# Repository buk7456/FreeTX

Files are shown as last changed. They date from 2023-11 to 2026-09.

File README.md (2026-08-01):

# FreeTX
Open source radio control system for almost anything.  
Remotely operate model airplanes, multicopters, helicopters, boats, land vehicles, robots, animatronics, etc.

## Main features
- 20 fully proportional RC channels, each encoded with 10 bits.
- Configurable RC channel output signal format.
- Update rate of 50x per second for all RC channels.
- Receiver binding, adjustable RF power, frequency hopping.
- Reverse, subtrim, endpoints, failsafe, dual rates and expo, custom curves, flight modes.
- Powerful mixer system, logical switches, function generators, counters, timers.
- Telemetry, alarms, warnings, notifications, home screen widgets, custom splash screen, etc.
- Model memory, I2C EEPROM and SD card supported. Model types, context-aware nomenclature.
- Intuitive user interface.

## Hardware and Schematics
The transmitter and receiver schematics can be found in the 'schematics' folder. 
The major components are
- 1x Atmega2560 microcontroller, 2x Atmega328p microcontrollers.
- 2x SX1276/77/78/79 or RFM95 based Lora modules. Other RF modules can possibly be used with some modifications to the source code.
- A 128x64 graphical LCD with KS0108 or ST7920 controller. Any other 128x64 LCD can however be used (provide own driver code).

<p align="left">
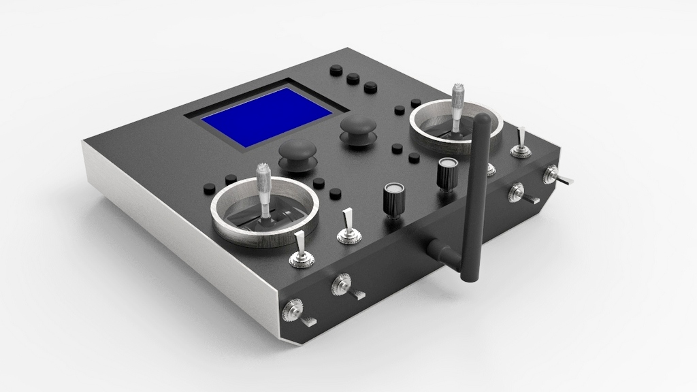
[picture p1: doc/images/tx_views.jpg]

</p>

## User interface
Three buttons are used for navigating the user interface i.e. Up, Select, Down. Long press Select to go Back.
<p align="left">

</p>

## User guide
[User guide](doc/user_guide.md)  

A PDF version is also available [here.](https://raw.githubusercontent.com/buk7456/FreeTX/main/doc/FreeTX%20-%20User%20manual.pdf)

## Gallery

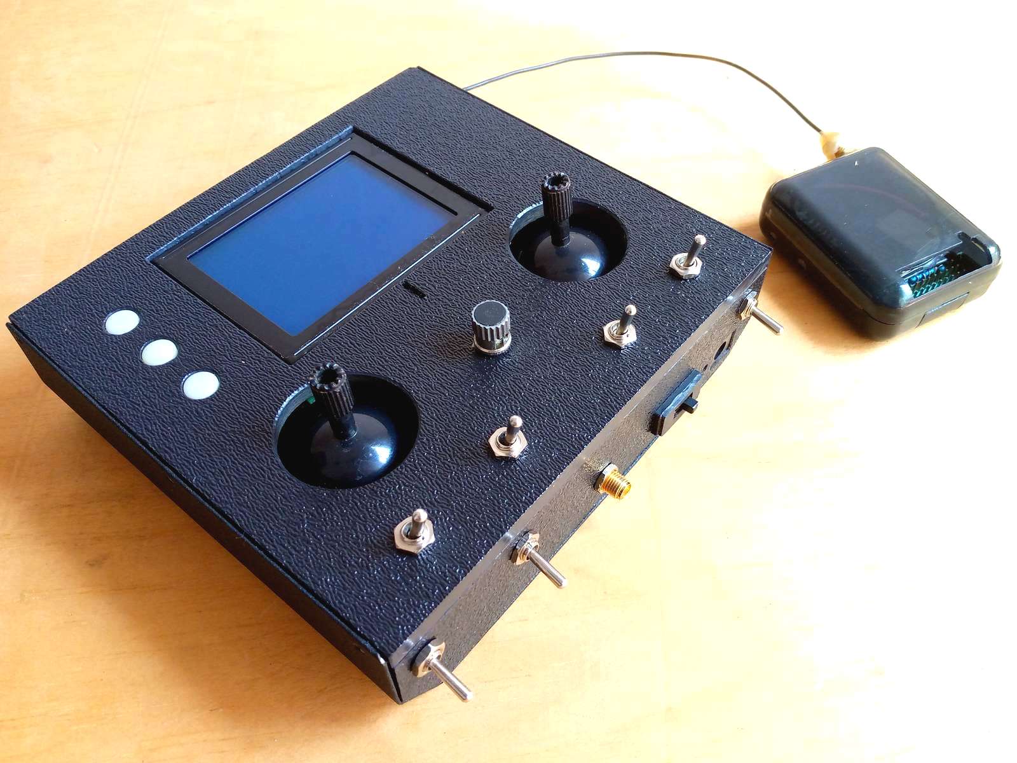
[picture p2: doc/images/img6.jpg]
[](doc/images/img6.jpg)
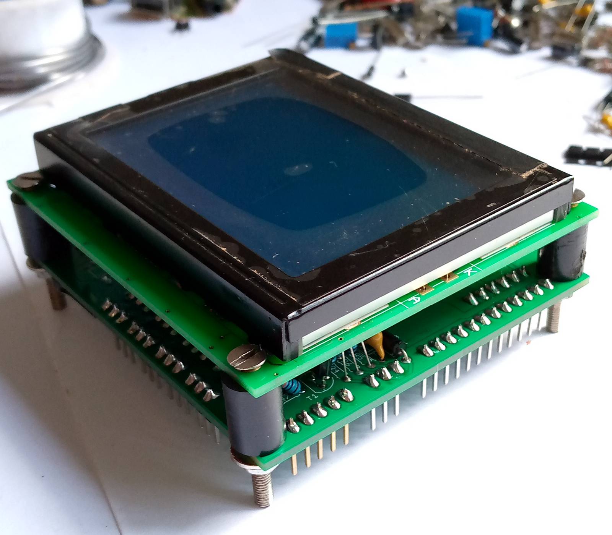
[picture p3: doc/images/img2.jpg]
[](doc/images/img2.jpg)
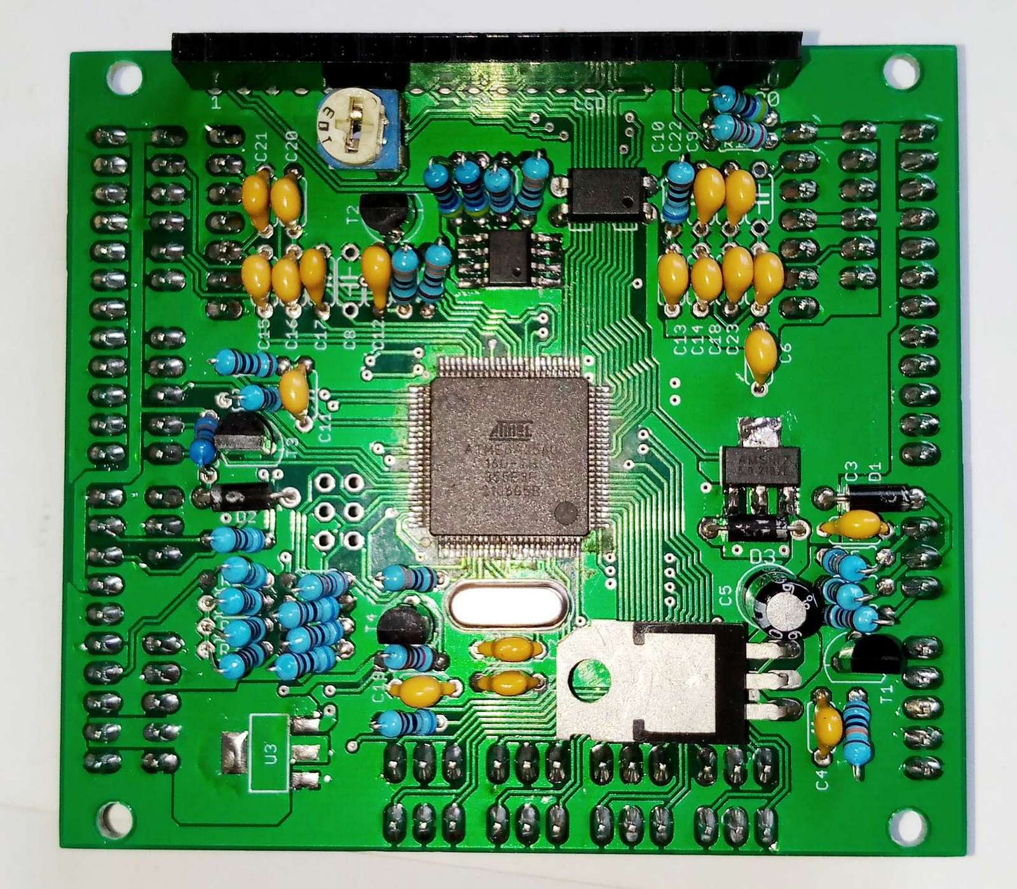
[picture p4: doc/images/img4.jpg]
[](doc/images/img4.jpg)
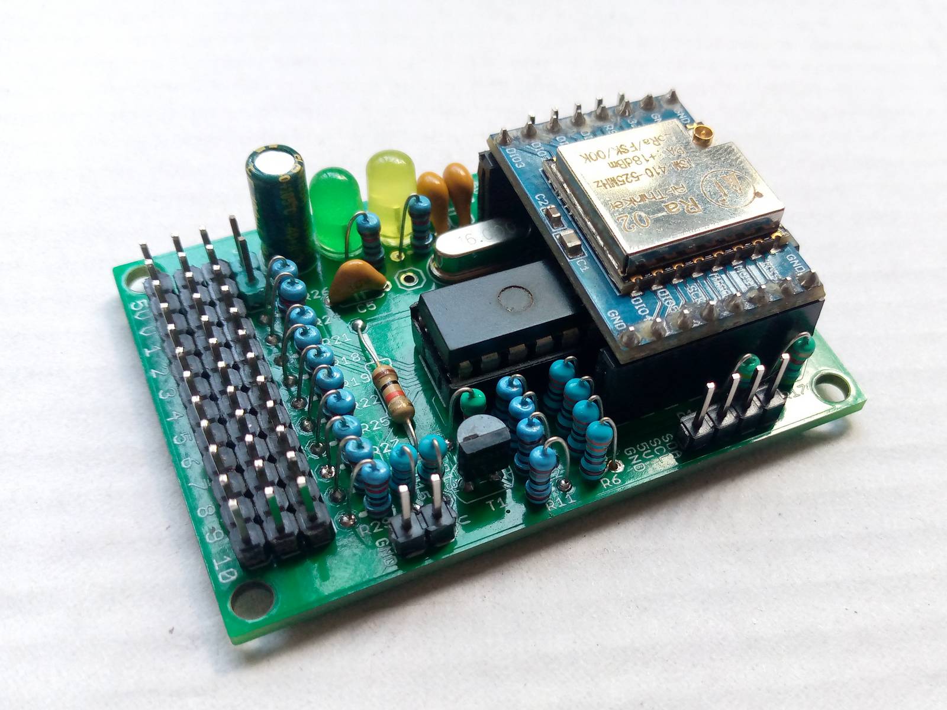
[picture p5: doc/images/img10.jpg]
[](doc/images/img10.jpg)
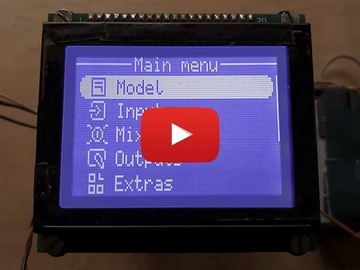
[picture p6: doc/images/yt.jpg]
[](https://www.youtube.com/watch?v=rDpRMRE8av0)
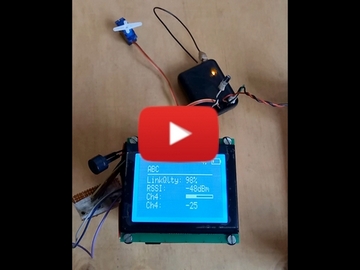
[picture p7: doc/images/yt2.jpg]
[](https://www.youtube.com/watch?v=9EZkyRHkMpg)

## Frequently Asked Questions
Got a question? [See the FAQ.](doc/faq.md)  

---

This project is based on an older project found [here.](https://github.com/buk7456/Arduino-LoRa-RC-transmitter-and-reciever)

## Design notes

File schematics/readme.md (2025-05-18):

This folder contains the EAGLE circuit schematics for the RC transmitter and receiver.

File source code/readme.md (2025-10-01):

This folder contains the source code of the firmware for the main (mtx) and secondary (stx) transmitter microcontrollers, as well as the receiver microcontroller.  
The code compiles on Arduino IDE 1.8.x or later. The code is self-contained so doesn't require installing any libraries.  
I highly recommend browsing or editing the code with an editor such as Visual Studio Code or Notepad++.  
If you are using the legacy Arduino 1.8.x IDE, you need to enable the "Use external editor" option.  
For VScode, simply open the folder (e.g. mtx) as project. For notepad++, use the "Open folder as workspace".

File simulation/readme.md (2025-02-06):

This folder contains the simulation file for use with SimulIDE circuit simulator.  
A Proteus VSM project file is also provided. Do not use the premade hex file with it, rather compile the main transmitter code and load it into Proteus.

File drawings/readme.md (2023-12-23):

Basic mechanical stuff. No detailed mechanical CAD files provided because of non-standard parts.  
Plan layouts for the front plate of the transmitter are provided only for guidance.

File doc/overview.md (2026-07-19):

# Overview

FreeTX is an open-source radio control system you can use for just about anything. It combines features from different RC systems and brings in new ideas too. It’s perfect for creators, hobbyists, and engineers. The main goal is to give you more freedom and choice with what you want to do.

## Default configuration

By default, the system is configured with the following features.

- 10 stick input axes, 8 switches, 2 knobs
- 40 mixer slots, 20 proportional RC channels
- 10 custom curves, 10 max points per curve
- 20 logical switches, 5 function generators, 3 timers, 5 counters
- 10 custom notifications 
- 5 flight modes
- 8 telemetry sensor slots

Many of these numbers are easily customisable in the source code, the limit being the available memory and I/O pins. 

## System architecture

### Transmitter hardware block diagram

<p align="left">
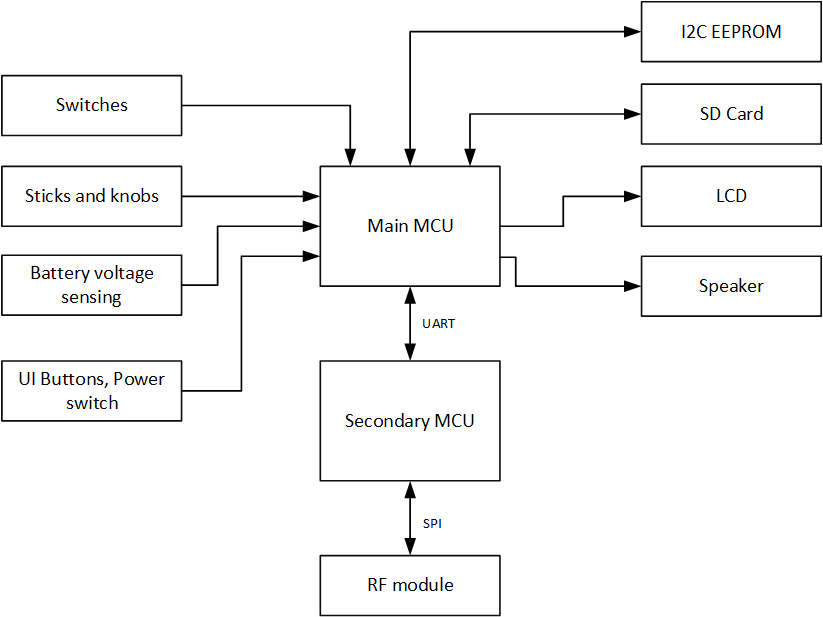
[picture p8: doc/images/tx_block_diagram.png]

</p>

### Receiver hardware block diagram

<p align="left">
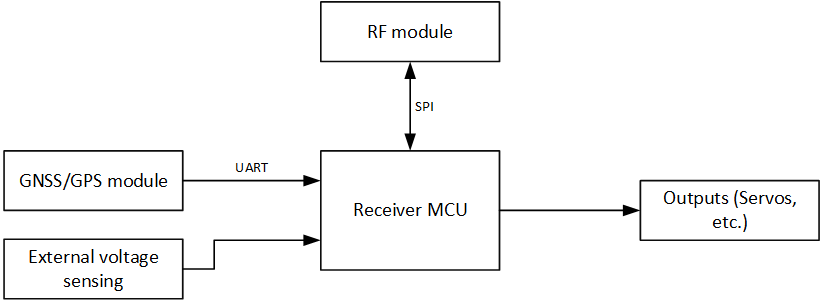
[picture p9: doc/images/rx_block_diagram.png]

</p>

## RF protocol

A custom RF protocol is used to communicate between the transmitter and receiver. The implementation builds on top of LoRa(R) transceivers. The documentation can be found in the Protocols folder.  
The main features are:-
- 10 bit encoding for all RC channels
- 50 Hz update rate for all RC channels
- Frequency Hopping Spread Spectrum
- Telemetry support

---

Back to [user guide](user_guide.md).

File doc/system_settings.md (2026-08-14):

# System settings

The System menu provides comprehensive configuration options so you can tailor the device to your needs. Settings are organized into categories for easy navigation and quick access to the options you want. Use this menu to adjust settings that affect overall system operation.

<p align="left">
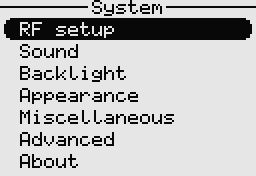
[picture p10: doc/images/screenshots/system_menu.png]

</p>

- [RF setup](#section_id_rf_setup)  
- [Sound](#section_id_sound)  
- [Backlight](#section_id_backlight)  
- [Appearance](#section_id_appearance)  
- [Miscellaneous](#section_id_miscellaneous)  
- [Advanced](#section_id_advanced_settings)  
  - [Sticks](#section_id_sticks)  
  - [Knobs](#section_id_knobs)  
  - [Switches](#section_id_switches)  
  - [Battery](#section_id_battery)  
  - [Security](#section_id_security)  
  - [Debug](#section_id_debug)  
- [About](#section_id_about)

## RF setup 

<p align="left">
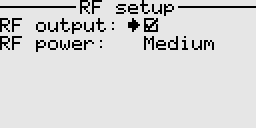
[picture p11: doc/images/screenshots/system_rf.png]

</p>

- **RF output:** Toggle the RF transceiver on or off. When enabled, an RF icon appears on the home screen. RF output is automatically disabled when switching to a different model for safety, thus it has to be re-enabled manually after changing models.
- **RF power:** Adjust the transceiver's transmission power. Higher power increases range but uses more battery.

## Sound

<p align="left">
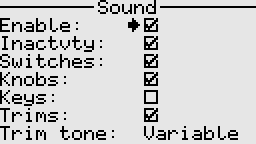
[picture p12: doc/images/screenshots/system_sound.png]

</p>

- **Enable:** Toggle all sounds on or off. When off, a mute icon appears on the home screen. Holding the Down key while powering on will also mute all sounds.
- **Inactivity:** Turn the inactivity alarm on or off. When enabled, a warning tone plays after a period without user interaction.
- **Switches:** Play a tone when any physical switch is moved.
- **Knobs:** Play a tone when a knob with a center detent is positioned at center.
- **Keys:** Play a tone when the physical UI buttons are pressed.
- **Trims:** Play a tone while trims are being adjusted.
- **Trim tone:** Set the trim tone behaviour. Fixed pitch (single frequency) or Variable pitch (changes with trim position).

## Backlight

<p align="left">
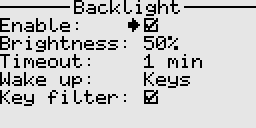
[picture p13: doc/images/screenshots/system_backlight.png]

</p>

- **Enable:** Enables/disables the backlight. This may be useful for example to save energy on certain kinds of LCDs.
- **Brightness:** Controls the brightness level of the display. Higher brightness causes higher battery consumption.
- **Timeout:** Specifies the time before the backlight is turned off when the handset is inactive.
- **Wake up:** Specifies how the backlight is triggered on. Keys or Activity. When set to Keys, only the UI keys can wake up the backlight. Setting to Activity enables all the physical controls to wake up the backlight. This is useful when we want the backlight to stay on when operating a model, especially for LCDs that are not sunlight readable.
- **Key filter:** When enabled, the first key press only wakes the backlight without triggering any event in the User Interface. This setting is useful for LCDs that are not sunlight readable.

## Appearance

<p align="left">
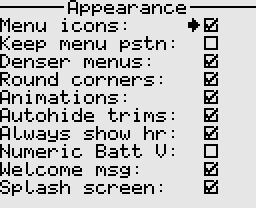
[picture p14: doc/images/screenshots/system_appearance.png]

</p>

- **Menu icons:** Show or hide icons in the main menu.
- **Keep menu position:** Whether to remember the scroll position in the major menus (Main menu, System, Extras, etc.). This setting does not apply to context menus.
- **Denser menus:** Increases the number of entries shown in the major menus.
- **Round corners:** Turns on/off rounded corners in menus, dialog boxes, etc.
- **Animations:** Turns animations on/off for toast messages, loading spinners, etc.
- **Autohide trims:** Hides the trim bars on the home screen when the trims buttons are not being interacted with.
- **Always show hours:** Whether to always show the hours digits for timers.
- **Numeric battery voltage:** Replaces the graphical battery gauge with the actual voltage readout on the home screen.
- **Welcome message:** Turns on/off the "Welcome" message when starting up the handset. 
- **Splash screen:** Whether to show the user's custom splash screen during boot.  
To make a custom splash screen, create a monochrome bitmap image with 128x64 px resolution and save it as "SPLASH.BMP" inside the "IMAGES" folder on the SD card.

## Miscellaneous

<p align="left">
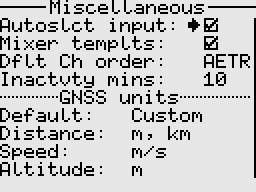
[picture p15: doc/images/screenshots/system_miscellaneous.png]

</p>

- **Autoselect input:** This enables automatic detection of the moved physical control when editing sources or switches, so that we can quickly select the desired control without having to scroll through the options.
- **Mixer templates:** Whether to enable the default mixer template when creating new models. Turning off this also removes the entry from the mixer context menu.
- **Default channel order:** Specifies the default channel order when creating new models. E.g., selecting AETR sends Ail to Ch1, Ele to Ch2, Thr to Ch3, and Rud to Ch4 in the mixer. The order can always be overridden in the mixer; this option is merely a time saving feature for new models.
- **Inactivity minutes:** How long before the inactivity event is triggered, specifically for the inactivity alarm.
- **Default GNSS units:** Specifies the default units of measurement to use when adding the GNSS telemetry sensor template.
Available options are Metric, Imperial, Custom, or None.  
When set to Custom, the user can set custom defaults for Distance, Speed, and Altitude.  
When set to None, the system prompts the user to select units whenever adding the GNSS sensor.

# Advanced settings

This menu provides access to various advanced system settings. It is protected with a password (if set) to prevent unwanted configuration changes, for instance when we lend out the transmitter. 

<p align="left">
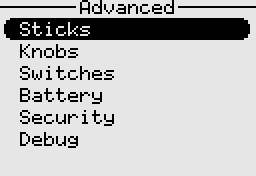
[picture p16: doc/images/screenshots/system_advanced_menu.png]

</p>

## Sticks

<p align="left">
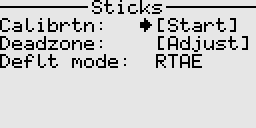
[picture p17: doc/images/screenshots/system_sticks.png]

</p>

- **Calibration:** This starts the stick calibration process.
- **Deadzone:** This allows to adjust the center deadzone for the stick axes, without re-triggering full calibration.
- **Default mode:** This determines the default stick axis mapping for the Aileron/Roll, Elevator/Pitch, Rudder/Yaw, and Throttle inputs. It is essentially called "Stick mode" in other RC systems.

### Calibrating the sticks

<p align="left">
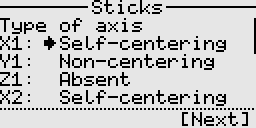
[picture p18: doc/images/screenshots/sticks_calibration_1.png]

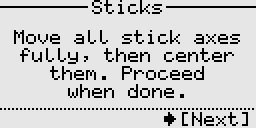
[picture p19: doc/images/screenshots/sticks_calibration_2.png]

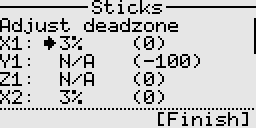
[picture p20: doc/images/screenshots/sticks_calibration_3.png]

</p>

**Procedure:**
- Select the axis type: Self-centering (returns to the center), Non-centering or Absent.
- Move each stick axis through its full range. If an axis is self-centering, release it and let it return to center.
- Set the deadzone percentage. This applies around the center to prevent jitter when the stick is centered.

Properly calibrated stick axes always read between -100 to 100 when moved fully. If this is not the case, then redo the calibration, or check your hardware.  
  
How often you need to recalibrate the sticks depends on their build quality and how frequently you use the device. As a guideline, recalibrate:
- After any noticeable drift or inconsistent input.
- After major firmware updates or hardware changes.

## Knobs

<p align="left">
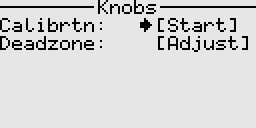
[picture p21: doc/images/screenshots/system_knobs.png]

</p>

- **Calibration:** This starts the knob calibration process.
- **Deadzone:** This allows to adjust the center deadzone for the knobs, without re-triggering full calibration.

### Calibrating the knobs

<p align="left">
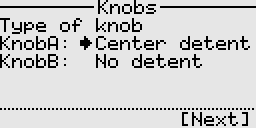
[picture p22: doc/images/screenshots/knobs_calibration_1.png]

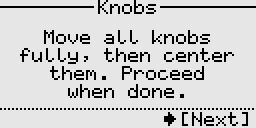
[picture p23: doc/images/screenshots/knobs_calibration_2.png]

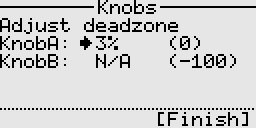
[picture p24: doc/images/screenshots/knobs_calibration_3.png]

</p>

**Procedure:**
- Select the knob type: Center detent (mechanical stop at center), No detent, or Absent.
- Rotate each knob through its full range. If a knob has a center detent, return it to the detent position.
- Set the deadzone percentage. Deadzone is applied around the center to prevent jitter when the knob is centered.

Properly calibrated knobs always read between -100 to 100 when moved fully. If this is not the case, then redo the calibration, or check your hardware.

## Switches

This screen allows the user to specify the type of switches they have installed. Supported types are 2 position, 3 position, and their momentary variants. A frequent question is "How about push buttons?". Well, they are actually 2 position momentary switches.

<p align="left">
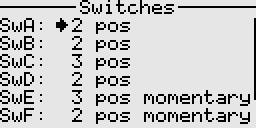
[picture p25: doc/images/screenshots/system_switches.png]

</p>

## Battery

<p align="left">
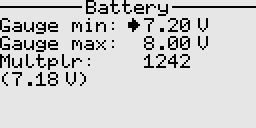
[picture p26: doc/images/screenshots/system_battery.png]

</p>

- **Gauge min and max:** These determine the range of the transmitter battery gauge. The minimum value also serves at the alarm threshold value, below which a low battery warning is shown. 
- **Multiplier:** This specifies the calibration factor for the transmitter battery voltage.

### Calibrating the battery gauge
To calibrate the battery gauge, use a digital multimeter to measure the actual battery voltage at the terminals. Then adjust the multiplier until the displayed voltage on the transmitter matches what the multimeter is showing. 

## Security
<p align="left">
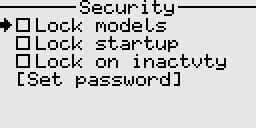
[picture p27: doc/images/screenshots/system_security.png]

</p>

- **Lock models:** Locks the model manager screen, preventing access to the models.
- **Lock startup:** Locks the main menu on startup, effectively preventing changes to all settings (both model and system), unless the correct password is entered.
- **Lock on inactivity:** Locks the main menu after the system has been idle for the specified inactivity minutes. This setting applies only while the home screen is being displayed.
- **Set/Change password:** Opens the text edit dialog to edit the password. To remove the existing password, simply clear the field. Setting a password also protects the Advanced system menu.

## Debug

The Debug menu contains options intended primarily for troubleshooting, development, testing, and debugging.

<p align="left">
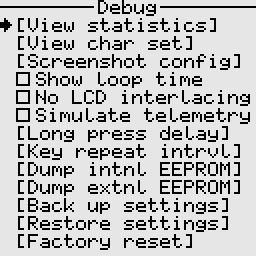
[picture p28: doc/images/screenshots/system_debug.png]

</p>

- **View statistics:** Displays basic system statistics, including system uptime, available free memory, and RF packet rate.
- **View character set:** Displays all glyphs included in the system font.
- **Screenshot configuration:** Assigns a physical switch to trigger screenshot capture.
- **Show loop time:** Displays the total execution time of the main program loop, measured in milliseconds.
- **No LCD interlacing:** Disables interlacing for the LCD screen. (Interlacing improves performance on slower displays by splitting the image into alternate frames and updating them across successive program loops.)
- **Simulate telemetry:** Simulates telemetry data on sensor ID 0x30 for testing purposes.
- **Long press delay:** Sets the duration that a physical button must be held before a long-press event is recognized. This setting applies to both UI buttons and trim buttons.
- **Key repeat interval:** Sets the time interval between repeated key events when scrolling through menus and some options, effectively determining the scrolling speed.
- **Dump EEPROM:** Displays a hexadecimal dump of the EEPROM contents.
- **Back up settings:** Backs up system settings to the SD card. Model-specific settings are not included in this backup.
- **Restore settings:** Restores system settings from the SD card.
- **Factory reset:** Erases all system and model settings, restoring the device to its factory default state. Only data in the EEPROM gets erased; data on the SD card is not affected.

## About

The About menu provides information regarding firmware version, legal notices, credits, and support/contact resources.

<p align="left">
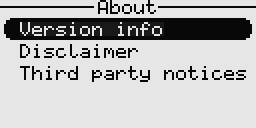
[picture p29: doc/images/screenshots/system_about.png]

</p>

---

Back to [user guide](user_guide.md).

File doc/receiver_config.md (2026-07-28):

# Receiver 
Each receiver supports up to 10 channels. To use all the 20 channels, two receivers are required.

<p align="left">
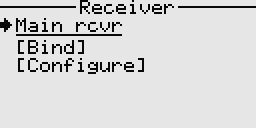
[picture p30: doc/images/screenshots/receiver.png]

</p>

## Binding to a receiver
A receiver can be bound as either a main receiver or a secondary receiver.  
By default, RC channels 1 to 10 are handled by the main receiver, while RC channels 11 to 20 are handled by the secondary receiver. Only the main receiver can send back telemetry.  
To bind, select the bind option, then cycle the power to the receiver. If the binding is successful, a "Success" toast message will be shown and a tune played.

## Configuring receiver outputs
The receiver outputs can be configured from the transmitter to any of the three signal types; 
servo PWM, digital on-off, or 'normal' PWM. 
For example 'normal' PWM output can be used to control brushed DC motors without the need for 
complex electronics. The digital on-off output makes it easy to directly control components such as 
electromechanical relays and lights.  
The servo PWM range can as well be adjusted to get extra travel from a servo, without making physical
modifications to the servo.

<p align="left">
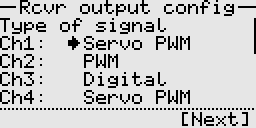
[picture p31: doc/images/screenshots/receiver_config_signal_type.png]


</p>

**Note:**  
1. These configuration settings are stored in the receiver, not the transmitter.
2. Normal PWM is only available on certain pins, depending on the pin mapping.
3. Any changes made take effect immediately upon pressing the 'Write' button.
4. In digital on-off mode, the output value range of -100 to -50 corresponds to LOW, -49 to 49 is 
ignored, and 50 to 100 corresponds to HIGH.
5. When reusing a receiver between models, always check and set the appropriate signal format before connecting 
any actuators to the receiver.

---

Back to [user guide](user_guide.md).

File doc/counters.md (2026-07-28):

# Counters
A counter stores and shows the number of times a particular event has occurred, in relationship to a clock signal.

<p align="left">


</p>

- **Clock:** The control switch that triggers the counter.
- **Edge:** Rising, Falling, or Dual edge triggering. Applies to the clock signal.
- **Clear:** The control switch that clears the counter register to zero.
- **Modulus:** The number of states in its count sequence. E.g. mod 4 produces the sequence 0, 1, 2, 3.
- **Direction:** Determines whether counts will increment or decrement.
- **Rollover:** Rolls back over to start counting again from zero.
- **Persist:** Whether to remember the value in the counter's register between sessions.

In advanced mode, the counter behaves as an up/down counter using separate "up" and "down" clocks for increment and decrement respectively.

## Usage examples
[1. Using a 3 position momentary switch to sequentially select among values](#section_id_select_among_values_with_momentary_switch)  
[2. Using a 3 position momentary switch to continuously adjust a value](#section_id_continuously_adjust_value_with_momentary_switch)  

### Example 1: Using a 3 position momentary switch to sequentially select among values
This example demonstrates use of the counter directly inside the mixer.  
When the momentary switch is pushed in the downward direction, the counter value increments. Similarly, pushing the momentary switch in the opposite direction decrements the counter value.  
In the counter screen context menu, change the counter type to advanced.  
Assuming SwG is our 3 position momentary switch, set up the counter as follows.

```txt
Counter1
Inc clock:  SwG_down
Inc edge:   Rising
Dec clock:  SwG_up
Dec edge:   Rising
Modulus:    4
Rollover:   False
```

Then in the Mixer,

```txt
1. Ch1  Add  Counter1  (Weight 100)
```

The mixer automatically maps the counter's value in proportion to the counter's modulus. For example if the modulus is 4, then mapping is {(0,-100), (1,-33), (2,33), (3,100)}.

### Example 2: Using a 3 position momentary switch to continuously adjust a value
When the switch is pushed in one direction, the counter continuously increments until the switch is released. Similarly, the counter continuously decrements
when the switch is pushed in the opposite direction.  
For this, we set up some logical switches, like so.

```txt
L1
Functn: AND
Value1: !L1
Value2: SwG_down

L2
Functn: AND
Value1: !L2
Value2: SwG_up
```

In the above, we are essentially creating ring oscillators, though with only a single NOT stage.  
This exploits the fact that the main program loop runs at about 50 times per second, thus we generate oscillations of about 25 Hz frequency.  
We then use L1 and L2 to clock the counter as follows.

```txt 
Counter1
Inc clock:  L1
Inc edge:   Rising
Dec clock:  L2
Dec edge:   Rising
Modulus:    100
Rollover:   False
```

Here, the modulus can be any value. For example if the modulus is 100, it will take 4 seconds (=100/25) to increment from 0 to 99.  

We then use the counter as input inside the Mixer like follows. 

```txt  
1. Ch1  Add  Counter1  (Weight 100)
```

The mixer automatically maps the counter's value in proportion to the counter's modulus, to the range -100 to 100.  
We can also specify some "slow up/down" of 4 seconds in the mixer to smooth the output.

Alternatively, we can adapt this example to use a self-centering stick axis like X4, instead of the momentary switch.

---

Back to [user guide](user_guide.md).

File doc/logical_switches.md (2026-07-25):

# Logical switches
These can be used to combine various conditions, compare values, etc. They are in essence user
programmed virtual switches. They produce an on/off output.

<p align="left">

</p>

The available functions can be categorized into the following types.
- Comparators (Greater than, Less than, Equal, Greater than or equal, Less than or equal)
- Combinational (AND, OR, XOR)
- Latches (SR latch)
- Flip-flops (Toggle)
- Generators (Pulse)

## Usage examples

[1. A mix activated by combination of two switches](#section_id_mix_activated_by_two_switches)  
[2. LED lights that flash when flight battery is low](#section_id_led_lights_flashing_low_battery)  
[3. Stopwatch operated by a single momentary switch](#section_id_stopwatch_with_momentary_switch)  
[4. Throttle timer - simple](#section_id_throttle_timer_simple)  
[5. Throttle timer - advanced](#section_id_throttle_timer_advanced)  
[6. Zero crossing detection](#section_id_zero_crossing_detection)  
[7. Using a momentary switch to cycle among values](#section_id_cycle_among_values_with_momentary_switch)  
[8. Detecting receiver connection or disconnection ](#section_id_detect_disconnection_of_receiver)  

### Example 1: A mix activated by combination of two switches
Suppose we want a mix to be turned on only when two switches (e.g. SwA, SwB) are both on. 
We need to set up a logical switch say L1 as follows.

```txt
L1
Functn: AND
Value1: SwA_down
Value2: SwB_down
```
Then in the mixer, we simply have to set the control switch to L1.

### Example 2: LED lights that flash when flight battery is low
Suppose we have a model that is equipped with some LED lights that we want to switch on when the flight battery
voltage (telemetry) falls below a certain threshold for more than say five seconds.
<br>We can easily achieve this like so.

```txt
L1
Functn: a<x
Value1: FlghtBatt
Value2: 10.80 V
Delay:  5.0 s

L2
Functn: Pulse
Width:  1.0 s
Period: 2.0 s
``` 
Then in the mixer, we simply use L2 as the input source and L1 as the control switch for the mix, to
operate the channel assigned to the LED lights.

### Example 3: Stopwatch operated by a single momentary switch for start/stop and reset
When the switch is clicked, the timer runs/stops. When the switch is held long enough, the timer is
reset. 
<br>For this, we set up two logical switches to operate the timer as below, assuming SwH is our momentary switch.

```txt
L1
Functn: Toggle
Clock:  SwH_down
Edge:   Falling
Clear:  L2

L2
Functn: a>x
Value1: SwH
Value2: 0
Delay:  0.5 s

Timer1
Switch: L1
Reset:  L2
```

Explanation:  
The output of L1 toggles whenever SwH is released. L1 is then used to run/stop the timer.  
L2 goes high when SwH is down for more than 0.5 seconds, providing a signal for resetting the timer.
L2 is also used to clear the state of L1 such that resetting the timer does not falsely trigger it to run on releasing the switch.

### Example 4: Throttle timer (simple)
When the throttle is moved beyond a certain threshold, the timer runs.  
Also if we have a throttle cut function on say SwA, we want the timer to only run when throttle cut is inactive.  
Assume the throttle source is the Y1 axis.

```txt
L1
Functn: a>x
Value1: Y1
Value2: -90

L2
Functn: AND
Value1: L1
Value2: SwA_down

Timer1
Switch: L2
```

### Example 5: Throttle timer (advanced)
Suppose we want the speed at which the timer runs to be proportional to the throttle value.  
Also if we have a throttle cut function on say SwA, we want the timer to only run when throttle cut is inactive.  
Assume our throttle source is the Y1 axis. 

#### Method 1: 
Using the built-in function generator to generate a pulse width modulated signal that controls the timer.

```txt
Fgen1
Waveform:   Pulse
Width mode: Variable
Modulator:  Y1
Reverse:    False
Period:     1.0 s

L1
Functn: a>x
Value1: Fgen1
Value2: 0

L2
Functn: AND
Value1: L1
Value2: SwA_down

Timer1
Switch: L2
```

Explanation:  
The throttle source (Y1 axis) is used to modulate the pulse width of the generated pulse waveform.  
Since the timer only accepts signals from control switches, we need to convert the output from the function generator. This is done via L1.  
When SwA is in the down position, the resulting signal is passed to the timer to control it.

#### Method 2:
Using the mixer and a virtual channel to create a pulse width modulated signal that controls the timer.

```txt
Mixer
1. Virt1  Add  L1 (Weight 99, SlowUp 0.5 s, SlowDown 0.5 s)

L1
Functn: Pulse
Width:  0.5 s
Period: 1.0 s

L2
Functn: a>b
Value1: Y1
Value2: Virt1

L3
Functn: AND
Value1: L2
Value2: SwA_down

Timer1
Switch: L3
```
Explanation:  
L1 and Virt1 effectively create a triangle waveform, which gets compared with the value of the throttle source (Y1 axis) via L2.
When SwA is in the down position, the resulting signal is passed to the timer to control it.

If desired, we can also include a custom curve through a virtual channel, to compensate for the real world
nonlinear relationship between current draw and throttle value. 

### Example 6: Zero crossing detection
Suppose we want to detect whenever a value from say a function generator crosses zero, so that 
we can trigger some other action.

```txt
L1
Functn: a>=x
Value1: Fgen1
Value2: 0

L2
Functn: |delta|>x
Value1: L1
Value2: 0
Dirctn: Both
```

L2 will now output a brief pulse whenever the output of the function generator crosses zero.

### Example 7: Using a momentary switch to cycle among four values or states
Suppose we want an output channel to cycle among four levels whenever we click the momentary switch.

#### Method 1:
Set up a '2-bit' binary counter with its outputs on L2 and L1 as follows.

```txt
L1
Functn: Toggle
Clock:  SwH_down
Edge:   Rising 

L2
Functn: Toggle
Clock:  L1
Edge:   Falling
```

Use a truth table to set up logical switches L3, L4, L5, and L6

| L2 | L1 | |
|----|----|----|
| 0  | 0  | L3 |
| 0  | 1  | L4 |
| 1  | 0  | L5 |
| 1  | 1  | L6 |

```txt
L3
Functn: AND
Value1: !L2
Value2: !L1

L4
Functn: AND
Value1: !L2
Value2: L1

L5
Functn: AND
Value1: L2
Value2: !L1

L6
Functn: AND
Value1: L2
Value2: L1
```

Then in the Mixer,

```txt
1. Ch1  RplcW  Max  (Weight -100,  Switch L3)
2. Ch1  RplcW  Max  (weight -33,   Switch L4)
3. Ch1  RplcW  Max  (weight  33,   Switch L5)
4. Ch1  RplcW  Max  (weight  100,  Switch L6)
```
#### Method 2:
This makes use of the built-in counter as follows.

```txt
Counter1
Clock:   SwH_down
Edge:    Rising
Modulus: 4
Dirctn:  Up

L3
Functn: a==x
Value1: Counter1
Value2: 0

L4
Functn: a==x
Value1: Counter1
Value2: 1

L5
Functn: a==x
Value1: Counter1
Value2: 2

L6
Functn: a==x
Value1: Counter1
Value2: 3
```
Then in the Mixer,

```txt
1. Ch1  RplcW  Max  (Weight -100,  Switch L3)
2. Ch1  RplcW  Max  (weight -33,   Switch L4)
3. Ch1  RplcW  Max  (weight  33,   Switch L5)
4. Ch1  RplcW  Max  (weight  100,  Switch L6)
```

#### Method 3:
This makes use of the built-in counter directly in the Mixer. [See the example](./counters.md#section_id_select_among_values_with_momentary_switch) under counters.  

### Example 8: Detecting receiver connection or disconnection
This relies on the Link Quality telemetry to detect connection/disconnection of a receiver.  
First, configure the Link Quality telemetry (premade template already available).  
Then set up a logical switch and custom notifications as follows.

```txt
L1
Functn: a>x
Value1: LinkQlty
Value2: 0

Notification1
Switch: L1
Tone:   (Your preferred tone)
Text:   RX connect

Notification2
Switch: !L1
Tone:   (Your preferred tone)
Text:   RX disconnect
```

This example can also be adapted to detect when telemetry from a sensor is lost or recovered.

---

Back to [user guide](user_guide.md).

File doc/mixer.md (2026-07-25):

# The Mixer
The mixer is where the inputs (mixer sources) get linked to the output channels (servos, etc.).
This controller features a mixer system that draws inspiration from that found in OpenTX(R) based RC transmitters, though not directly compatible.

<p align="left">


</p>

## Mixer fields
- **Output:** The channel that is to be affected by the mix. If none, the mix is inactive and is not computed.
- **Switch:** The control switch to turn the mix on or off. The mix is always active if no switch is specified.
- **Operation:** Add, Multiply, Replace with, Hold.
- **Input:** This is the mixer source.
- **Weight:** Determines how much of an effect the input has on the output. -100 to 100.
- **Offset:** The input is offset by this value after the weight has been applied. -100 to 100.
- **Curve:** Differential, Expo, Function, Custom curve.
- **Curve value:** Differential {-100 to 100}, Expo {-100 to 100}, Function {x>0, x<0, |x|}, Curve name if custom curve.
- **Trim:** Whether to add trim or not.
- **F-Mode:** The flight mode in which the mix applies.
- **Delay Up and Down:** This is used to delay the input. 0 to 60 seconds.
- **Slow Up and Down:** This when non-zero specifies how fast the input changes. 0 to 60 seconds.

## Mixer sources
Mixer sources can be any of the following:
- Raw stick axes (X1, Y1, X2, Y2, etc.)
- Processed sticks (Rud/Yaw, Thr, Ail/Roll, Ele/Pitch)
- Knobs (KnobA, KnobB)
- Constants (Max)
- Function generators (Fgen1, Fgen2, etc.)
- Trims (X1Trim, Y1Trim, X2Trim, Y2Trim)
- Physical switches (SwA, SwB, etc.)
- Logical switches (L1, L2, etc.)
- Channels (Ch1, Ch2, etc.)
- Virtual channels (Virt1, Virt2, etc.)

Counters can also be used as inputs in the mixer, although they are not classified as true mixer sources.

## Control switches
These can be used to activate or deactivate various functions, for example enabling or disabling mixes, starting or stopping timers, and more. The following control switches are available:
- Physical switches (SwA↑, SwA−, SwA↓, etc.)
- Logical switches (L1, L2, !L1, !L2, etc.)
- Trim buttons (X1Trim←, X1Trim→, Y1Trim↑, Y1Trim↓, etc.)
- Flight modes as control switches (Fmd1, Fmd2, !Fmd1, !Fmd2, etc.)

The symbols "↑", "−", and "↓" correspond to the up, middle (center), and down positions of physical switches, respectively.  
The "↑" and "↓" symbols are also used on vertical trim buttons to indicate an active upward or downward press.  
The "←", and "→" symbols also denote the left and right press states of the horizontal trim buttons.  
The "!" symbol indicates a logical NOT operator. For example, the condition "!SwC↑" evaluates as true when SwC is not in the up position.

## Order of mixer operations
<p align="left">

</p>

## Context menu actions
- **View outputs:** Opens the mixer monitor, which shows the real-time status of all output channels. Click the Select button within this monitor to view a tooltip containing the exact value of the selected channel.
- **Copy mix to:** Copies this mix to a specified destination.
- **Move mix to:** Moves this mix to a specified destination.
- **Insert free:** Inserts a free mix slot at the current position.
- **Rename mix:** Opens the text editor dialog to specify a name for this mix.
- **Reset mix:** Resets this mix to the default setting.
- **Reset all mixes:** Resets all mixes to the default settings.
- **Compact mixes:** Removes all empty/free slots that exist in-between the defined mixes.
- **Show curve preview:** Whether to draw the curve on the mixer screen. The displayed curve shows a trace of the output vs input for this specific mix.
- **Templates:** Use this option to load the predefined mixer templates.
- **Show overview:** Display a summary of the configured mixes. In the overview screen, click the Select button to display a tooltip with extra information about the highlighted mix line.

## Important safety note
When editing mixes, it is recommended to disable RF output or remove propellers first. This is because all changes/adjustments made are applied instantly and may bring surprises.

## Example mixes
**Note:** 
- The convention used in these examples is negative for left/downward going control surfaces, positive for right/upward going control surfaces. For example if the Ail stick is moved right, the left aileron moves down and the right aileron moves up. Hence we use a negative weight for the left aileron and a positive weight for the right aileron.
- If a servo is moving in wrong direction, reversing the direction in Outputs screen solves this.
- The Mixer is all about control logic. Any mechanical differences should be handled in the Outputs screen and not inside the Mixer.

[1. Basic 4 channel](#section_id_basic_4_channel)  
[2. Elevon](#section_id_elevon)  
[3. Vtail](#section_id_vtail)  
[4. Aileron differential](#section_id_aileron_differential)  
[5. Tailerons](#section_id_tailerons)  
[6. Flaperons](#section_id_flaperons)  
[7. Crow braking](#section_id_crow_braking)  
[8. Flaps working as ailerons](#section_id_flaps_as_ailerons)  
[9. Differential thrust](#section_id_differential_thrust)  
[10. Throttle elevator mixing](#section_id_throttle_elevator_mix)  
[11. Variable steering depending on throttle](#section_id_variable_steering)  
[12. Adjust idle throttle with knob](#section_id_adjust_throttle_idle)  
[13. Adjust maximum throttle with knob](#section_id_adjust_max_throttle)  
[14. Simple throttle cut](#section_id_simple_throttle_cut)  
[15. Sticky throttle cut](#section_id_stick_throttle_cut)  
[16. Landing gear sequencer](#section_id_landing_gear_sequencer_v1)  
[17. Landing gear sequencer - advanced](#section_id_landing_gear_sequencer_v2)  
[18. Servo tester](#section_id_servo_tester)  
[19. Random servo motion generator](#section_id_random_servo_motion_generator)  
[20. Random servo motion generator - advanced](#section_id_random_servo_motion_advanced)  
[21. Oscillator from scratch](#section_id_oscillator_from_scratch)  
[22. Automatic aileron rudder mixing](#section_id_automatic_aileron_rudder_mix)  
[23. Adjust aileron differential with knob](#section_id_adjust_aileron_differential_with_knob)  

### Example 1: Basic 4 channel
Assuming Aileron servo in Ch1, Elevator servo in Ch2, Throttle in Ch3, Rudder servo in Ch4
```txt
1. Ch1  Add  Ail (Weight 100)
2. Ch2  Add  Ele (Weight -100)
3. Ch3  Add  Thr (Weight 100)
4. Ch4  Add  Rud (Weight 100)
```

### Example 2: Elevon
Left servo in Ch1, right servo in Ch2
```txt
1. Ch1  Add  Ail (Weight -50)
2. Ch1  Add  Ele (Weight -50)
3. Ch2  Add  Ail (Weight 50)
4. Ch2  Add  Ele (Weight -50)
```

### Example 3: Vtail
Left servo in Ch2, right servo in Ch4
```txt
1. Ch2  Add  Rud (Weight 50)
2. Ch2  Add  Ele (Weight -50)
3. Ch4  Add  Rud (Weight -50)
4. Ch4  Add  Ele (Weight -50)
```

### Example 4: Aileron differential
Left aileron in Ch1, right aileron in Ch8. We want the downward going aileron to get less displaced
than the upward going aileron. Due to differences in lift and air pressure on the top and bottom wing surfaces, 
the aileron surface produces more drag when it moves down than when it moves up. This tends to cause 
an adverse yaw effect hence the need for aileron differential.
```txt
1. Ch1  Add  Ail (Weight -100, Diff 30)
2. Ch8  Add  Ail (Weight 100, Diff 30)
```

### Example 5: Tailerons
Left Elevator servo in Ch6, Right Elevator servo in Ch7. The mix is turned on/off with SwG.
```txt
1. Ch6  Add  Ele (Weight -60)
2. Ch6  Add  Ail (Weight -40, Switch SwG_Down)
3. Ch7  Add  Ele (Weight -60)
4. Ch7  Add  Ail (Weight 40, Switch SwG_Down)
```

### Example 6: Flaperons
Left aileron in Ch1, right aileron in Ch8. Using SwC to operate the flaperons. 
<br>When SwC is in upper position, flaperons are off. In middle position half flaperons, 
and in lower position full flaperons.
<br>For smooth flaperon deployment, we use the slow up/down feature.
```txt
1. Ch1  Add  Ail (Weight -100, Diff 30)
2. Ch1  Add  SwC (Weight -40, Offset -40, SlowUp 1 s, SlowDown 1 s)
3. Ch8  Add  Ail (Weight 100, Diff 30)
4. Ch8  Add  SwC (Weight -40, Offset -40, SlowUp 1 s, SlowDown 1 s)
```

### Example 7: Crow braking 
Left ail servo in Ch1, Right Ail servo in Ch8, left flap servo in Ch5, right flap servo in Ch6.
<br>Using the three position SwC for operation. Normal aileron action occurs when SwC is in upper or middle position. 
Half flaps are deployed when SwC is in middle position. When SwC is in lower position, both ailerons 
move upward and full flaps are deployed.
```txt
1. Ch1   Add  Ail (Weight -100, Diff 30)
2. Ch1   Add  SwC (Weight 60, Func x>0, SlowUp 1 s, SlowDown 1 s)
3. Ch8   Add  Ail (Weight 100, Diff 30)
4. Ch8   Add  SwC (Weight 60, Func x>0, SlowUp 1 s, SlowDown 1 s)
5. Ch5   Add  SwC (Weight -50, Offset -50, SlowUp 1 s, SlowDown 1 s)
6. Ch6   Add  Ch5 (Weight 100)
```

### Example 8: Flaps working as ailerons
This mix allows the entire trailing edge of the wing (aileron and flap) to operate as ailerons. 
Assuming the left flap servo in Ch5, right flap servo in Ch6.
<br>Using a two position switch e.g. SwD to switch between flap mode and aileron mode. 
<br>Using the three position SwC to set the flap position in flap mode.
```txt
1. Ch5   Add    SwC (Weight -50,  Offset -50)
2. Ch5   RplcW  Ail (Weight -100, Diff 20, Switch SwD_Down)
3. Ch6   Add    SwC (Weight -50,  Offset -50)
4. Ch6   RplcW  Ail (Weight 100,  Diff 20, Switch SwD_Down)
```

### Example 9: Differential thrust
Left motor in Ch3, right motor in Ch7. We can use a switch e.g. SwE to turn the differential thrust off 
while in the air. Also assume the Rud source is the X1 axis
```txt
1. Ch3  Add  Thr (Weight 100)
2. Ch3  Add  X1  (Weight 40, Switch SwE_Down)
3. Ch7  Add  Thr (Weight 100)
4. Ch7  Add  X1  (Weight -40, Switch SwE_Down)
``` 
For safety, we also need to set Failsafe for both Ch3 and Ch7 in the 'Outputs' screen.  
We can also add throttle cut by specifying an override switch and a value of -100.

### Example 10: Throttle elevator mixing
When the throttle is increased, some down elevator can be added to counteract the tendency of the model gaining altitude when the throttle increases.

```txt
1. Ch2  Add  Ele (Weight -100)  
2. Ch2  Add  Thr (Weight -20, Offset -20)
```

### Example 11: Variable steering depending on throttle position
We want the steering response to reduce with increasing throttle.
Assuming we use the X1 axis to steer, Y1 axis as our throttle source, and the steering servo is on Ch6,
```txt
1. Ch6  Add    X1 (Weight 100)
2. Ch6  Mltply Y1 (Weight -40, Offset 60)
```

### Example 12: Adjust idle throttle with knob
Suppose we want to adjust the idle setting of the engine, without affecting full throttle.
Assuming the throttle servo is in Ch3,
```txt
1. Ch3   Add     KnobA (Weight 20, Offset 20)
2. Ch3   Mltply  Thrt  (Weight -50, Offset 50)
3. Ch3   Add     Thrt  (Weight 100)
```

### Example 13: Adjust maximum throttle with knob
We can adjust the maximum throttle without affecting the low throttle setting. Assuming the motor is in Ch3,
```txt
1. Ch3   Add     KnobA (Weight 20, Offset -20)
2. Ch3   Mltply  Thrt  (Weight 50, Offset 50)
3. Ch3   Add     Thrt  (Weight 100)
```

### Example 14: Simple throttle cut
Assuming Ch3 is the throttle channel, and assigning SwA for cut. When SwA is in the up position, Ch3 
is locked to -100, otherwise the Throttle input is sent to Ch3.
```txt
1. Ch3  Add    Thrt (Weight 100)
2. Ch3  RplcW  Max  (Weight -100, Switch SwA_Up)
```
Alternatively, a much safer throttle cut can be achieved in the Outputs screen by specifying the 
override as SwA and value -100.

### Example 15: Sticky throttle cut
Assuming Ch3 is the throttle channel, and assigning SwA for cut. Also assume our Throttle source is 
Y1 axis. We want the throttle cut whenever SwA is in the up position, but to only remove the cut when 
the throttle is at minimum and SwA is in the down position.  
This example makes use of logical switches as follows.
```txt
L1
Func:   Latch
Set:    SwA_Up
Reset:  L3

L2
Func:   a==x
Value1: Y1
Value2: -100

L3
Func:   AND
Value1: SwA_down
Value2: L2
``` 
Then in the mixer
```txt
1. Ch3  Add    Thrt (Weight 100)
2. Ch3  RplcW  Max  (Weight -100, Switch L1)
```
Alternatively, a much safer throttle cut can be achieved in the Outputs screen by specifying the 
override as L1 and value -100.

### Example 16: Landing gear sequencer (gear doors stay open after gear is extended)

The sequence we want upon flicking the switch is: doors open, gear extends. Similarly in the opposite direction: gear retracts, doors close. 
Using SwD for operation and assuming gear doors on Ch6 and gear on Ch7.
```txt
1. Ch6  Add  SwD (Weight 100, DelayUp 0 s, DelayDown 3 s, SlowUp 2 s, SlowDown 2 s)
2. Ch7  Add  SwD (Weight 100, DelayUp 3 s, DelayDown 0 s, SlowUp 2 s, SlowDown 2 s)
```
#### Alternative method that uses custom curves

Set up two custom curves as follows.
```txt
Curve1
Type: 3 point
Point(x,y): PtA(-100,-100) PtB(0,100) PtC(100,100)

Curve2
Type: 3 point
Point(x,y): PtA(-100,-100) PtB(0,-100) PtC(100,100)
``` 
<p align="left">

</p>

Then in the mixer, assuming gear door servos on Ch7, gear servos on Ch8, and using SwD to operate,
```txt
1. Virt1 Add  SwD   (Weight 100, SlowUp 5 s, SlowDown 5 s) //Create a source that slowly ramps
2. Ch7   Add  Virt1 (Weight 100, Custom Curve1)            //Apply curve1 for the door sequence
3. Ch8   Add  Virt1 (Weight 100, Custom Curve2)            //Apply curve2 for the gear sequence
```

### Example 17: Landing gear sequencer (gear doors close after gear is extended)
The extend sequence is doors open, gear is lowered, doors close.
<br>The retract sequence is doors open, gear retracts, doors close.
<br>We can achieve the above using custom curves in combination with a slowed switch.

#### Servo version
Set up two custom curves as follows.
```txt
Curve1
Type: 4 point
Point(x,y): PtA(-100,-100) PtB(-50,100) PtC(50,100) PtD(100,-100)

Curve2
Type: 4 point
Point(x,y): PtA(-100,-100) PtB(-50,-100) PtC(50,100) PtD(100,100)
``` 
<p align="left">

</p>

Then in the mixer, assuming gear door servos on Ch7, gear servos on Ch8, and using SwD to operate,
```txt
1. Virt1 Add  SwD   (Weight 100, SlowUp 7 s, SlowDown 7 s) //Create a source that slowly ramps
2. Ch7   Add  Virt1 (Weight 100, Custom Curve1)            //Apply curve1 for the door sequence
3. Ch8   Add  Virt1 (Weight 100, Custom Curve2)            //Apply curve2 for the gear sequence
```

#### Retract actuator version
Most electric retract actuators require an on/off control signal, so this example is designed to work with these. 
<br>Set up three custom curves as follows.
```txt
Curve1
Type: 4 point
Point(x,y): PtA(-100,-100) PtB(-50,100) PtC(50,100) PtD(100,-100)

Curve2
Type: 4 point
Point(x,y): PtA(-100,-100) PtB(-50,-100) PtC(-50,100) PtD(100,100)

Curve3
Type: 4 point
Point(x,y): PtA(-100,-100) PtB(50,-100) PtC(50,100) PtD(100,100)
```
<p align="left">

</p>

Then in the mixer, assuming gear door servos on Ch7, gear retracts on Ch8, and using SwD to operate, 
```txt
1. Virt1 Add   SwD   (Weight 100, SlowUp 10 s, SlowDown 10 s)   //Create a source that slowly ramps
2. Ch7   Add   Virt1 (Weight 100, Custom Curve1)                //Apply curve1 for the door sequence
3. Ch8   Add   Virt1 (Weight 100, Custom Curve2)                //Apply curve2 for the gear extend sequence
4. Ch8   RplcW Virt1 (Weight 100, Custom Curve3, Switch SwD_Up) //Apply curve3 for the gear retract sequence
```
We can, if necessary, set Ch8 to 'Digital' mode in the receiver output configuration screen.

### Example 18: Servo tester
We can program a simple servo tester that repeatedly moves a servo back and forth.
<br>In the extras menu, navigate to Function generator and select the desired movement type. 
<br>Then in the mixer, assuming the servo is connected to Ch8,
```txt
1. Ch8  Add  Fgen1 (Weight 100)
```
We can also make it more interesting by adding the ability to switch between waveforms or patterns 
via a switch. This is left as an exercise.

### Example 19: Random servo motion generator
Suppose we have a model equipped with a turret, or a figure. We want the servo to move automatically but in a 
random and intermittent manner.
<br>We can achieve this with function generators and logical switches as follows.
 
```txt
Fgen1
Waveform: Random
Interval: 2.0 s

Fgen2
Waveform: Random
Interval: 1.3 s
``` 

```txt
L1
Func:   a>x
Value1: Fgen2
Value2: 0
``` 
Then in the mixer, assuming our servo is on Ch7,
```txt
1. Ch7   Add   Fgen1 (Weight 100)
2. Ch7   Hold        (Switch L1)
3. Ch7   RplcW Ch7   (Weight 100, SlowUp 2 s, SlowDown 2 s)
```
Explanation: 
<br>Fgen1 generates a random position periodically, Fgen2 via Logical switch L1 is 
used to hold the output randomly to create the impression of intermittent motion. The last mixer line 
helps smooth the movement.
<br>If desired, we can also incorporate a custom curve to sort of bias the generated servo positions, for example
if we want our turret be pointing around the middle most of the time.
<br>We can also easily modify the setup to include an extra switch to manually stop the motion.

### Example 20: Random servo motion generator (advanced version)
This example generates a random servo position at a random interval, with an added effect of 
random intermittency, and also random selection between two speeds.  
Furthermore, a physical switch SwE is used to start/stop the random motion of the servo.

```txt
Fgen1
Waveform:      Random
Interval mode: Variable
Min Interval:  1.0 s
Max Interval:  2.0 s
Modulator:     Fgen2

Fgen2  (modulates the interval of Fgen1)
Waveform:      Random
Interval mode: Fixed
Interval:      1.0 s

Fgen3  (used for the intermittent motion)
Waveform:      Random
Interval mode: Fixed
Interval:      1.0 s

Fgen4  (used for the selection between two speeds)
Waveform:      Random
Interval mode: Fixed
Interval:      2.0 s
```

Then set up two logical switches as follows.
```txt
L1
Func:   a>x
Value1: Fgen3
Value2: 0

L2
Func:   a>x
Value1: Fgen4
Value2: 0
``` 

Then in the mixer, assuming our servo is on Ch7,
```txt
1. Ch7   Add    Fgen1 (Weight 100)
2. Ch7   Hold         (Switch L1)
3. Ch7   RplcW  Max   (Weight 0, SwE_Up) 
4. Ch7   RplcW  Ch7   (Weight 100, SlowUp 5 s, SlowDown 5 s, Switch L2)
5. Ch7   RplcW  Ch7   (Weight 100, SlowUp 2 s, SlowDown 2 s)
```

### Example 21: Oscillation without using the built-in function generator
Here is a way to create a crude oscillator from scratch.  
Set up a custom curve that defines the shape of our arbitrary waveform. For example,
```txt
Curve1
Type: 5 point
Point(x,y): PtA(-100,0) PtB(-50,-100) PtC(0,0) PtD(50,100), PtE(100, 0)
Smooth: True
```
Then define a logical switch as follows.
```txt
L1
Func:   a<x
Value1: Virt1
Value2: 100
``` 
Then in the mixer, we make use of the 'slow' feature on the L1 mixer input.
This essentially creates a sawtooth waveform on Virt1.
Assuming our final output is on Ch1, we specify the input as Virt1 and apply the custom curve.
```txt
1. Virt1  Add  L1    (Weight 100, SlowUp 1 s, SlowDown 0 s)
2. Ch1    Add  Virt1 (Weight 100, Custom Curve1)
```

### Example 22: Aileron rudder mixing with automatic switching
When the Rudder stick is centered and the Aileron stick is moved away from center, the mix is activated (Aileron stick now controls the rudder).
<br>The mix is deactivated as soon as the Rudder stick is moved away from center (Rudder stick now controls the Rudder).
<br>When both sticks are centered the mix gets activated again.
<br>We can achieve this behaviour with the help of logical switches as follows.
```txt
L1
Func:   a==x
Value1: Rud
Value2: 0

L2
Func:   a==x
Value1: Ail
Value2: 0

L3
Func:   AND
Value1: L1
Value2: L2

L4
Func:   Latch
Set:    L3
Reset:  !L1
``` 
Then in the mixer, assuming the rudder servo is on Ch4,
```txt
1. Virt1 Add     Max   (Weight 100, Switch L4)
2. Ch4   Add     Ail   (Weight 100, No trim)
3. Ch4   Mltply  Virt1 (Weight 100, SlowDown 1 s)
4. Ch4   Add     Rud   (Weight 100)
```
Here, Virt1 is used to smooth the transition from the Aileron stick to the Rudder stick.

### Example 23: Adjust aileron differential with the knob
This example illustrates a method for adjusting aileron differential in-flight, eliminating the need to land whenever we want to
tweak the setting. It is quite handy for experimenting with different values and helping with fine tuning.  
As we rotate the knob clockwise, the differential increases from 0% to 100%.

Set up a logical switch as follows.
```txt
L1
Func:   a>x
Value1: Ail 
Value2: 0
``` 
Then in the mixer, assuming the left aileron servo in Ch1, right aileron servo in Ch8
```txt
1. Ch1   Add     Ail    (Weight -100, No trim)
2. Ch1   Mltply  KnobB  (Weight -50, Offset 50, Switch L1)
3. Ch1   Add     X2Trim (Weight -100)
4. Ch8   Add     Ail    (Weight 100, No trim)
5. Ch8   Mltply  KnobB  (Weight -50, Offset 50, Switch !L1)
6. Ch8   Add     X2Trim (Weight 100)
```
Explanation:  
Differential is applied to the downward going aileron. When the Ail stick is moved right, we apply differential to the left aileron.
Similarly when the Ail stick is moved left, we apply differential to the right aileron.  
We detect the direction of the Ail stick via the logical switch L1 and use it to selectively apply the differential effect via a multiply mix.  
For this case, we also decouple the trim and add it afterward, to prevent it being affected by the differential.

---

Back to [user guide](user_guide.md).

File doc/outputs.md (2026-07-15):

# Outputs

Outputs are the last stage of the processing chain (Inputs ---> Mixer ---> Outputs).  
It is where final adjustments to the control data are made before transmission to the receiver.

<p align="left">


</p>

- **Reverse:** Useful for correcting the servo or actuator direction relative to the controls.
- **Subtrim:** Adjusts the center position of the servo or actuator. A side effect of using subtrim 
is that it causes clipping at the ends. E.g. if the mixer is outputting -100 to 100, a subtrim of say +5 
shifts the usable range of the servo to -95 to 100.
- **Override:** This is mainly a safety feature used for throttle cut, etc. It overrides the channel's output 
with the specified value when the activation switch is on.
- **Failsafe:** The receiver will output the specified value after about 1 second of signal loss from the transmitter.
Supported modes are Hold, No pulse, or Custom value.  
    - Hold - The receiver continues outputting the last value received prior to signal loss.  
    - No pulse - The receiver stops outputting pulses when signal loss occurs.  
    - Custom value - The receiver outputs a user-defined preset value.

    Always ensure that the correct failsafe setting is being used for the respective channel, especially for channels controlling motors or engines.
- **Endpoints:** Sets the overall travel or endpoints of the servo arm movement. Useful when we want to avoid any potential binding of a linkage or surface.
- **Curve:** Specifies the custom curve to use for this output. Useful when we want to correct for linkage geometry, mechanical differences, etc.

---

Back to [user guide](user_guide.md).

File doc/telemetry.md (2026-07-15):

# Telemetry

<p align="left">

</p>

## General telemetry
The receiver has built-in basic telemetry i.e. external voltage, RSSI, and packet rate. 
To measure other parameters, you will have to build custom sensors and extend the receiver firmware to support these.  
Telemetry values are transmitted as 16-bit signed integers.  
To quickly mute/unmute telemetry alarms, long press the Down key on the home screen.

<p align="left">

</p>

- **Name:** The sensor name.
- **Units:** The units of measurement.
- **ID:** This is the sensor ID, which must be unique. However, the same ID can be used for example to display a value in multiple ways.
- **Factor10:** The raw value is multiplied by 10 to power this factor. Useful when we want to scale the value.
- **Multiplier:** The raw value is multiplied by this number. Useful when we want to scale the value.
- **Alerts:** This parameter specifies how the alarm behaves.
- **Threshold:** This is the value below or above which the telemetry alarm will be sounded. The telemetry value will also flash when in alarm state.
- **On home:** Whether to automatically show the telemetry sensor on the home screen.
- **Record max, and record min:** Whether to track the max/min values received from the sensor. Useful 
for simple stats. Note that max and min are sensitive to outliers hence the filtering and smoothing
should be done before sending the telemetry to the transmitter.

## GNSS telemetry
GNSS telemetry is also supported. A premade template is used to add the GNSS sensor to the telemetry screen.  
The receiver directly connects to the GNSS/GPS module via serial (UART), and handles parsing of the NMEA sentences 
as well as data conversion. GPS, GLONASS, BeiDou, Galileo are supported.  
The system remembers the last known location in case of a lost model, even when the transmitter is powered off.  
Various units of measurement can be displayed; metric and imperial supported.

<p align="left">


</p>

- **Satellites:** The number of satellites in use / in view. "Fix" is appended when we have a position fix.
- **Distance:** The calculated distance between the model's current location and the home location (starting point). 
If the displayed distance is inaccurate, simply reset the starting point from the context menu. 
- **Speed:** The speed over ground. This is the speed at which your model is moving relative to the Earth's surface. The last received value is shown when there is no incoming telemetry or no position fix. 
- **Course:** The course over ground. This is direction of movement of your model over the Earth's surface, irrespective of the direction your model is pointing. The last received value is shown when there is no incoming telemetry or no position fix.
- **Altitude AGL:** The altitude above ground level. If the value is inaccurate, reset it from the context menu. The last received value is shown when there is no incoming telemetry or no position fix.
- **Altitude MSL:** The altitude relative to mean sea level. The last received value is shown when there is no incoming telemetry or no position fix. 
- **Latitude and Longitude:** The location coordinates of the model. 
Displays the last known location when there is no incoming telemetry or no position fix.
- **Starting point:** Displays the coordinates of the home location.

---

Back to [user guide](user_guide.md).

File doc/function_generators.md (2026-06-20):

# Function generators

These produce various waveforms over a range of frequencies or periods. They are implemented as low frequency
oscillators, hence the reason why period instead of frequency is specifiable.  
Supported waveforms are sine, square, triangle, sawtooth, pulse, and random.  
The function generators are capable of frequency modulation, with smooth transition between frequencies.

<p align="left">


</p>

## Usage examples
Below are some examples making use of function generators.

- [Servo tester](./mixer.md#section_id_servo_tester)  
- [Random servo motion generator](./mixer.md#section_id_random_servo_motion_generator)  
- [Random servo motion generator - advanced](./mixer.md#section_id_random_servo_motion_advanced)

---

Back to [user guide](user_guide.md).

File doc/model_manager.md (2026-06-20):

# Model manager

<p align="left">


</p>

The model manager enables various actions, such as creating, loading, and deleting models. By default, model settings are stored in the EEPROM.

SD cards are also supported and are useful for backing up and restoring models. Model data on the SD card is stored
in a human-readable text format similar to YAML.

**Available model types**
- Airplane: Used for fixed wing aircraft.
- Multicopter: Used for aircraft with rotors, e.g. quadcopters, helicopters, etc.
- Other: This is a generic type for anything else. Boats, land vehicles, robots, animatronics, etc.

**Note:**
1. An external EEPROM is recommended but not mandatory. However, without it, the system will only have one model slot available, 
which makes it cumbersome to switch between different models, as we would always need to rely on the SD card to load a different model.
2. Before updating the firmware in the transmitter, always back up your models to the SD card to avoid any potential data loss or corruption.
3. The "Copy from" feature only works between models of the same type.
4. Loading or selecting a new model disables RF output for safety reasons; therefore, RF output must be manually re-enabled afterward.

---

Back to [user guide](user_guide.md).

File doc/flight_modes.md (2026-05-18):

# Flight modes

Flight modes allow you to easily reconfigure settings such as mixes and trim values with the simple flip of a switch. While it's possible to achieve similar adjustments using multiple switches, having the ability to make all these changes with just one switch is undoubtedly more efficient and convenient.

<p align="left">

</p>

- **Name:** A name/label for this flight mode. 
- **Switch:** The control switch that activates this flight mode.
- **Fade-in:** The transition time to effect the trim setting for this flight mode.

---

Back to [user guide](user_guide.md).

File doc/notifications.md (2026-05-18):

# Notifications
Notifications are user-programmable and provide audible alarms to report about events.
<p align="left">

</p>

- **Enable:** Whether the notification is enabled or disabled. Only enabled notifications will be sounded and displayed.
- **Switch:** The control switch used to trigger the notification. The notification gets only triggered on the positive going edge, i.e. when the state of the switch changes from low to high.
- **Tone:** The tune to play when the notification is triggered.
- **Text:** Optional text that will be displayed, as a toast message on the screen.

**Note:**  
System events like low transmitter battery, inactivity, etc. are natively handled by the system, thus there is no need to configure them inside custom notifications. 

## Usage examples

- [Detecting receiver connection or disconnection ](./logical_switches.md#section_id_detect_disconnection_of_receiver) 

---

Back to [user guide](user_guide.md).

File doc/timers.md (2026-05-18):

# Timers
Timers are used to time events, etc. The system provides up to 3 programmable timers.  
Timers can be configured to count up or count down.  
In count down mode, an audible alarm is played when the timer reaches zero. The timer continues to count with a negative sign.

<p align="left">

</p>

- **Name:** A name for the timer, otherwise a generic name is used.
- **Switch:** The control switch used to start and stop the timer. This is optional, as the timer can also be started or stopped from the context menu.
- **Reset:** The control switch used to reset the timer. This is optional, as the timer can also be reset from the context menu.
- **Initial:** The initial time if a countdown timer. If not specified, the timer will count up. A time picker dialog is used to easily set the initial time.
- **Persist:** Whether the timer is persistent i.e. if the value should be remembered between sessions.

## Examples

- [Stopwatch operated by a single momentary switch](./logical_switches.md#section_id_stopwatch_with_momentary_switch)  
- [Throttle timer - simple](./logical_switches.md#section_id_throttle_timer_simple)  
- [Throttle timer - advanced](./logical_switches.md#section_id_throttle_timer_advanced)  

---

Back to [user guide](user_guide.md).

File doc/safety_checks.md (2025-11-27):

# Safety checks

These checks are done before loading a model and on start up.  
Positions of switches as well as the throttle source are checked, depending on the setting.  
A warning will be shown if the set conditions are not met.

<p align="left">

</p>

<p align="left">

</p>

---

Back to [user guide](user_guide.md).

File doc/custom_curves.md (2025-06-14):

# Custom curves
These can be used in the mixer and the outputs screen. They basically define a relation between an input (along the x) and output (along the y).  
Any point/node on the curve can be freely moved around to get the desired shape of curve. Up to 10 points/nodes can be defined.  
The curve can also be optionally smoothed, although this feature should be used sparingly as it is relatively CPU intensive.  

<p align="left">

</p>

#### Combining two curves for extra points or nodes
If more curve points are needed, a work around is to combine two curves by switching out one for the other in the mixer, with help of a logical switch.

## Usage examples
Below are some examples demonstrating the use of custom curves.

- [Landing gear sequencer](./mixer.md#section_id_landing_gear_sequencer_v1)  
- [Landing gear sequencer - advanced](./mixer.md#section_id_landing_gear_sequencer_v2)  
- [Oscillator from scratch](./mixer.md#section_id_oscillator_from_scratch)  

---

Back to [user guide](user_guide.md).

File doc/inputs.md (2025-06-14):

# Inputs

The inputs screen allows setting dual rates and expo, throttle curve, as well as showing the values from the physical controls.

<p align="left">

</p>

- For model type 'Airplane', the naming used for the main controls is Ail, Ele, Rud, Thr.
- For model type 'Multicopter', the nomenclature changes to Roll, Pitch, Yaw, Thr.
- The sources for the above inputs may default to a different order based on the chosen stick mode in System settings.
- The system accepts both 2-position and 3-position switches, as well as their momentary variants.  

The image below shows a typical layout of the transmitter.

<p align="left">

</p>

---

Back to [user guide](user_guide.md).

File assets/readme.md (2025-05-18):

The screens in the UI have been designed with [GraphicsGale](https://graphicsgale.com/us/) from scratch using primitives (pixels, lines, rectangles, text).  
To modify or add new screens, here are the getting started instructions.
- Install the GraphicsGale software
- Install the font Bm437_Portfolio_6x8_modBUK.FON in the font subfolder to your system.

In GraphicsGale under new file, 
- Set the canvas to 128x64 (or your screen size)
- When drawing text, set the font to "Bm437 Portfolio 6x8", size 8, pitch 0

The transmitter firmware also has a built-in screenshot capture feature. It can be accessed in the debug menu.

For converting icons or sprites bitmaps to byte arrays, I used the tool [image2cpp](http://javl.github.io/image2cpp/).

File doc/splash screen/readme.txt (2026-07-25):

- The firmware now supports monochrome bitmap images for the splash screen.
- To make a custom splash screen, create a monochrome bitmap image with 128x64 px resolution and 
  save it as "SPLASH.BMP" inside the "IMAGES" folder on the SD card.

Legacy instructions below.
--------------------------

Prerequisites
- Python installed on your computer
- Python Imaging Library (install via command "pip install pillow" if not already installed)

Steps
1. Make or prepare the image using any image editing software, with dimensions 128 px width and 64 px height.
2. Export it as "image.bmp" file.
3. Put the file into the same folder as the python script, then run the python script.
4. Create a folder "IMAGES" on the SD card, then copy the generated "splash" to it.

Now whenever you power on your rc transmitter, it shows your custom splash screen.

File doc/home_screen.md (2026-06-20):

# Home screen

The home screen is the default screen shown when operating the transmitter. It displays basic information such as the active model name, trims, status icons, transmitter battery, active flight mode, and up to four custom widgets.

<p align="left">

</p>

Key actions on the home screen are as follows:

- Down key
    - Click: Opens the context menu.
    - Hold:  Quickly mutes/unmutes telemetry alarms.
- Up key
    - Click: Opens the channel monitor.
    - Hold:  Enters the on-screen trim mode on handsets that lack physical trim buttons.
- Select Key
    - Click: Opens the main menu.
    - Hold: Navigate back. This is also the default behaviour in all screens.

### Widgets

Customizable widgets allow the user to display/monitor different parameters directly on the home screen.  
To set up the widgets, access the home screen context menu.

<p align="left">

</p>

- **Type:** The category of widget, i.e. Telemetry, Mix sources, Outputs, Timers, or Counters.
- **Source:** The input source for the widget.
- **Display:** Specifies how the widget is shown on the home screen, i.e. as a numerical value, a gauge, or a zero-centered gauge. 
Available options depend on the type of widget selected.
- **Minimum and Maximum:** Sets the lower and upper limits of the gauge.

---

Back to [user guide](user_guide.md).

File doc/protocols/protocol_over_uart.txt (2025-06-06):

====================================================================================================
  PROTOCOL OVER UART
====================================================================================================

General format is as below.

---------------------------------------------------------------------------------------------------
Field    |  Preamble   Message type   Data length   Data            CRC              Padding
Size     |  3 bytes    1 byte         1 byte        0 to 42 bytes   1 byte           0 to 42 bytes
Offset   |  0          3              4             5               5 + dataLength   6 + dataLength
---------------------------------------------------------------------------------------------------

- The total size is fixed at 48 bytes. 
- Preamble is three 0xAA bytes.
- Padding bytes are added if the resulting size is less than the fixed size. 
  Padding is done with zeroes.

Message types
==============

The following enumerations are used:-

enum {
  MESSAGE_TYPE_NONE = 0x00,
  
  //mtx to stx
  MESSAGE_TYPE_RC_DATA = 0x01, 
  MESSAGE_TYPE_ENTER_BIND = 0X02,
  MESSAGE_TYPE_GET_RECEIVER_CONFIG = 0x03,
  MESSAGE_TYPE_WRITE_RECEIVER_CONFIG = 0x04,
  
  //stx to mtx
  MESSAGE_TYPE_BIND_STATUS_CODE = 0x10,
  MESSAGE_TYPE_RECEIVER_CONFIG = 0x11,
  MESSAGE_TYPE_RECEIVER_CONFIG_STATUS_CODE = 0x12,
  MESSAGE_TYPE_TELEMETRY_RF_LINK_PACKET_RATE = 0x13,
  MESSAGE_TYPE_TELEMETRY_GENERAL = 0x14,
  MESSAGE_TYPE_TELEMETRY_GNSS = 0x15,
};

Data
==============

MESSAGE_TYPE_RC_DATA:

  RC channel outputs values or faisafe data, encoded as 10 bits per channel.   
  Flags are transmitted in a separate byte that is appended. 
  The flag byte is as follows: 
    bit 0 to 2    RF power level.
    bit 3         Return telemetry.
    bit 4         Whether this is failsafe data.

MESSAGE_TYPE_ENTER_BIND:
MESSAGE_TYPE_GET_RECEIVER_CONFIG:
  
  The data is 1 byte.
  Value is as follows.
    0   Secondary receiver is being addressed.
    1   Main receiver is being addressed.

MESSAGE_TYPE_RECEIVER_CONFIG:
MESSAGE_TYPE_WRITE_RECEIVER_CONFIG:
  
  Each RC channel's output configuration is sent on a separate byte, encoded as follows.
    bit 0 to 1    The present mode. Value is as follows: 
                    0  Digital, 
                    1  Servo PWM, 
                    2  Normal PWM.
    bit 2 to 3    The maximum supported mode. Not applicable if writing configuration.
    bit 4 to 7    The servo pwm range. Value is an index in the lookup table.
                  See the "servo_PWM_range_LUT.xls" for extended description.
                  
  If the message is of type MESSAGE_TYPE_WRITE_RECEIVER_CONFIG, a byte containing a flag is 
  appended. The value is as follows.
    0   Secondary receiver is being addressed.
    1   Main receiver is being addressed.

MESSAGE_TYPE_BIND_STATUS_CODE:

  This message serves to acknowledge the receiver binding to the main transmitter microcontroller.
  The returned code is 1 byte. 
  Value is as follows: 
    1   Bind successful.
    2   Bind failed.

MESSAGE_TYPE_RECEIVER_CONFIG_STATUS_CODE:

  This message serves to acknowledge receipt of the receiver configuration 
  to the main transmitter microcontroller, after a "write configuration" has been made. 
  The returned code is 1 byte. 
  Value is as follows: 
    1   Write successful. 
    2   Write failed.

MESSAGE_TYPE_TELEMETRY_RF_LINK_PACKET_RATE:

  Data is 2 bytes as follows:
    byte 0    Transmitter packet rate, 
              i.e. how many RC packets are being sent out by transmitter.
    byte 1    Receiver packet rate, 
              i.e. how many valid RC packets are being seen by the receiver.

MESSAGE_TYPE_TELEMETRY_GENERAL:

  Every 3 bytes represent a telemetry field. 
  Each telemetry field is formatted as: 
    byte 0    Sensor ID.
    byte 1    High byte of telemetry value.
    byte 2    Low byte of telemetry value.

MESSAGE_TYPE_TELEMETRY_GNSS:

   The data is a structure containing the GNSS telemetry information.
   See the "gnss_telemetry_data_structure.txt" file for more details.

CRC
=============
The 8 bit CRC of all the preceding bytes, including the preamble.

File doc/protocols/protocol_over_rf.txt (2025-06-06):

====================================================================================================
  PROTOCOL OVER RF
====================================================================================================

General format of a packet is as below.

-------------------------------------------------------------------
Field    |  Header    Payload         CRC             
Size     |  3 bytes   0 to 26 bytes   1 byte          
Offset   |  0         3               3 + payloadLength  
-------------------------------------------------------------------

Header
==============
Encoded from left to right as follows:
  Source ID         7 bits
  Destination ID    7 bits
  Packet type       5 bits
  Payload length    5 bits

If packet is originating from transmitter, then Source ID is the Transmitter ID. 
Similarly if a packet is originating from the receiver, then Source ID is the Receiver ID. 
The allowed transmitter IDs range from 0x01 to 0x7F.  Transmitter ID 0x00 is reserved. 
The allowed receiver IDs range from 0x01 to 0x7F. Receiver ID 0x00 used when binding.

Packet types
==============
The following enumerations are used to identify the packet:-

enum {
  PACKET_BIND = 0,
  PACKET_ACK_BIND = 1,
  PACKET_READ_OUTPUT_CH_CONFIG = 2,
  PACKET_SET_OUTPUT_CH_CONFIG = 3,
  PACKET_ACK_OUTPUT_CH_CONFIG = 4,
  PACKET_RC_DATA = 5,
  PACKET_TELEMETRY_GENERAL = 6,
  PACKET_TELEMETRY_GNSS = 7,

  PACKET_INVALID = 0xFF
};

Payload
===============

PACKET_BIND:

  The payload is as follows:
    byte 0 to k  Hop channels, 1 byte per channel.
    byte k+1     Flags, bit0 whether we are addressing the main or secondary receiver.
    byte k+2     Receiver ID to use if binding as a secondary receiver.
  
  To acknowledge bind, the receiver simply returns its ID as the payload with packet identifier 
  as "PACKET_ACK_BIND".

PACKET_ACK_BIND:
  
  This is returned by the receiver to acknowledge the binding. 
  The payload is as follows:
    byte 0       Receiver ID.

PACKET_RC_DATA:

  All RC channel data are sent in a single transmission.
  The data is either RC channel outputs values or faisafe data, encoded with 10 bits per channel.   
  Flags are transmitted in a separate byte that is appended. 
  The flag byte is as follows: 
    bit 0 to 2   RF power level.
    bit 3        Return telemetry.
    bit 4        Whether this is failsafe data.

PACKET_TELEMETRY_GENERAL:

  This originates from the receiver. 
  The payload is as follows:
    byte 0       Packet rate at receiver side.
    byte 1 to k  General telemetry fields.
  
  Every 3 bytes represent a telemetry field.
  Each telemetry field is formatted as: 
    byte 0       Sensor ID.
    byte 1       High byte of telemetry value.
    byte 2       Low byte of telemetry value.

PACKET_TELEMETRY_GNSS:

  This originates from the receiver.
  The payload is a structure containing the GNSS telemetry information.
  See the "gnss_telemetry_data_structure.txt" file for more details.

PACKET_READ_OUTPUT_CH_CONFIG:

  This can originate from both the transmitter and receiver.
  
  Case of origin from transmitter:-
    Payload is 1 byte.
    Value is as follows.
      0   Secondary receiver is being addressed.
      1   Main receiver is being addressed.
  
  Case of origin from receiver:-
    Each RC channel's output configuration is sent on a separate byte, encoded as follows.
    bit 0 to 1    The present mode. Value is as follows: 
                    0  Digital, 
                    1  Servo PWM, 
                    2  Normal PWM.
    bit 2 to 3    The maximum supported mode.
    bit 4 to 7    The servo pwm range. Value is an index in the lookup table.
                  See the "servo_PWM_range_LUT.xls" for extended description.

PACKET_SET_OUTPUT_CH_CONFIG:

  This originates from the transmitter. 
  The format is the same as PACKET_READ_OUTPUT_CH_CONFIG from the receiver, except that the 
  field "maximum supported mode" is not applicable.
  An extra byte is appended, containing a flag that specifies which receiver is being addressed.

PACKET_ACK_OUTPUT_CH_CONFIG:

  This originates from the receiver. 
  The payload is empty. This packet merely tells the transmitter that the settings have been 
  properly received and applied.

CRC
=============
The 8 bit CRC of all the preceding bytes, including the header.

====================================================================================================
  Dual receiver setup
====================================================================================================
Basic rules:
- Depending on the setup, the main receiver may handle one half of the RC channels,
  while the secondary handles the other half. However the entire RC data is always sent 
  in a single transmission.
- When binding to the main receiver, the transmitter generates a random transmitter ID 
  and hop sequence. The main receiver then generates a random receiver ID and sends it.
- When binding to a secondary receiver, the transmitter ID and receiver ID are maintained, as 
  well as the hop sequence. 
- Only the main receiver can send telemetry; the secondary receiver ignores the telemetry requests.
- The transmitter requests and sends configuration settings to each receiver separately 
  by way of a flag to distinguish the intended receiver from the other.

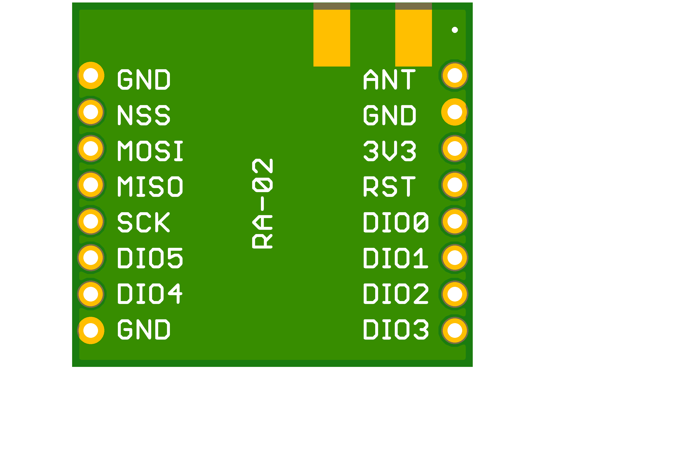
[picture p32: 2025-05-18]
schematics/breakout boards/RA-02/board_RA-02_v2_bottom.png

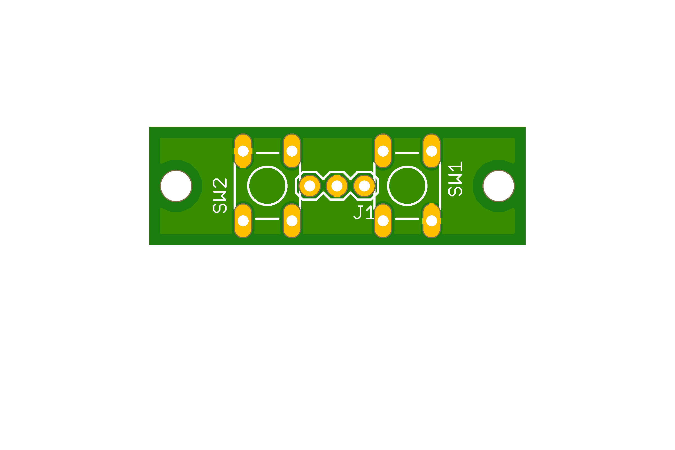
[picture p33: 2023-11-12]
schematics/transmitter/main/trims/trim_switch.top.png

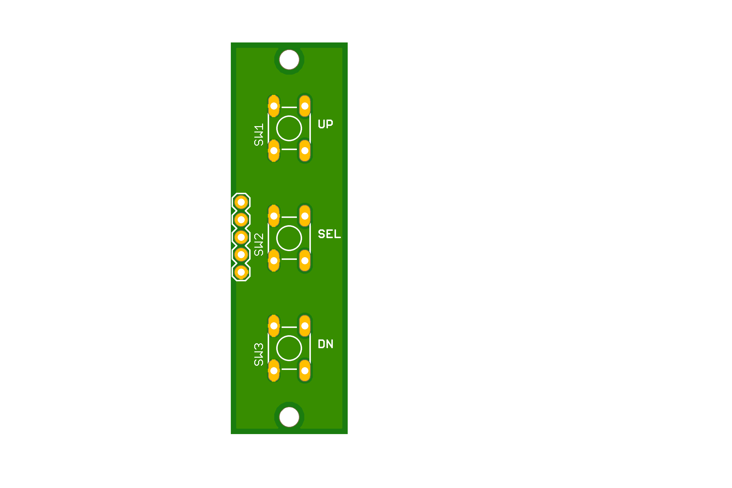
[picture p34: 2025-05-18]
schematics/transmitter/main/buttons/buttons_v2_top.png

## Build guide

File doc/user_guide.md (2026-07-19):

# User guide

- [Overview](overview.md)
- [Home screen](home_screen.md)  
- [Model manager](model_manager.md)  
- [Inputs](inputs.md)  
- [Mixer](mixer.md)  
- [Outputs](outputs.md)  
- Extras  
    - [Custom curves](custom_curves.md)  
    - [Logical switches](logical_switches.md)  
    - [Function generators](function_generators.md)  
    - [Timers](timers.md)  
    - [Counters](counters.md)  
    - [Notifications](notifications.md)  
    - [Safety checks](safety_checks.md)  
    - [Trim setup](trim_setup.md)  
    - [Flight modes](flight_modes.md)  
- [Telemetry](telemetry.md)  
- [System](system_settings.md)  
- [Receiver](receiver_config.md)  

See also
- [Frequently Asked Questions](faq.md)

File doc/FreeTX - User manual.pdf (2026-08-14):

# FreeTX

# User Manual

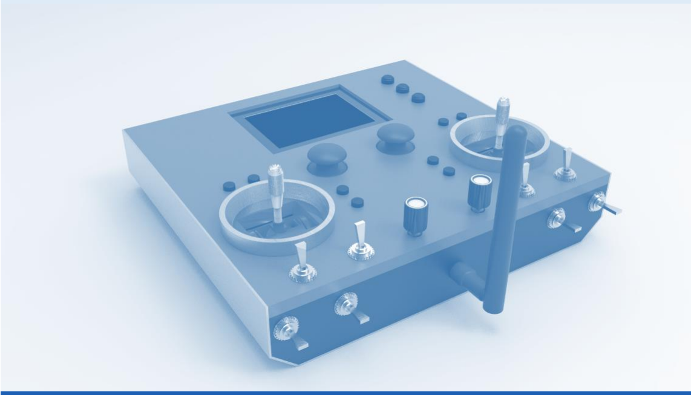
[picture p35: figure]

August 2026

### Table of Contents

Order of mixer operations .........12

Configuring receiver outputs ..... 53

# FreeTX

FreeTX is an open-source radio control system for almost anything. Remotely operate model airplanes, multicopters, helicopters, boats, land vehicles, robots, animatronics, etc.

## Main features

- 20 fully proportional RC channels, each encoded with 10 bits.
- Configurable RC channel output signal format.
- Update rate of 50x per second for all RC channels.
- Receiver binding, adjustable RF power, frequency hopping.
- Reverse, subtrim, endpoints, failsafe, dual rates and expo, custom curves, flight modes.
- Powerful mixer system, logical switches, function generators, counters, timers.
- Telemetry, alarms, warnings, notifications, home screen widgets, custom splash screen, etc.
- Model memory, I2C EEPROM and SD card supported. Model types, context-aware nomenclature.
- Intuitive user interface.

## Hardware and Schematics

The transmitter and receiver schematics can be found in the Schematics folder. The major components are:-

- 1x Atmega2560 microcontroller, 2x Atmega328p microcontrollers.
- 2x SX1276/77/78/79 or RFM95 based Lora modules. Other RF modules can possibly be used with some modifications to the source code.
- A 128x64 graphical LCD with KS0108 or ST7920 controller. Any other 128x64 LCD can however be used (provide own driver code).

## User interface

Three buttons are used for navigating the user interface i.e. Up, Select, Down. Long press Select to go Back.

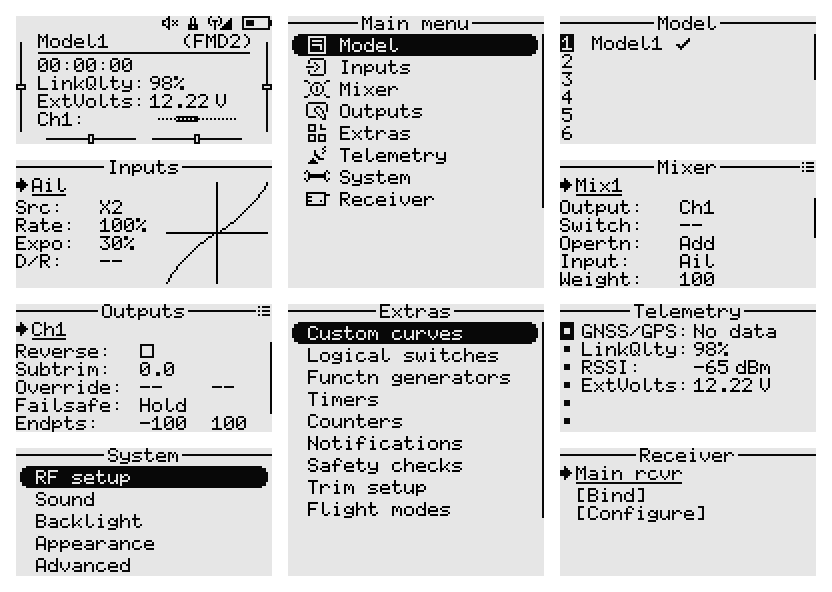
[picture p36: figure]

## Default configuration

By default, the system is configured with the following features.

- 10 stick input axes, 8 switches, 2 knobs
- 40 mixer slots, 20 proportional RC channels
- 10 custom curves, 10 max points per curve
- 20 logical switches, 5 function generators, 3 timers, 5 counters
- 10 custom notifications
- 5 flight modes
- 8 telemetry sensor slots

Many of these numbers are easily customisable in the source code, the limit being the available memory and I/O pins.

## System architecture

### Transmitter hardware block diagram

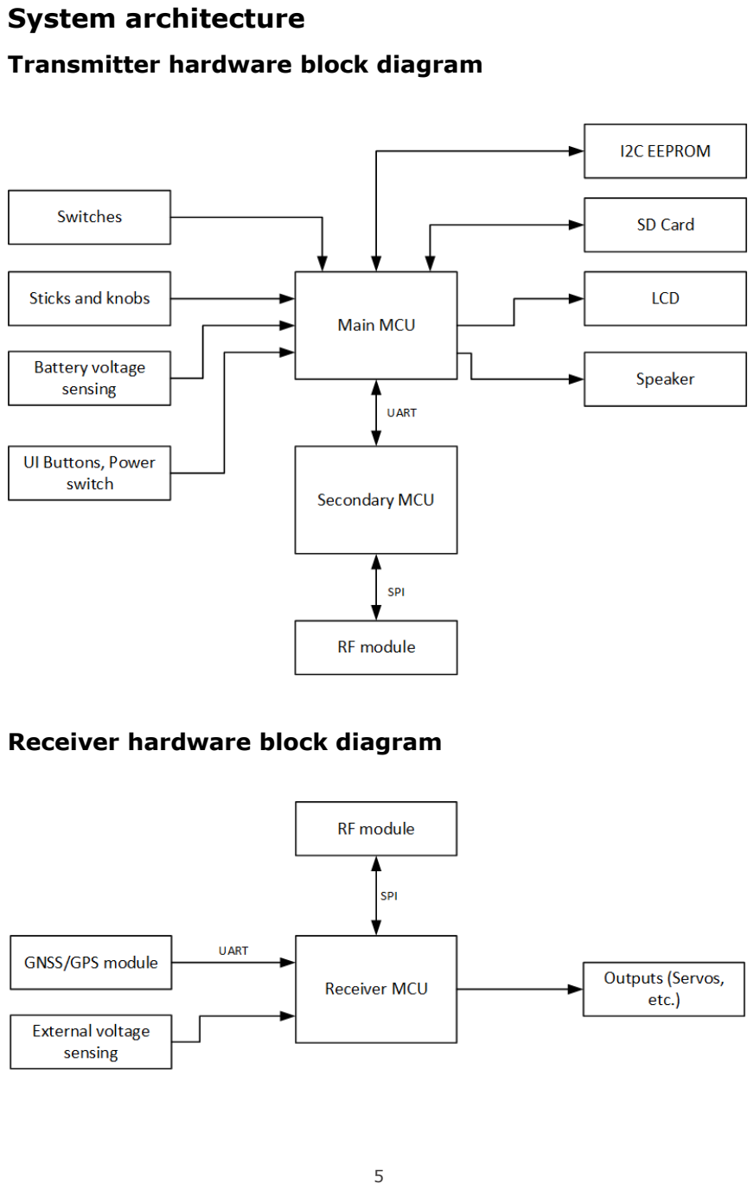
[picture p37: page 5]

### Receiver hardware block diagram

### RF protocol

A custom RF protocol is used to communicate between the transmitter and receiver. The implementation builds on top of LoRa(R) transceivers. The documentation can be found in the Protocols folder.
The main features are:-
- 10 bit encoding for all RC channels
- 50 Hz update rate for all RC channels
- Frequency Hopping Spread Spectrum
- Telemetry support

# Home screen

The home screen is the default screen shown when operating the transmitter. It displays basic information such as the active model name, trims, status icons, transmitter battery, active flight mode, and up to four custom widgets.

Key actions on the home screen are as follows:

- Down key
- Click: Opens the context menu.
- Hold: Quickly mutes/unmutes telemetry alarms.
- Up key
- Click: Opens the channel monitor.
- Hold: Enters the on-screen trim mode on handsets that lack physical trim buttons.
- Select Key
- Click: Opens the main menu.
- Hold: Navigate back. This is also the default behaviour in all screens.

## Widgets

Customizable widgets allow the user to display/monitor different parameters directly on the home screen.
To set up the widgets, access the home screen context menu.
- Type: The category of widget, i.e. Telemetry, Mix sources, Outputs, Timers, or Counters.
- Source: The input source for the widget.
- Display: Specifies how the widget is shown on the home screen, i.e. as a numerical value, a gauge, or a zero-centered gauge. Available options depend on the type of widget selected.
- Minimum and Maximum: Sets the lower and upper limits of the gauge.

# Model manager

The model manager enables various actions, such as creating, loading, and deleting models. By default, model settings are stored in the EEPROM.

SD cards are also supported and are useful for backing up and restoring models. Model data on the SD card is stored in a human-readable text format similar to YAML.

Available model types

- Airplane: Used for fixed wing aircraft.
- Multicopter: Used for aircraft with rotors, e.g. quadcopters, helicopters, etc.
- Other: This is a generic type for anything else. Boats, land vehicles, robots, animatronics, etc.

Note:

1. An external EEPROM is recommended but not mandatory. However, without it, the system will only have one model slot available, which makes it cumbersome to switch between different models, as we would always need to rely on the SD card to load a different model.
2. Before updating the firmware in the transmitter, always back up your models to the SD card to avoid any potential data loss or corruption.
3. The "Copy from" feature only works between models of the same type.
4. Loading or selecting a new model disables RF output for safety reasons; therefore, RF output must be manually re-enabled afterward.

# Inputs

The inputs screen allows setting dual rates and expo, throttle curve, as well as showing the values from the physical controls.

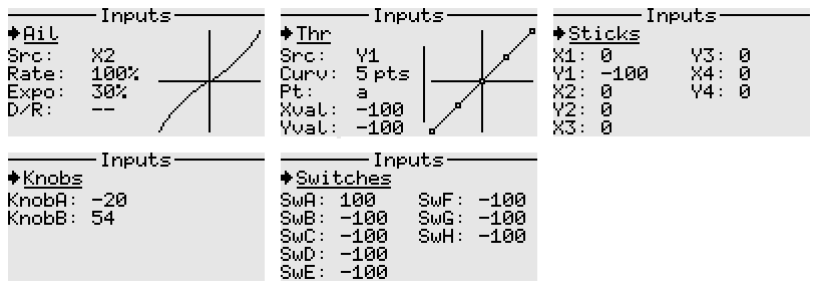
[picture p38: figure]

- For model type 'Airplane', the naming used for the main controls is Ail, Ele, Rud, Thr.
- For model type 'Multicopter', the nomenclature changes to Roll, Pitch, Yaw, Thr.
- The sources for the above inputs may default to a different order based on the chosen stick mode in System settings.
- The system accepts both 2-position and 3-position switches, as well as their momentary variants.

The image below shows a typical layout of the transmitter.

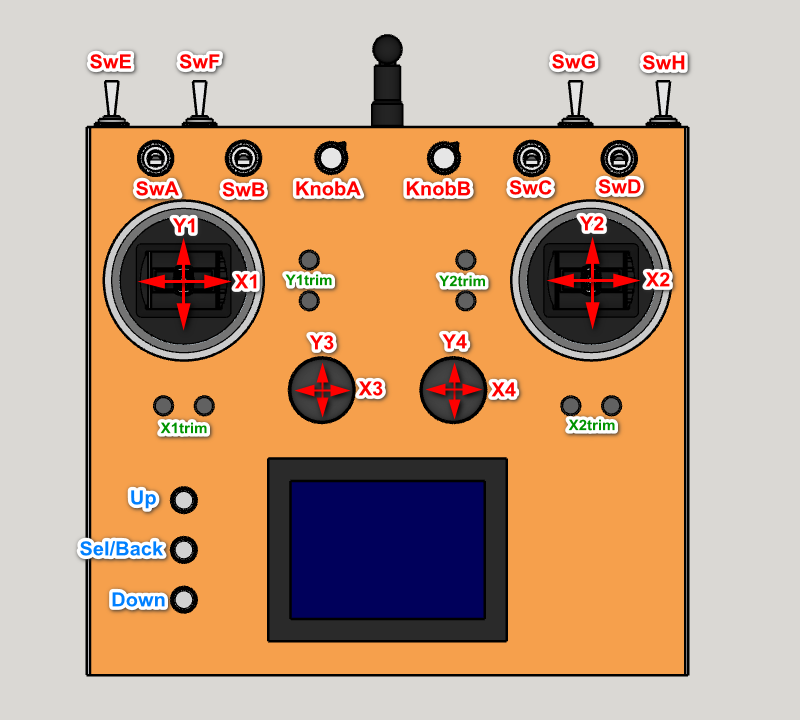
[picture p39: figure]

# The Mixer

The mixer is where the inputs (mixer sources) get linked to the output channels (servos, etc.). This controller features a mixer system that draws inspiration from that found in OpenTX(R) based RC transmitters, though not directly compatible.

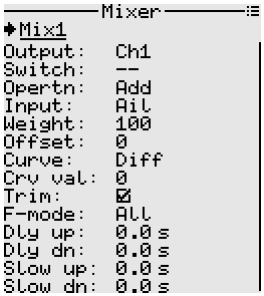
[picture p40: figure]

## Mixer fields

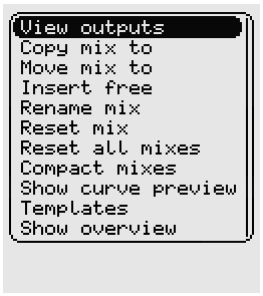
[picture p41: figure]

- Output: The channel that is to be affected by the mix. If none, the mix is inactive and is not computed.
- Switch: The control switch to turn the mix on or off. The mix is always active if no switch is specified.
- Operation: Add, Multiply, Replace with, Hold.
- Input: This is the mixer source.
- Weight: Determines how much of an effect the input has on the output. -100 to 100.
- Offset: The input is offset by this value after the weight has been applied. -100 to 100.
- Curve: Differential, Expo, Function, Custom curve.
- Curve value: Differential {-100 to 100}, Expo {-100 to 100}, Function {x>0, x<0, |x|}, Curve name if custom curve.
- Trim: Whether to add trim or not.
- F-Mode: The flight mode in which the mix applies.
- Delay Up and Down: This is used to delay the input. 0 to 60 seconds.
- Slow Up and Down: This when non-zero specifies how fast the input changes. 0 to 60 seconds.

## Mixer sources

Mixer sources can be any of the following:

- Raw stick axes (X1, Y1, X2, Y2, etc.)
- Processed sticks (Rud/Yaw, Thr, Ail/Roll, Ele/Pitch)
- Knobs (KnobA, KnobB)
- Constants (Max)
- Function generators (Fgen1, Fgen2, etc.)
- Trims (X1Trim, Y1Trim, X2Trim, Y2Trim)
- Physical switches (SwA, SwB, etc.)
- Logical switches (L1, L2, etc.)
- Channels (Ch1, Ch2, etc.)
- Virtual channels (Virt1, Virt2, etc.)

Counters can also be used as inputs in the mixer, although they are not classified as true mixer sources.

## Control switches

These can be used to activate or deactivate various functions, for example enabling or disabling mixes, starting or stopping timers, and more. The following control switches are available:

- Physical switches (SwA↑, SwA−, SwA↓, etc.)
- Logical switches (L1, L2, !L1, !L2, etc.)
- Trim buttons (X1Trim←, X1Trim→, Y1Trim↑, Y1Trim↓, etc.)
- Flight modes as control switches (Fmd1, Fmd2, !Fmd1, !Fmd2, etc.)

The symbols "↑", "−", and "↓" correspond to the up, middle (center), and down positions of physical switches, respectively.
The "↑" and "↓" symbols are also used on vertical trim buttons to indicate an active upward or downward press.
The "←", and "→" symbols also denote the left and right press states of the horizontal trim buttons.
The "!" symbol indicates a logical NOT operator. For example, the condition "!SwC↑" evaluates as true when SwC is not in the up position.

## Order of mixer operations

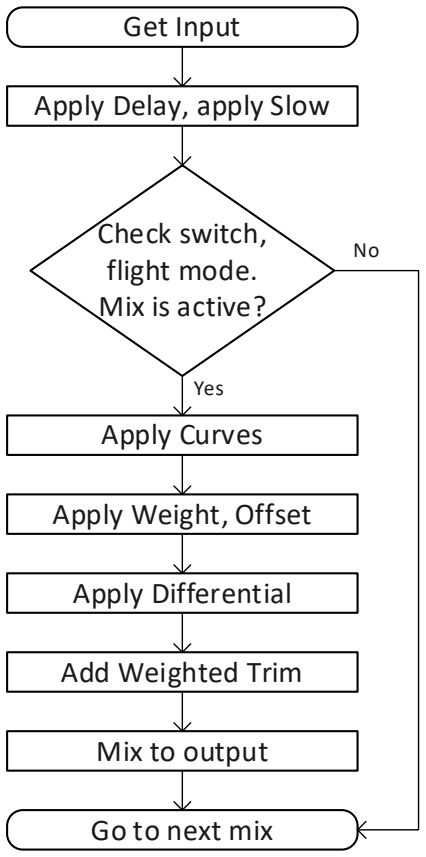
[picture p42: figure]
Get Input; Apply Curves; Apply Weight, Offset; Add Weighted Trim; Apply Delay, apply Slow; Check switch, flight mode. Mix is active?; Mix to output; Go to next mix; Yes; Apply Differential

## Context menu actions

- View outputs: Opens the mixer monitor, which shows the real-time status of all output channels. Click the Select button within this monitor to view a tooltip containing the exact value of the selected channel.
- Copy mix to: Copies this mix to a specified destination.
- Move mix to: Moves this mix to a specified destination.
- Insert free: Inserts a free mix slot at the current position.
- Rename mix: Opens the text editor dialog to specify a name for this mix.
- Reset mix: Resets this mix to the default setting.
- Reset all mixes: Resets all mixes to the default settings.
- Compact mixes: Removes all empty/free slots that exist in-between the defined mixes.
- Show curve preview: Whether to draw the curve on the mixer screen. The displayed curve shows a trace of the output vs input for this specific mix.
- Templates: Use this option to load the predefined mixer templates.

- Show overview: Display a summary of the configured mixes. In the overview screen, click the Select button to display a tooltip with extra information about the highlighted mix line.

## Important safety note

When editing mixes, it is recommended to disable RF output or remove propellers first. This is because all changes/adjustments made are applied instantly and may bring surprises.

## Example mixes

Note:

- The convention used in these examples is negative for left/downward going control surfaces, positive for right/upward going control surfaces. For example, if the Ail stick is moved right, the left aileron moves down and the right aileron moves up. Hence, we use a negative weight for the left aileron and a positive weight for the right aileron.
- If a servo is moving in wrong direction, reversing the direction in Outputs screen solves this.
- The Mixer is all about control logic. Any mechanical differences should be handled in the Outputs screen and not inside the Mixer.
1. Basic 4 channel
2. Elevon
3. Vtail
4. Aileron differential
5. Tailerons
6. Flaperons
7. Crow braking
8. Flaps working as ailerons
9. Differential thrust
10. Throttle elevator mixing
11. Variable steering depending on throttle
12. Adjust idle throttle with knob
13. Adjust maximum throttle with knob
14. Simple throttle cut
15. Sticky throttle cut
16. Landing gear sequencer
17. Landing gear sequencer - advanced
18. Servo tester
19. Random servo motion generator
20. Random servo motion generator - advanced
21. Oscillator from scratch
22. Automatic aileron rudder mixing
23. Adjust aileron differential with knob

### Example 1: Basic 4 channel

Assuming Aileron servo in Ch1, Elevator servo in Ch2, Throttle in Ch3, Rudder servo in Ch4

1. Ch1 Add Ail (Weight 100)
2. Ch2 Add Ele (Weight -100)
3. Ch3 Add Thr (Weight 100)
4. Ch4 Add Rud (Weight 100)

### Example 2: Elevon

Left servo in Ch1, right servo in Ch2

1. Ch1 Add Ail (Weight -50)
2. Ch1 Add Ele (Weight -50)
3. Ch2 Add Ail (Weight 50)
4. Ch2 Add Ele (Weight -50)

### Example 3: Vtail

Left servo in Ch2, right servo in Ch4

1. Ch2 Add Rud (Weight 50)
2. Ch2 Add Ele (Weight -50)
3. Ch4 Add Rud (Weight -50)
4. Ch4 Add Ele (Weight -50)

### Example 4: Aileron differential

Left aileron in Ch1, right aileron in Ch8. We want the downward going aileron to get less displaced than the upward going aileron. Due to differences in lift and air pressure on the top and bottom wing surfaces, the aileron surface produces more drag when it moves down than when it moves up. This tends to cause an adverse yaw effect hence the need for aileron differential.

1. Ch1 Add Ail (Weight -100, Diff 30)
2. Ch8 Add Ail (Weight 100, Diff 30)

### Example 5: Tailerons

Left Elevator servo in Ch6, Right Elevator servo in Ch7. The mix is turned on/off with SwG.

1. Ch6 Add Ele (Weight -60)
2. Ch6 Add Ail (Weight -40, Switch SwG_Down)
3. Ch7 Add Ele (Weight -60)
4. Ch7 Add Ail (Weight 40, Switch SwG_Down)

### Example 6: Flaperons

Left aileron in Ch1, right aileron in Ch8. Using SwC to operate the flaperons. When SwC is in upper position, flaperons are off. In middle position half flaperons, and in lower position full flaperons.
For smooth flaperon deployment, we use the slow up/down feature.
1. Ch1 Add Ail (Weight -100, Diff 30)
2. Ch1 Add SwC (Weight -40, Offset -40, SlowUp 1 s, SlowDown 1 s)
3. Ch8 Add Ail (Weight 100, Diff 30)
4. Ch8 Add SwC (Weight -40, Offset -40, SlowUp 1 s, SlowDown 1 s)

### Example 7: Crow braking

Left ail servo in Ch1, Right Ail servo in Ch8, left flap servo in Ch5, right flap servo in Ch6.
Using the three position SwC for operation. Normal aileron action occurs when SwC is in upper or middle position. Half flaps are deployed when SwC is in middle position. When SwC is in lower position, both ailerons move upward and full flaps are deployed.
1. Ch1 | Add Ail (Weight -100, Diff 30)
2. Ch1 | Add SwC (Weight 60, Func x>0, SlowUp 1 s, SlowDown 1 s)
3. Ch8 | Add Ail (Weight 100, Diff 30)
4. Ch8 | Add SwC (Weight 60, Func x>0, SlowUp 1 s, SlowDown 1 s)
5. Ch5 | Add SwC (Weight -50, Offset -50, SlowUp 1 s, SlowDown 1 s)
6. Ch6 | Add Ch5 (Weight 100)

### Example 8: Flaps working as ailerons

This mix allows the entire trailing edge of the wing (aileron and flap) to operate as ailerons. Assuming the left flap servo in Ch5, right flap servo in Ch6.
Using a two position switch e.g. SwD to switch between flap mode and aileron mode.
Using the three position SwC to set the flap position in flap mode.
1. Ch5 | Add | SwC (Weight -50, Offset -50)
2. Ch5 | RplcW Ail (Weight -100, Diff 20, Switch SwD_Down)
3. Ch6 | Add | SwC (Weight -50, Offset -50)
4. Ch6 | RplcW Ail (Weight 100, Diff 20, Switch SwD_Down)

### Example 9: Differential thrust

Left motor in Ch3, right motor in Ch7. We can use a switch e.g. SwE to turn the differential thrust off while in the air. Also assume the Rud source is the X1 axis

1. Ch3 Add Thr (Weight 100)
2. Ch3 Add X1 (Weight 40, Switch SwE_Down)
3. Ch7 Add Thr (Weight 100)
4. Ch7 Add X1 (Weight -40, Switch SwE_Down)

For safety, we also need to set Failsafe for both Ch3 and Ch7 in the 'Outputs' screen.
We can also add throttle cut by specifying an override switch and a value of -100.

### Example 10: Throttle elevator mixing

When the throttle is increased, some down elevator can be added to counteract the tendency of the model gaining altitude when the throttle increases.

1. Ch2 Add Ele (Weight -100)
2. Ch2 Add Thr (Weight -20, Offset -20)

### Example 11: Variable steering depending on throttle position

We want the steering response to reduce with increasing throttle. Assuming we use the X1 axis to steer, Y1 axis as our throttle source, and the steering servo is on Ch6,

1. Ch6 Add X1 (Weight 100)
2. Ch6 Mltply Y1 (Weight -40, Offset 60)

### Example 12: Adjust idle throttle with knob

Suppose we want to adjust the idle setting of the engine, without affecting full throttle. Assuming the throttle servo is in Ch3,

1. Ch3 | Add | KnobA (Weight 20, Offset 20)
2. Ch3 | Mltply Thrt (Weight -50, Offset 50)
3. Ch3 | Add | Thrt (Weight 100)

### Example 13: Adjust maximum throttle with knob

We can adjust the maximum throttle without affecting the low throttle setting. Assuming the motor is in Ch3,

1. Ch3 | Add | KnobA (Weight 20, Offset -20)
2. Ch3 | Mltply Thrt (Weight 50, Offset 50)
3. Ch3 | Add | Thrt (Weight 100)

### Example 14: Simple throttle cut

Assuming Ch3 is the throttle channel, and assigning SwA for cut. When SwA is in the up position, Ch3 is locked to -100, otherwise the Throttle input is sent to Ch3.

1. Ch3 Add Thrt (Weight 100)
2. Ch3 RplcW Max (Weight -100, Switch SwA_Up)

Alternatively, a much safer throttle cut can be achieved in the Outputs screen by specifying the override as SwA and value -100.

### Example 15: Sticky throttle cut

Assuming Ch3 is the throttle channel, and assigning SwA for cut. Also assume our Throttle source is Y1 axis. We want the throttle cut whenever SwA is in the up position, but to only remove the cut when the throttle is at minimum and

SwA is in the down position.
This example makes use of logical switches as follows.

L1
Func: | Latch
Set: | SwA_Up
Reset: L3

L2
Func: a==x
Value1: Y1
Value2: -100

L3
Func: AND
Value1: SwA_down
Value2: L2

Then in the mixer

1. Ch3 Add Thrt (Weight 100)
2. Ch3 RplcW Max (Weight -100, Switch L1)

Alternatively, a much safer throttle cut can be achieved in the Outputs screen by specifying the override as L1 and value -100.

### Example 16: Landing gear sequencer (gear doors stay open after gear is extended)

The sequence we want upon flicking the switch is: doors open, gear extends. Similarly in the opposite direction: gear retracts, doors close. Using SwD for operation and assuming gear doors on Ch6 and gear on Ch7.

1. Ch6 Add SwD (Weight 100, DelayUp 0 s, DelayDown 3 s, SlowUp 2 s, SlowDown 2 s)
2. Ch7 Add SwD (Weight 100, DelayUp 3 s, DelayDown 0 s, SlowUp 2 s, SlowDown 2 s)

Alternative method that uses custom curves

Set up two custom curves as follows.

Curve1
Type: 3 point
Point(x,y): PtA(-100,-100) PtB(0,100) PtC(100,100)

Curve2
Type: 3 point
Point(x,y): PtA(-100,-100) PtB(0,-100) PtC(100,100)

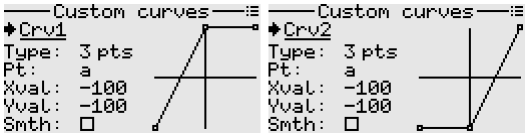
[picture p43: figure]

Then in the mixer, assuming gear door servos on Ch7, gear servos on Ch8, and using SwD to operate,

//Create a source that slowly ramps
1. Virt1 Add SwD (Weight 100, SlowUp 5 s, SlowDown 5 s)

//Apply curve1 for the door sequence
2. Ch7 Add Virt1 (Weight 100, Custom Curve1)

//Apply curve2 for the gear sequence
3. Ch8 Add Virt1 (Weight 100, Custom Curve2)

### Example 17: Landing gear sequencer (gear doors close after gear is extended)

The extend sequence is doors open, gear is lowered, doors close.
The retract sequence is doors open, gear retracts, doors close.
We can achieve the above using custom curves in combination with a slowed switch.

Servo version

Set up two custom curves as follows.

Curve1
Type: 4 point
Point(x,y): PtA(-100,-100) PtB(-50,100) PtC(50,100) PtD(100,-100)

Curve2
Type: 4 point
Point(x,y): PtA(-100,-100) PtB(-50,-100) PtC(50,100) PtD(100,100)

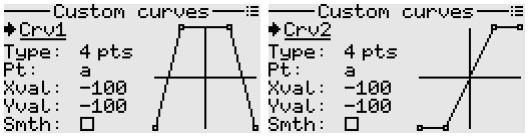
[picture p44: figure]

Then in the mixer, assuming gear door servos on Ch7, gear servos on Ch8, and using SwD to operate,

//Create a source that slowly ramps
1. Virt1 Add SwD (Weight 100, SlowUp 7 s, SlowDown 7 s)

//Apply curve1 for the door sequence
2. Ch7 Add Virt1 (Weight 100, Custom Curve1)

//Apply curve2 for the gear sequence
3. Ch8 Add Virt1 (Weight 100, Custom Curve2)

Retract actuator version

Most electric retract actuators require an on/off control signal, so this example is designed to work with these.
Set up three custom curves as follows.

Curve1
Type: 4 point
Point(x,y): PtA(-100,-100) PtB(-50,100) PtC(50,100) PtD(100,-100)

Curve2
Type: 4 point
Point(x,y): PtA(-100,-100) PtB(-50,-100) PtC(-50,100) PtD(100,100)

Curve3
Type: 4 point
Point(x,y): PtA(-100,-100) PtB(50,-100) PtC(50,100) PtD(100,100)

Then in the mixer, assuming gear door servos on Ch7, gear retracts on Ch8, and using SwD to operate,

//Create a source that slowly ramps
1. Virt1 Add | SwD | (Weight 100, SlowUp 10 s, SlowDown 10 s)

//Apply curve1 for the door sequence
2. Ch7 | Add | Virt1 (Weight 100, Custom Curve1)

//Apply curve2 for the gear extend sequence
3. Ch8 | Add | Virt1 (Weight 100, Custom Curve2)

//Apply curve3 for the gear retract sequence
4. Ch8 RplcW Virt1 (Weight 100, Custom Curve3, Switch SwD_Up)

We can, if necessary, set Ch8 to 'Digital' mode in the receiver output configuration screen.

### Example 18: Servo tester

We can program a simple servo tester that repeatedly moves a servo back and forth.
In the Extras menu, navigate to Function generator and select the desired movement type.
Then in the mixer, assuming the servo is connected to Ch8,
1. Ch8 Add Fgen1 (Weight 100)

We can also make it more interesting by adding the ability to switch between waveforms or patterns via a switch. This is left as an exercise.

### Example 19: Random servo motion generator

Suppose we have a model equipped with a turret, or a figure. We want the servo to move automatically but in a random and intermittent manner.
We can achieve this with function generators and logical switches as follows.

Fgen1
Waveform: Random
Interval: 2.0 s

Fgen2
Waveform: Random
Interval: 1.3 s

L1
Func: a>x
Value1: Fgen2
Value2: 0

Then in the mixer, assuming our servo is on Ch7,

1. Ch7 | Add | Fgen1 (Weight 100)
2. Ch7 | Hold | (Switch L1)
3. Ch7 | RplcW Ch7 | (Weight 100, SlowUp 2 s, SlowDown 2 s)

Explanation:
Fgen1 generates a random position periodically, Fgen2 via Logical switch L1 is used to hold the output randomly to create the impression of intermittent motion. The last mixer line helps smooth the movement.
If desired, we can also incorporate a custom curve to sort of bias the generated servo positions, for example if we want our turret be pointing around the middle most of the time.
We can also easily modify the setup to include an extra switch to manually stop the motion.

### Example 20: Random servo motion generator (advanced version)

This example generates a random servo position at a random interval, with an added effect of random intermittency, and random selection between two speeds.
Furthermore, a physical switch SwE is used to start/stop the random motion of the servo.

Fgen1
Waveform: | Random
Interval mode: Variable
Min Interval: 1.0 s
Max Interval: 2.0 s
Modulator: Fgen2

Fgen2 (modulates the interval of Fgen1)
Waveform: | Random
Interval mode: Fixed
Interval: | 1.0 s

Fgen3 (used for the intermittent motion)
Waveform: | Random
Interval mode: Fixed
Interval: | 1.0 s

Fgen4 (used for the selection between two speeds)
Waveform: | Random
Interval mode: Fixed
Interval: | 2.0 s

Then set up two logical switches as follows.

L1
Func: a>x
Value1: Fgen3
Value2: 0

L2
Func: a>x
Value1: Fgen4
Value2: 0

Then in the mixer, assuming our servo is on Ch7,

1. Ch7 | Add | Fgen1 (Weight 100)
2. Ch7 | Hold | (Switch L1)
3. Ch7 | RplcW Max | (Weight 0, SwE_Up)

4. Ch7 | RplcW Ch7 | (Weight 100, SlowUp 5 s, SlowDown 5 s, Switch
L2)
5. Ch7 | RplcW Ch7 | (Weight 100, SlowUp 2 s, SlowDown 2 s)

### Example 21: Oscillation without using the built-in function generator

Here is a way to create a crude oscillator from scratch.
Set up a custom curve that defines the shape of our arbitrary waveform. For example,

Curve1
Type: 5 point
Point(x,y): PtA(-100,0) PtB(-50,-100) PtC(0,0) PtD(50,100), PtE(100, 0)
Smooth: True

Then define a logical switch as follows.

L1
Func: a<x
Value1: Virt1
Value2: 100

Then in the mixer, we make use of the 'slow' feature on the L1 mixer input. This essentially creates a sawtooth waveform on Virt1. Assuming our final output is on Ch1, we specify the input as Virt1 and apply the custom curve.

1. Virt1 Add L1 | (Weight 100, SlowUp 1 s, SlowDown 0 s)
2. Ch1 | Add Virt1 (Weight 100, Custom Curve1)

### Example 22: Aileron rudder mixing with automatic switching

When the Rudder stick is centered and the Aileron stick is moved away from center, the mix is activated (Aileron stick now controls the rudder).
The mix is deactivated as soon as the Rudder stick is moved away from center (Rudder stick now controls the Rudder).
When both sticks are centered the mix gets activated again.
We can achieve this behaviour with the help of logical switches as follows.

L1
Func: a==x
Value1: Rud
Value2: 0

L2
Func: a==x
Value1: Ail
Value2: 0

L3
Func: AND
Value1: L1
Value2: L2

L4
Func: | Latch
Set: | L3
Reset: !L1

Then in the mixer, assuming the rudder servo is on Ch4,

1. Virt1 Add | Max | (Weight 100, Switch L4)
2. Ch4 | Add | Ail | (Weight 100, No trim)
3. Ch4 | Mltply Virt1 (Weight 100, SlowDown 1 s)
4. Ch4 | Add | Rud | (Weight 100)

Here, Virt1 is used to smooth the transition from the Aileron stick to the Rudder stick.

### Example 23: Adjust aileron differential with the knob

This example illustrates a method for adjusting aileron differential in-flight, eliminating the need to land whenever we want to tweak the setting. It is quite handy for experimenting with different values and helping with fine tuning.
As we rotate the knob clockwise, the differential increases from 0% to 100%. Set up a logical switch as follows.

L1
Func: a>x
Value1: Ail
Value2: 0

Then in the mixer, assuming the left aileron servo in Ch1, right in Ch8,

1. Ch1 | Add | Ail | (Weight -100, No trim)
2. Ch1 | Mltply KnobB (Weight -50, Offset 50, Switch L1)
3. Ch1 | Add | X2Trim (Weight -100)
4. Ch8 | Add | Ail | (Weight 100, No trim)
5. Ch8 | Mltply KnobB (Weight -50, Offset 50, Switch !L1)
6. Ch8 | Add | X2Trim (Weight 100)

Explanation:
Differential is applied to the downward going aileron. When the Ail stick is moved right, we apply differential to the left aileron. Similarly, when the Ail stick is moved left, we apply differential to the right aileron.
We detect the direction of the Ail stick via the logical switch L1 and use it to selectively apply the differential effect via a multiply mix.
For this case, we also decouple the trim and add it afterward, to prevent it being affected by the differential.

# Outputs

Outputs are the last stage of the processing chain (Inputs ---> Mixer ---> Outputs).
It is where final adjustments to the control data are made before transmission to the receiver.
- Reverse: Useful for correcting the servo or actuator direction relative to the controls.
- Subtrim: Adjusts the center position of the servo or actuator. A side effect of using subtrim is that it causes clipping at the ends. E.g. if the mixer is outputting -100 to 100, a subtrim of say +5 shifts the usable range of the servo to -95 to 100.
- Override: This is mainly a safety feature used for throttle cut, etc. It overrides the channel's output with the specified value when the activation switch is on.
- Failsafe: The receiver will output the specified value after about 1 second of signal loss from the transmitter. Supported modes are Hold, No pulse, or Custom value.
- Hold - The receiver continues outputting the last value received prior to signal loss.
- No pulse - The receiver stops outputting pulses when signal loss occurs.
- Custom value - The receiver outputs a user-defined preset value.

Always ensure that the correct failsafe setting is being used for the respective channel, especially for channels controlling motors or engines.

- Endpoints: Sets the overall travel or endpoints of the servo arm movement. Useful when we want to avoid any potential binding of a linkage or surface.
- Curve: Specifies the custom curve to use for this output. Useful when we want to correct for linkage geometry, mechanical differences, etc.

# Custom curves

These can be used in the mixer and the outputs screen. They basically define a relation between an input (along the x) and output (along the y).
Any point/node on the curve can be freely moved around to get the desired shape of curve. Up to 10 points/nodes can be defined.
The curve can also be optionally smoothed, although this feature should be used sparingly as it is relatively CPU intensive.

Combining two curves for extra points or nodes

If more curve points are needed, a work around is to combine two curves by switching out one for the other in the mixer, with help of a logical switch.

## Usage examples

Below are some examples demonstrating the use of custom curves.

- Landing gear sequencer
- Landing gear sequencer - advanced
- Oscillator from scratch

# Logical switches

These can be used to combine various conditions, compare values, etc. They are in essence user programmed virtual switches. They produce an on/off output.

The available functions can be categorized into the following types.

- Comparators (Greater than, Less than, Equal, Greater than or equal, Less than or equal)
- Combinational (AND, OR, XOR)
- Latches (SR latch)
- Flip-flops (Toggle)
- Generators (Pulse)

## Usage examples

1. A mix activated by combination of two switches
2. LED lights that flash when flight battery is low
3. Stopwatch operated by a single momentary switch
4. Throttle timer - simple
5. Throttle timer - advanced
6. Zero crossing detection
7. Using a momentary switch to cycle among values
8. Detecting receiver connection or disconnection

### Example 1: A mix activated by combination of two switches

Suppose we want a mix to be turned on only when two switches (e.g. SwA, SwB) are both on. We need to set up a logical switch say L1 as follows.

L1
Functn: AND
Value1: SwA_down
Value2: SwB_down

Then in the mixer, we simply have to set the control switch to L1.

### Example 2: LED lights that flash when flight battery is low

Suppose we have a model that is equipped with some LED lights that we want to switch on when the flight battery voltage (telemetry) falls below a certain threshold for more than say five seconds.
We can easily achieve this like so.

L1
Functn: a<x
Value1: FlghtBatt
Value2: 10.80 V
Delay: 5.0 s

L2
Functn: Pulse
Width: 1.0 s
Period: 2.0 s

Then in the mixer, we simply use L2 as the input source and L1 as the control switch for the mix, to operate the channel assigned to the LED lights.

### Example 3: Stopwatch operated by a single momentary switch for start/stop and reset

When the switch is clicked, the timer runs/stops. When the switch is held long enough, the timer is reset.
For this, we set up two logical switches to operate the timer as below, assuming SwH is our momentary switch.

L1
Functn: Toggle
Clock: SwH_down
Edge: Falling
Clear: L2

L2
Functn: a>x
Value1: SwH
Value2: 0
Delay: 0.5 s

Timer1
Switch: L1
Reset: L2

Explanation:
The output of L1 toggles whenever SwH is released. L1 is then used to run/stop the timer.

L2 goes high when SwH is down for more than 0.5 seconds, providing a signal for resetting the timer. L2 is also used to clear the state of L1 such that resetting the timer does not falsely trigger it to run on releasing the switch.

### Example 4: Throttle timer (simple)

When the throttle is moved beyond a certain threshold, the timer runs.
Also if we have a throttle cut function on say SwA, we want the timer to only run when throttle cut is inactive.
Assume the throttle source is the Y1 axis.

L1
Functn: a>x
Value1: Y1
Value2: -90

L2
Functn: AND
Value1: L1
Value2: SwA_down

Timer1
Switch: L2

### Example 5: Throttle timer (advanced)

Suppose we want the speed at which the timer runs to be proportional to the throttle value.
Also if we have a throttle cut function on say SwA, we want the timer to only run when throttle cut is inactive.
Assume our throttle source is the Y1 axis.

Method 1:

Using the built-in function generator to generate a pulse width modulated signal that controls the timer.

Fgen1
Waveform: Pulse
Width mode: Variable
Modulator: Y1
Reverse: | False
Period: | 1.0 s

L1
Functn: a>x
Value1: Fgen1
Value2: 0

L2
Functn: AND
Value1: L1
Value2: SwA_down

Timer1
Switch: L2

Explanation:
The throttle source (Y1 axis) is used to modulate the pulse width of the generated pulse waveform. Since the timer only accepts signals from control switches, we need to convert the output from the function generator. This is done via L1. When SwA is in the down position, the resulting signal is passed to the timer to control it.

Method 2:

Using the mixer and a virtual channel to create a pulse width modulated signal that controls the timer.

Mixer
1. Virt1 Add L1 (Weight 99, SlowUp 0.5 s, SlowDown 0.5 s)

L1
Functn: Pulse
Width: 0.5 s
Period: 1.0 s

L2
Functn: a>b
Value1: Y1
Value2: Virt1

L3
Functn: AND
Value1: L2
Value2: SwA_down

Timer1
Switch: L3

Explanation:
L1 and Virt1 effectively create a triangle waveform, which gets compared with the value of the throttle source (Y1 axis) via L2. When SwA is in the down position, the resulting signal is passed to the timer to control it.

If desired, we can also include a custom curve through a virtual channel, to compensate for the real-world nonlinear relationship between current draw and throttle value.

### Example 6: Zero crossing detection

Suppose we want to detect whenever a value from say a function generator crosses zero, so that we can trigger some other action.

L1
Functn: a>=x
Value1: Fgen1
Value2: 0

L2
Functn: |delta|>x
Value1: L1
Value2: 0
Direction: Both

L2 will now output a brief pulse whenever the output of the function generator crosses zero.

### Example 7: Using a momentary switch to cycle among four values or states

Suppose we want an output channel to cycle among four levels whenever we click the momentary switch.

Method 1:

Set up a '2-bit' binary counter with its outputs on L2 and L1 as follows.

L1
Functn: Toggle
Clock: SwH_down
Edge: Rising

L2
Functn: Toggle
Clock: L1
Edge: Falling

Use a truth table to set up logical switches L3, L4, L5, and L6

L2 | L1
0 | 0 | L3
0 | 1 | L4
1 | 0 | L5
1 | 1 | L6

L3
Functn: AND
Value1: !L2

Value2: !L1

L4
Functn: AND
Value1: !L2
Value2: L1

L5
Functn: AND
Value1: L2
Value2: !L1

L6
Functn: AND
Value1: L2
Value2: L1

Then in the Mixer,

1. Ch1 RplcW Max (Weight -100, Switch L3)
2. Ch1 RplcW Max (weight -33, | Switch L4)
3. Ch1 RplcW Max (weight 33, | Switch L5)
4. Ch1 RplcW Max (weight 100, Switch L6)

Method 2:

This makes use of the built-in counter as follows.

Counter1
Clock: | SwH_down
Edge: | Rising
Modulus: 4
Direction: Up

L3
Functn: a==x
Value1: Counter1
Value2: 0

L4
Functn: a==x
Value1: Counter1
Value2: 1

L5
Functn: a==x

Value1: Counter1
Value2: 2

L6
Functn: a==x
Value1: Counter1
Value2: 3

Then in the Mixer,

1. Ch1 RplcW Max (Weight -100, Switch L3)
2. Ch1 RplcW Max (weight -33, | Switch L4)
3. Ch1 RplcW Max (weight 33, | Switch L5)
4. Ch1 RplcW Max (weight 100, Switch L6)

Method 3:

This makes use of the built-in counter directly in the Mixer. See the example under counters.

### Example 8: Detecting receiver connection or disconnection

This relies on the Link Quality telemetry to detect connection/disconnection of a receiver.
First, configure the Link Quality telemetry (premade template already available). Then set up a logical switch and custom notifications as follows.

L1
Functn: a>x
Value1: LinkQlty
Value2: 0

Notification1
Switch: L1
Tone: | (Your preferred tone)
Text: | RX connect

Notification2
Switch: !L1
Tone: | (Your preferred tone)
Text: | RX disconnect

This example can also be adapted to detect when telemetry from a sensor is lost or recovered.

# Function generators

These produce various waveforms over a range of frequencies or periods. They are implemented as low frequency oscillators, hence the reason why period instead of frequency is specifiable.
Supported waveforms are sine, square, triangle, sawtooth, pulse, and random. The function generators are capable of frequency modulation, with smooth transition between frequencies.

## Usage examples

Below are some examples making use of function generators.

- Servo tester
- Random servo motion generator
- Random servo motion generator - advanced

# Timers

Timers are used to time events, etc. The system provides up to 3 programmable timers.
Timers can be configured to count up or count down.
In count down mode, an audible alarm is played when the timer reaches zero. The timer continues to count with a negative sign.
- Name: A name for the timer, otherwise a generic name is used.
- Switch: The control switch used to start and stop the timer. This is optional, as the timer can also be started or stopped from the context menu.
- Reset: The control switch used to reset the timer. This is optional, as the timer can also be reset from the context menu.
- Initial: The initial time if a countdown timer. If not specified, the timer will count up. A time picker dialog is used to easily set the initial time.
- Persist: Whether the timer is persistent i.e. if the value should be remembered between sessions.

## Examples

- Stopwatch operated by a single momentary switch
- Throttle timer - simple
- Throttle timer - advanced

# Counters

A counter stores and shows the number of times a particular event has occurred, in relationship to a clock signal.

- Clock: The control switch that triggers the counter.
- Edge: Rising, Falling, or Dual edge triggering. Applies to the clock signal.
- Clear: The control switch that clears the counter register to zero.
- Modulus: The number of states in its count sequence. E.g. mod 4 produces the sequence 0, 1, 2, 3.
- Direction: Determines whether counts will increment or decrement.
- Rollover: Rolls back over to start counting again from zero.
- Persist: Whether to remember the value in the counter's register between sessions.

In advanced mode, the counter behaves as an up/down counter using separate "up" and "down" clocks for increment and decrement respectively.

## Usage examples

1. Using a 3 position momentary switch to sequentially select among values
2. Using a 3 position momentary switch to continuously adjust a value

### Example 1: Using a 3 position momentary switch to sequentially select among values

This example demonstrates use of the counter directly inside the mixer.
When the momentary switch is pushed in the downward direction, the counter value increments. Similarly, pushing the momentary switch in the opposite direction decrements the counter value.
In the counter screen context menu, change the counter type to advanced. Assuming SwG is our 3 position momentary switch, set up the counter as follows.

Counter1
Inc clock: SwG_down

Inc edge: Rising
Dec clock: SwG_up
Dec edge: | Rising
Modulus: | 4
Rollover: | False

Then in the Mixer,

1. Ch1 Add Counter1 (Weight 100)

Note: The mixer automatically maps the counter's value in proportion to the counter's modulus.
For example if the modulus is 4, then mapping is {(0,-100), (1,-33), (2,33), (3,100)}.

### Example 2: Using a 3 position momentary switch to continuously adjust a value

When the switch is pushed in one direction, the counter continuously increments until the switch is released. Similarly, the counter continuously decrements when the switch is pushed in the opposite direction.

For this, we set up some logical switches, like so.

L1
Functn: AND
Value1: !L1
Value2: SwG_down

L2
Functn: AND
Value1: !L2
Value2: SwG_up

In the above, we are essentially creating ring oscillators, though with only a single NOT stage.

This exploits the fact that the main program loop runs at about 50 times per second, thus we generate oscillations of about 25 Hz frequency.

We then use L1 and L2 to clock the counter as follows.

Counter1
Inc clock: L1
Inc edge: Rising
Dec clock: L2
Dec edge: | Rising
Modulus: | 100
Rollover: | False

Here, the modulus can be any value. For example, if the modulus is 100, it will take 4 seconds (=100/25) to increment from 0 to 99.

We then use the counter as input inside the Mixer like follows.

1. Ch1 Add Counter1 (Weight 100)

The mixer automatically maps the counter's value in proportion to the counter's modulus, to the range -100 to 100.

We can also specify some "slow up/down" of 4 seconds in the mixer to smooth the output.

Alternatively, we can adapt this example to use a self-centering stick axis like X4, instead of the momentary switch.

# Notifications

Notifications are user-programmable and provide audible alarms to report about events.

- Enable: Whether the notification is enabled or disabled. Only enabled notifications will be sounded and displayed.
- Switch: The control switch used to trigger the notification. The notification gets only triggered on the positive going edge, i.e. when the state of the switch changes from low to high.
- Tone: The tune to play when the notification is triggered.
- Text: Optional text that will be displayed, as a toast message on the screen.

Note:
System events like low transmitter battery, inactivity, etc. are natively handled by the system, thus there is no need to configure them inside custom notifications.

## Usage examples

- Detecting receiver connection or disconnection

# Safety checks

These checks are done before loading a model and on start up.
Positions of switches as well as the throttle source are checked, depending on the setting.
A warning will be shown if the set conditions are not met.

# Trim setup

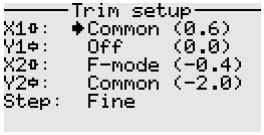
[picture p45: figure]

Available states are as follows.

- Common: Applies the same trim value across all flight modes.
- F-mode: Applies independent trim settings for each flight mode.
- Off: Trim is disabled globally for this axis, for example when we do not want trim on the throttle.

The Step setting determines how fast and how fine the trims move. Available options are Coarse, Medium, and Fine.

# Flight modes

Flight modes allow you to easily reconfigure settings such as mixes and trim values with the simple flip of a switch. While it's possible to achieve similar adjustments using multiple switches, having the ability to make all these changes with just one switch is undoubtedly more efficient and convenient.

- Name: A name/label for this flight mode.
- Switch: The control switch that activates this flight mode.
- Fade-in: The transition time to effect the trim setting for this flight mode.

# Telemetry

## General telemetry

The receiver has built-in basic telemetry i.e. external voltage, RSSI, and packet rate. To measure other parameters, you will have to build custom sensors and extend the receiver firmware to support these.
Telemetry values are transmitted as 16-bit signed integers.
To quickly mute/unmute telemetry alarms, long press the Down key on the home screen.

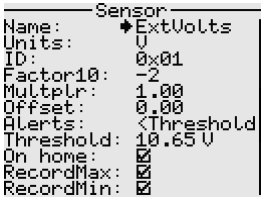
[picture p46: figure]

- Name: The sensor name.
- Units: The units of measurement.
- ID: This is the sensor ID, which must be unique. However, the same ID can be used for example to display a value in multiple ways.
- Factor10: The raw value is multiplied by 10 to power this factor. Useful when we want to scale the value.
- Multiplier: The raw value is multiplied by this number. Useful when we want to scale the value.
- Alerts: This parameter specifies how the alarm behaves.
- Threshold: This is the value below or above which the telemetry alarm will be sounded. The telemetry value will also flash when in alarm state.
- On home: Whether to automatically show the telemetry sensor on the home screen.
- Record max, and record min: Whether to track the max/min values received from the sensor. Useful for simple stats. Note that max and min are sensitive to outliers hence the filtering and smoothing should be done before sending the telemetry to the transmitter.

## GNSS telemetry

GNSS telemetry is also supported. A premade template is used to add the GNSS sensor to the telemetry screen.
The receiver directly connects to the GNSS/GPS module via serial (UART), and handles parsing of the NMEA sentences as well as data conversion. GPS, GLONASS, BeiDou, Galileo are supported.
The system remembers the last known location in case of a lost model, even when the transmitter is powered off.
Various units of measurement can be displayed; metric and imperial supported.

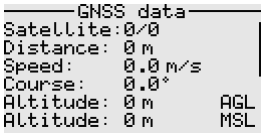
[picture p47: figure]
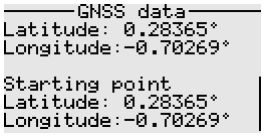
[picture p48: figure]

- Satellites: The number of satellites in use / in view. "Fix" is appended when we have a position fix.
- Distance: The calculated distance between the model's current location and the home location (starting point). If the displayed distance is inaccurate, simply reset the starting point from the context menu.
- Speed: The speed over ground. This is the speed at which your model is moving relative to the Earth's surface. The last received value is shown when there is no incoming telemetry or no position fix.
- Course: The course over ground. This is direction of movement of your model over the Earth's surface, irrespective of the direction your model is pointing. The last received value is shown when there is no incoming telemetry or no position fix.
- Altitude AGL: The altitude above ground level. If the value is inaccurate, reset it from the context menu. The last received value is shown when there is no incoming telemetry or no position fix.
- Altitude MSL: The altitude relative to mean sea level. The last received value is shown when there is no incoming telemetry or no position fix.
- Latitude and Longitude: The location coordinates of the model. Displays the last known location when there is no incoming telemetry or no position fix.
- Starting point: Displays the coordinates of the home location.

# System settings

The System menu provides comprehensive configuration options so you can tailor the device to your needs. Settings are organized into categories for easy navigation and quick access to the options you want. Use this menu to adjust settings that affect overall system operation.

## RF setup

- RF output: Toggle the RF transceiver on or off. When enabled, an RF icon appears on the home screen. RF output is automatically disabled when switching to a different model for safety, thus it has to be re-enabled manually after changing models.
- RF power: Adjust the transceiver's transmission power. Higher power increases range but uses more battery.

## Sound

- Enable: Toggle all sounds on or off. When off, a mute icon appears on the home screen.
Holding the Down key while powering on will also mute all sounds.
- Inactivity: Turn the inactivity alarm on or off. When enabled, a warning tone plays after a period without user interaction.

- Switches: Play a tone when any physical switch is moved.
- Knobs: Play a tone when a knob with a center detent is positioned at center.
- Keys: Play a tone when the physical UI buttons are pressed.
- Trims: Play a tone while trims are being adjusted.
- Trim tone: Set the trim tone behaviour. Fixed pitch (single frequency) or Variable pitch (changes with trim position).

## Backlight

- Enable: Enables/disables the backlight. This may be useful for example to save energy on certain kinds of LCDs.
- Brightness: Controls the brightness level of the display. Higher brightness causes higher battery consumption.
- Timeout: Specifies the time before the backlight is turned off when the handset is inactive.
- Wake up: Specifies how the backlight is triggered on. Keys or Activity. When set to Keys, only the UI keys can wake up the backlight. Setting to Activity enables all the physical controls to wake up the backlight. This is useful when we want the backlight to stay on when operating a model, especially for LCDs that are not sunlight readable.
- Key filter: When enabled, the first key press only wakes the backlight without triggering any event in the User Interface. This setting is useful for LCDs that are not sunlight readable.

## Appearance

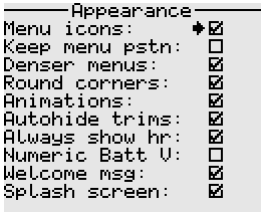
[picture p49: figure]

- Menu icons: Show or hide icons in the main menu.
- Keep menu position: Whether to remember the scroll position in the major menus (Main menu, System, Extras, etc.). This setting does not apply to context menus.
- Denser menus: Increases the number of entries shown in the major menus.
- Round corners: Turns on/off rounded corners in menus, dialog boxes, etc.
- Animations: Turns animations on/off for toast messages, loading spinners, etc.
- Autohide trims: Hides the trim bars on the home screen when the trims buttons are not being interacted with.
- Always show hours: Whether to always show the hours digits for timers.
- Numeric battery voltage: Replaces the graphical battery gauge with the actual voltage readout on the home screen.
- Welcome message: Turns on/off the "Welcome" message when starting up the handset.
- Splash screen: Whether to show the user's custom splash screen during boot. To make a custom splash screen, create a monochrome bitmap image with 128x64 px resolution and save it as "SPLASH.BMP" inside the "IMAGES" folder on the SD card.

## Miscellaneous

- Auto select input: This enables automatic detection of the moved physical control when editing sources or switches, so that we can quickly select the desired control without having to scroll through the options.
- Mixer templates: Whether to enable the default mixer template when creating new models. Turning off this also removes the entry from the mixer context menu.

- Default channel order: Specifies the default channel order when creating new models. E.g., selecting AETR sends Ail to Ch1, Ele to Ch2, Thr to Ch3, and Rud to Ch4 in the mixer. The order can always be overridden in the mixer; this option is merely a time saving feature for new models.
- Inactivity minutes: How long before the inactivity event is triggered, specifically for the inactivity alarm.
- Default GNSS units: Specifies the default units of measurement to use when adding the GNSS telemetry sensor template. Available options are Metric, Imperial, Custom, or None.
When set to Custom, the user can set custom defaults for Distance, Speed, and Altitude.
When set to None, the system prompts the user to select units whenever adding the GNSS sensor.

## Advanced settings

This menu provides access to various advanced system settings. It is protected with a password (if set) to prevent unwanted configuration changes, for instance when we lend out the transmitter.

## Sticks

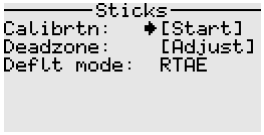
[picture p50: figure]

- Calibration: This starts the stick calibration process.
- Dead zone: This allows to adjust the center dead zone for the stick axes, without re-triggering full calibration.
- Default mode: This determines the default stick axis mapping for the Aileron/Roll, Elevator/Pitch, Rudder/Yaw, and Throttle inputs. It is essentially called "Stick mode" in other RC systems.

### Calibrating the sticks

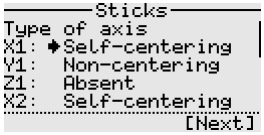
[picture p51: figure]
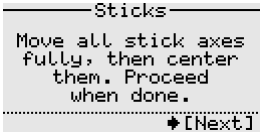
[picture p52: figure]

Procedure:

- Select the axis type: Self-centering (returns to the center), Non-centering or Absent.
- Move each stick axis through its full range. If an axis is self-centering, release it and let it return to center.
- Set the dead zone percentage. This applies around the center to prevent jitter when the stick is centered.

Properly calibrated stick axes always read between -100 to 100 when moved fully. If this is not the case, then redo the calibration, or check your hardware.

How often you need to recalibrate the sticks depends on their build quality and how frequently you use the device. As a guideline, recalibrate:

- After any noticeable drift or inconsistent input.
- After major firmware updates or hardware changes.

## Knobs

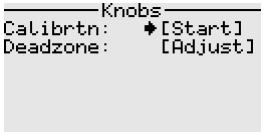
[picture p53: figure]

- Calibration: This starts the knob calibration process.
- Dead zone: This allows to adjust the center dead zone for the knobs, without re-triggering full calibration.

### Calibrating the knobs

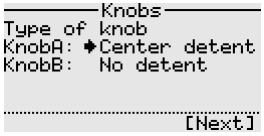
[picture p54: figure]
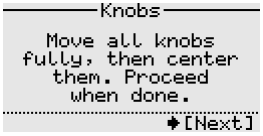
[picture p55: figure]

Procedure:

- Select the knob type: Center detent (mechanical stop at center), No detent, or Absent.
- Rotate each knob through its full range. If a knob has a center detent, return it to the detent position.
- Set the dead zone percentage. Dead zone is applied around the center to prevent jitter when the knob is centered.

Properly calibrated knobs always read between -100 to 100 when moved fully. If this is not the case, then redo the calibration, or check your hardware.

## Switches

This screen allows the user to specify the type of switches they have installed. Supported types are 2 position, 3 position, and their momentary variants. A frequent question is "How about push buttons?". Well, they are actually 2 position momentary switches.

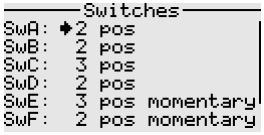
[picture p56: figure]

## Battery

- Gauge min and max: These determine the range of the transmitter battery gauge. The minimum value also serves at the alarm threshold value, below which a low battery warning is shown.
- Multiplier: This specifies the calibration factor for the transmitter battery voltage.

### Calibrating the battery gauge

To calibrate the battery gauge, use a digital multimeter to measure the actual battery voltage at the terminals. Then adjust the multiplier until the displayed voltage on the transmitter matches what the multimeter is showing.

## Security

- Lock models: Locks the model manager screen, preventing access to the models.
- Lock startup: Locks the main menu on startup, effectively preventing changes to all settings (both model and system), unless the correct password is entered.
- Lock on inactivity: Locks the main menu after the system has been idle for the specified inactivity minutes. This setting applies only while the home screen is being displayed.
- Set/Change password: Opens the text edit dialog to edit the password. To remove the existing password, simply clear the field. Setting a password also protects the Advanced system menu.

## Debug

The Debug menu contains options intended primarily for troubleshooting, development, testing, and debugging.

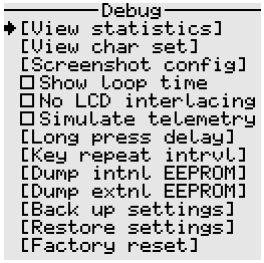
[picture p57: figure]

- View statistics: Displays basic system statistics, including system uptime, available free memory, and RF packet rate.
- View character set: Displays all glyphs included in the system font.
- Screenshot configuration: Assigns a physical switch to trigger screenshot capture.

- Show loop time: Displays the total execution time of the main program loop, measured in milliseconds.
- No LCD interlacing: Disables interlacing for the LCD screen. (Interlacing improves performance on slower displays by splitting the image into alternate frames and updating them across successive program loops.)
- Simulate telemetry: Simulates telemetry data on sensor ID 0x30 for testing purposes.
- Long press delay: Sets the duration that a physical button must be held before a long-press event is recognized. This setting applies to both UI buttons and trim buttons.
- Key repeat interval: Sets the time interval between repeated key events when scrolling through menus and some options, effectively determining the scrolling speed.
- Dump EEPROM: Displays a hexadecimal dump of the EEPROM contents.
- Back up settings: Backs up system settings to the SD card. Model-specific settings are not included in this backup.
- Restore settings: Restores system settings from the SD card.
- Factory reset: Erases all system and model settings, restoring the device to its factory default state. Only data in the EEPROM gets erased; data on the SD card is not affected.

## About

The About menu provides information regarding firmware version, legal notices, credits, and support/contact resources.

# Receiver

Each receiver supports up to 10 channels. To use all the 20 channels, two receivers are required.

## Binding to a receiver

A receiver can be bound as either a main receiver or a secondary receiver.

By default, RC channels 1 to 10 are handled by the main receiver, while RC channels 11 to 20 are handled by the secondary receiver. Only the main receiver can send back telemetry.

To bind, select the bind option, then cycle the power to the receiver. If the binding is successful, a "Success" toast message will be shown and a tune played.

## Configuring receiver outputs

The receiver outputs can be configured from the transmitter to any of the three signal types; servo PWM, digital on-off, or 'normal' PWM.
For example, 'normal' PWM output can be used to control brushed DC motors without the need for complex electronics.
The digital on-off output makes it easy to directly control components such as electromechanical relays and lights.

The servo PWM range can as well be adjusted to get extra travel from a servo, without making physical modifications to the servo.

Note:

1. These configuration settings are stored in the receiver, not the transmitter.
2. Normal PWM is only available on certain pins, depending on the pin mapping.

3. Any changes made take effect immediately upon pressing the 'Write' button.
4. In digital on-off mode, the output value range of -100 to -50 corresponds to LOW, -49 to 49 is ignored, and 50 to 100 corresponds to HIGH.
5. When reusing a receiver between models, always check and set the appropriate signal format before connecting any actuators to the receiver.

# Frequently asked questions

### Where are the mechanical CAD files?

As this is a DIY project, I did not make any detailed mechanical CAD; only a plan layout for the front plate of the transmitter. This is mainly because dimensions of parts differ widely across manufacturers.

### Does it support protocol x?

Out of the box, no; there are just too many different and incompatible protocols. You can however modify the firmware and hardware to support any protocol or module you want. There are also several DIY projects that address this problem specifically, and interfacing to them would not be difficult.

### Is the RF link stable and what is the range?

The RF link is stable enough. Keep in mind that this implementation is not designed for security, and is neither interference nor jamming free.
The range largely depends on the specific RF module, power amplification setting, quality of your antennas, your environment, etc. From my tests, I easily got more than 2 km line of sight with monopole antennas and default LoRa settings, with packet loss of less than 3%. This range is more than necessary to control an RC model (of course you won't be able to see your model at such distance anyway).

### What is the latency of this system? Servo jitter, lag?

Latency varies between 20 to 40 ms maximum between flicking a switch and getting the output on the receiver’s pin. As for servo jitter, none; it is a matter of quality of your servos; I have not experienced any issues with cheap ones like the popular SG90 servos.

### Why still use 8-bit AVR and not something more powerful like a 32-bit ARM microcontroller?

It is what I had lying around at the time. I initially planned to use an STM32 but the chip shortage for these forced me to rethink and revise the design.
I found the Atmega2560 to be performant enough for this application after some clever code optimizations and performance tuning. In fact, it takes roughly 15 ms on average to compute everything including redrawing the screen.

### Can it do voice alerts?

Voice alerts are not currently supported. For now, an alternative is to use custom notifications with tunes to report events.
I plan on working on this in the near future, but I haven't yet found a compelling reason to add them.
SD card is not working or can't be detected.

The card should be formatted with the FAT (FAT16 or FAT32) file system. Other file systems are not supported.

Try to keep the number of files on the card minimal.
Always power the system off before inserting or removing the SD card. Also try using a class 4 or lower, 4 GB or smaller SD card.
I am having trouble binding.

Double check your connections. Make sure the receiver has a stable supply voltage. Also leave enough space between the transmitter and the receiver. During binding, ensure that the power to the receiver is cycled within the binding window (typically 5 seconds), otherwise a timeout occurs.

### The analog controls do not work. I am getting wrong

readings when I move them.

You probably skipped the calibration procedure, or you are doing it wrong. See the section about stick and knob calibration for the proper procedure. The quality of your hardware also matters, even though the system will try its best to cope with low quality gimbals.
If your readings appear reversed, check your connections. You may have to swap the VCC and GND wires on the problematic potentiometer.

### Models and system settings are corrupted after a

firmware update.

Ensure you back up your models to the SD card before performing any firmware updates. You can then restore them from the SD card afterwards.
To back up the system settings, use the corresponding option in the Debug menu.

# Gallery

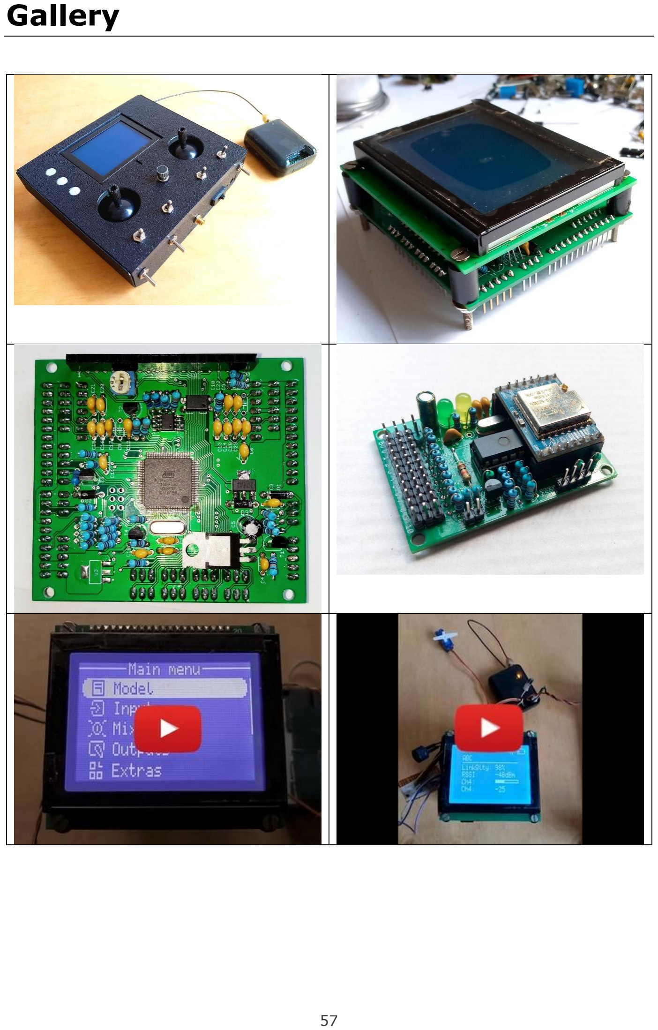
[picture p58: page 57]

# Additional information

For more information, visit https://github.com/buk7456/FreeTX

Disclaimer
This manual is provided for informational purposes only and is subject to change without prior notice. While every effort has been made to ensure the accuracy of the information contained herein, the authors assume no responsibility or liability for any errors, omissions, or inaccuracies that may appear in this manual.

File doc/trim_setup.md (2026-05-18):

# Trim setup

<p align="left">
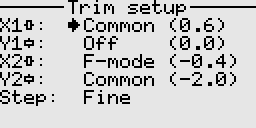
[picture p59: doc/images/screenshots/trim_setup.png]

</p>

Available states are as follows.
- **Common:** Applies the same trim value across all flight modes.
- **F-mode:** Applies independent trim settings for each flight mode.
- **Off:** Trim is disabled globally for this axis, for example when we do not want trim on the throttle.

The Step setting determines how fast and how fine the trims move. Available options are Coarse, Medium, and Fine. 

---

Back to [user guide](user_guide.md).

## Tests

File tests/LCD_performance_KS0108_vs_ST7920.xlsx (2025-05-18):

Screen | Main loop duration (milliseconds) |  |  | Characters on screen
 | KS0108 | ST7920 | Difference
Home | 10.2 | 12.8 | 2.6 | 14
Main menu | 12.5 | 14.5 | 2.0 | 32
Model | 9.9 | 12.5 | 2.6 | 17
Inputs | 10.9 | 13.7 | 2.8 | 37
Mixer | 11.5 | 14.7 | 3.2 | 57
Mixer context menu | 12.0 | 14.9 | 2.9 | 55
Outputs | 12.2 | 15.5 | 3.3 | 71
Custom curves | 12.6 | 15.7 | 3.1 | 53
Logical switches | 11.4 | 14.9 | 3.5 | 62
Function generators | 12.3 | 16.1 | 3.8 | 90
Timers | 12.3 | 15.5 | 3.2 | 62
Telemetry | 9.3 | 12 | 2.7 | 9
System menu | 11.6 | 13.7 | 2.1 | 38
Receiver | 10.1 | 12.9 | 2.8 | 34
Channel monitor | 14.0 | 17.5 | 3.5 | 81
Version info | 11.7 | 15.4 | 3.7 | 84
Disclaimer | 13.3 | 17.4 | 4.1 | 115
Screen buffer | KS0108 | ST7920 | Difference
Transfer duration (interlaced mode) | 3.56 | 5.91 | 2.35
Transfer duration (progressive mode) | 7.12 | 23.64 | 16.52
Firmware version 1.4.0

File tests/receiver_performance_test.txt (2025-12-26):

Optimize -O3 

  parseNMEA(sentence)
  
    $GNRMC,051630.452,V,0017.0190,N,00042.1610,W,0.000,0.00,041224,,,N,V*20     
    180 us
  
    $GNGGA,051630.452,0017.0190,N,00042.1610,W,0,0,,1196.3,M,-12.2,M,,*4E
    164 us
  
    $GPGSV,3,1,11,07,66,249,,02,56,177,,03,42,037,,21,40,163,,1*6C
    144 us
  
  convertGNSSData()
  568 us
    
  writeOutputs()
  636 us
  
  getExternalVoltage()
  288 us
  220 us optimised with dividers that are powers of 2

Optimize -Os

  parseNMEA(sentence)
  
    $GNRMC,051630.452,V,0017.0190,N,00042.1610,W,0.000,0.00,041224,,,N,V*20     
    188 us
  
    $GNGGA,051630.452,0017.0190,N,00042.1610,W,0,0,,1196.3,M,-12.2,M,,*4E
    172 us
  
    $GPGSV,3,1,11,07,66,249,,02,56,177,,03,42,037,,21,40,163,,1*6C
    144 us
  
  convertGNSSData()
  572 us
    
  writeOutputs()
  640 us
  
  getExternalVoltage()
  288 us
  220 us optimised with dividers that are powers of 2

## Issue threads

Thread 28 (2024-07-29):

Colab?

ICantMakeThings, 2024-07-29:
Hey, I'm not sure how to message you, so I made an issue. I'll cut right to the chase.
I want to colab, I think allowing external trx modules (like in bought rc remotes),  something like ELRS, could really open up this project to loads of people. (elrs is basically an open source transmitter thing for fpv drones mainly. And if this project could incorporate it (I already have some code for elrs communication) and potentially other communications, then this could be the ultimate rc remote for all!!!
Idk how quickly I'll respond on here. I don't have notifications, but if you have telegram, I'm guaranteed to respond quickly, >> @ALQUH

Or just close this if you're not interested. Have a nice day.

buk7456, 2024-08-03:
Hello, I have been looking into the documentation for ELRS and CRSF protocol.
It seems there will need to be a few compromises here and there, if these are to be integrated into this project.
I think it would need to be added to the secondary mcu code inside the stx folder, so as to allow for flexibility and not to
break the current communication format over serial. See doc/protocols/protocol_over_uart.txt
Also feel free to fork the project, make changes, and possibly open a pull request.

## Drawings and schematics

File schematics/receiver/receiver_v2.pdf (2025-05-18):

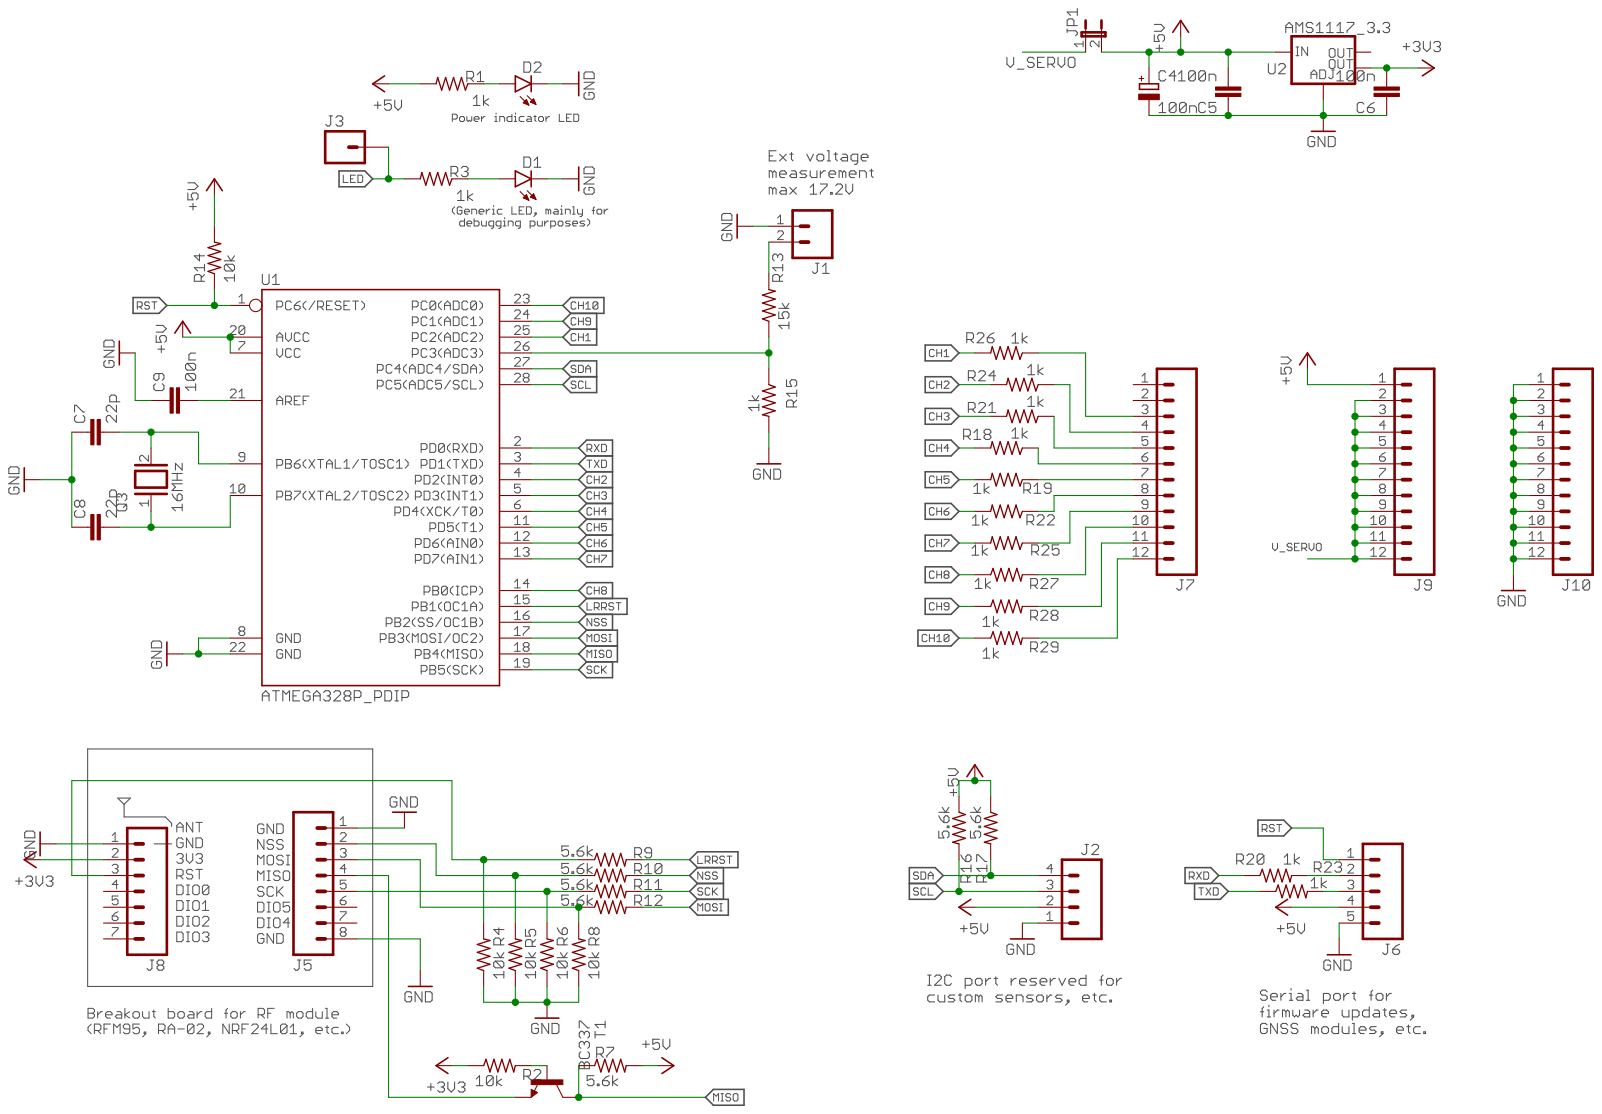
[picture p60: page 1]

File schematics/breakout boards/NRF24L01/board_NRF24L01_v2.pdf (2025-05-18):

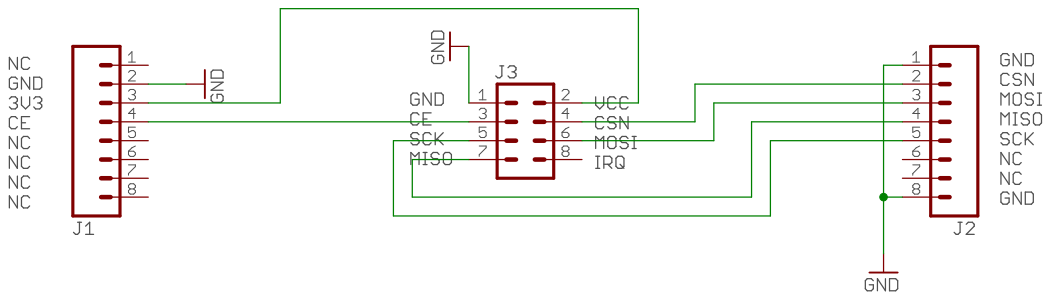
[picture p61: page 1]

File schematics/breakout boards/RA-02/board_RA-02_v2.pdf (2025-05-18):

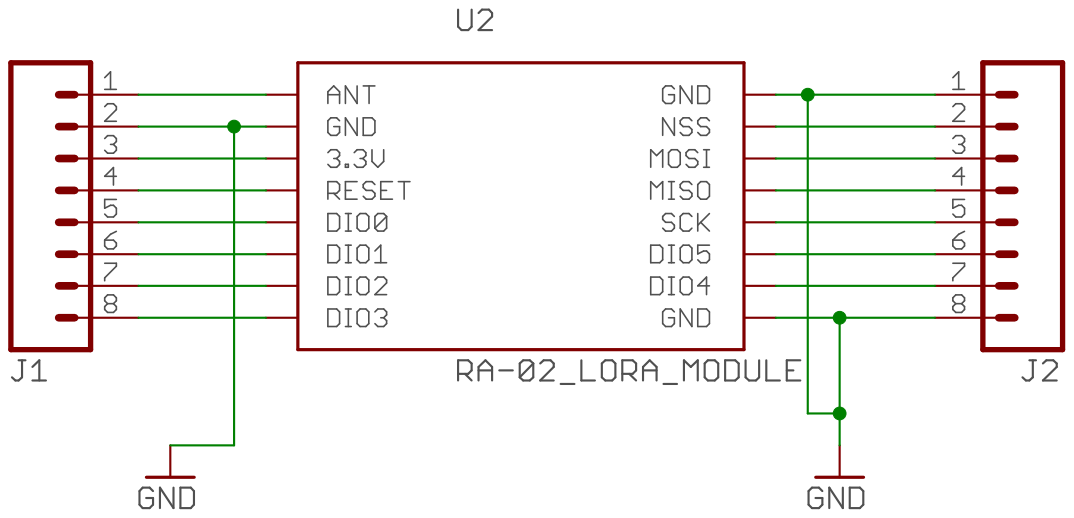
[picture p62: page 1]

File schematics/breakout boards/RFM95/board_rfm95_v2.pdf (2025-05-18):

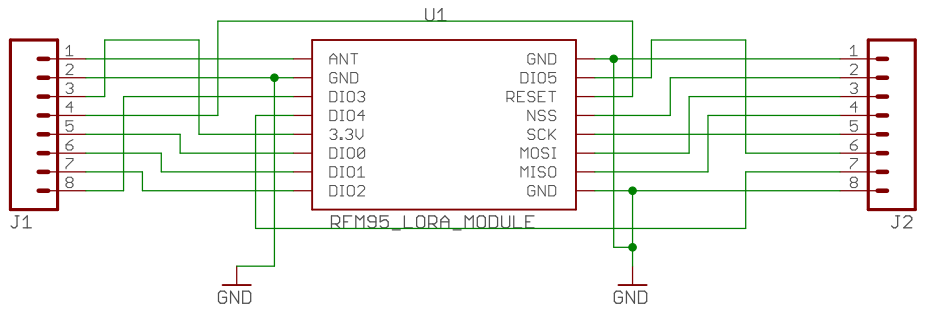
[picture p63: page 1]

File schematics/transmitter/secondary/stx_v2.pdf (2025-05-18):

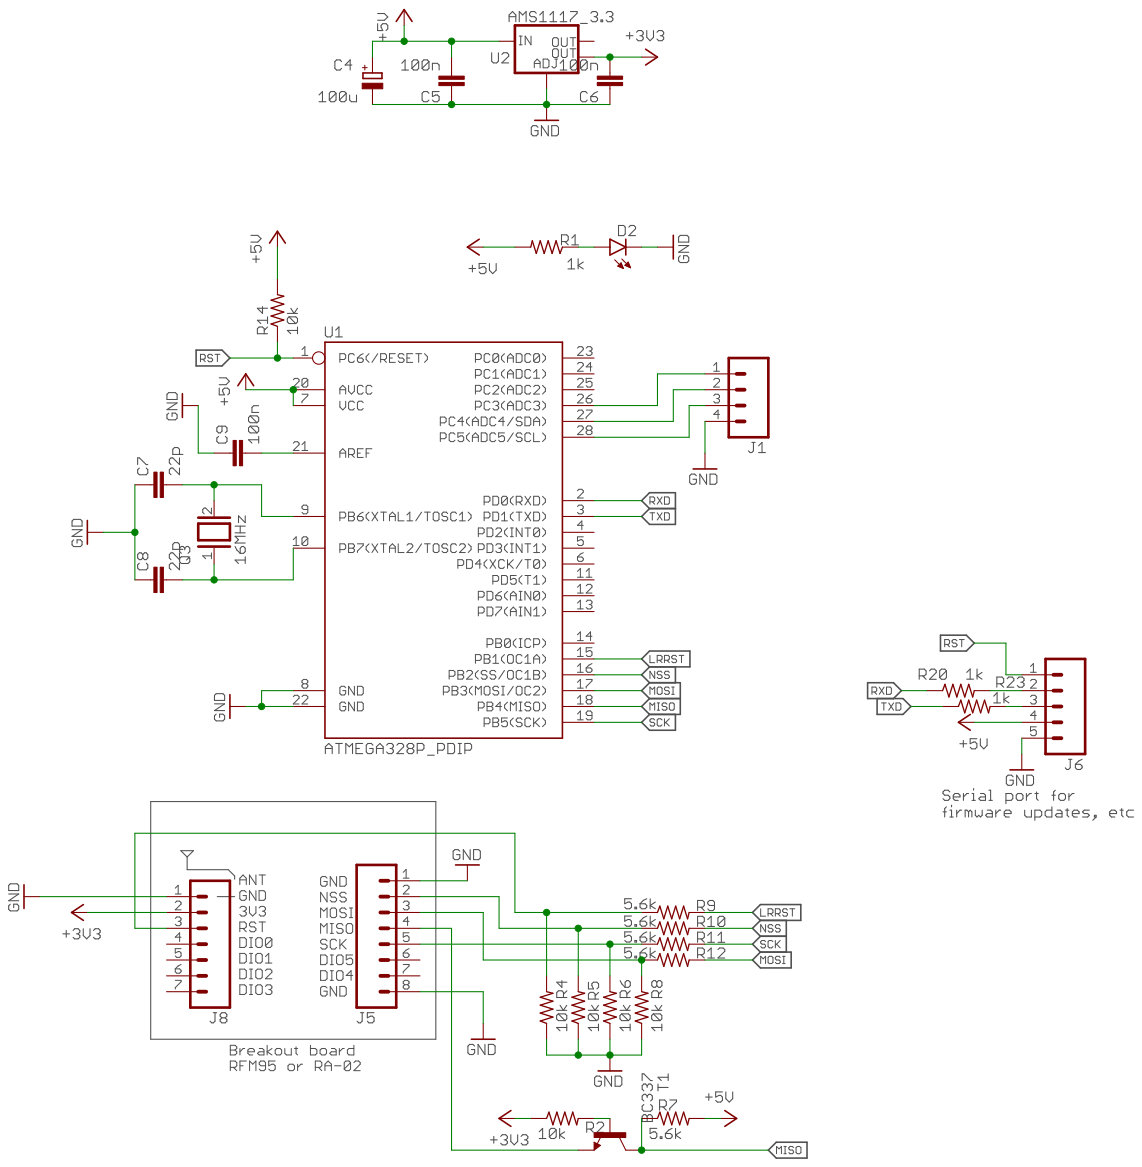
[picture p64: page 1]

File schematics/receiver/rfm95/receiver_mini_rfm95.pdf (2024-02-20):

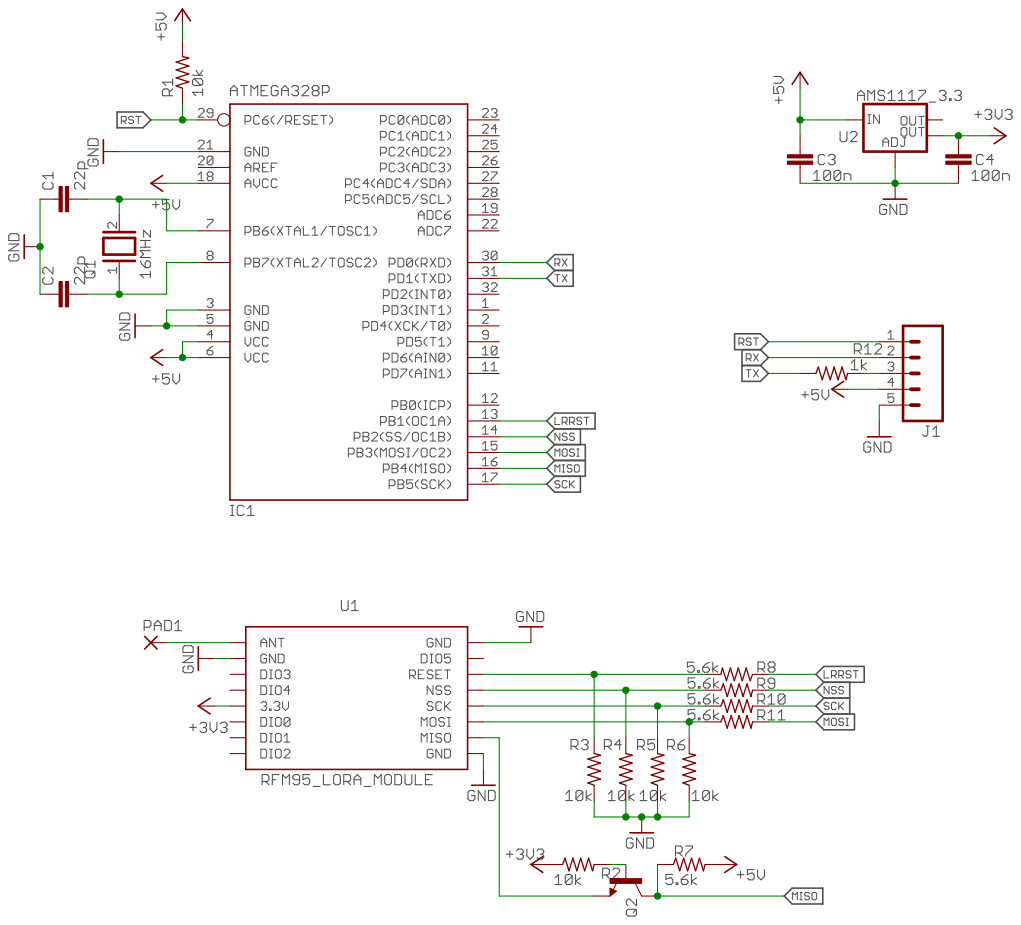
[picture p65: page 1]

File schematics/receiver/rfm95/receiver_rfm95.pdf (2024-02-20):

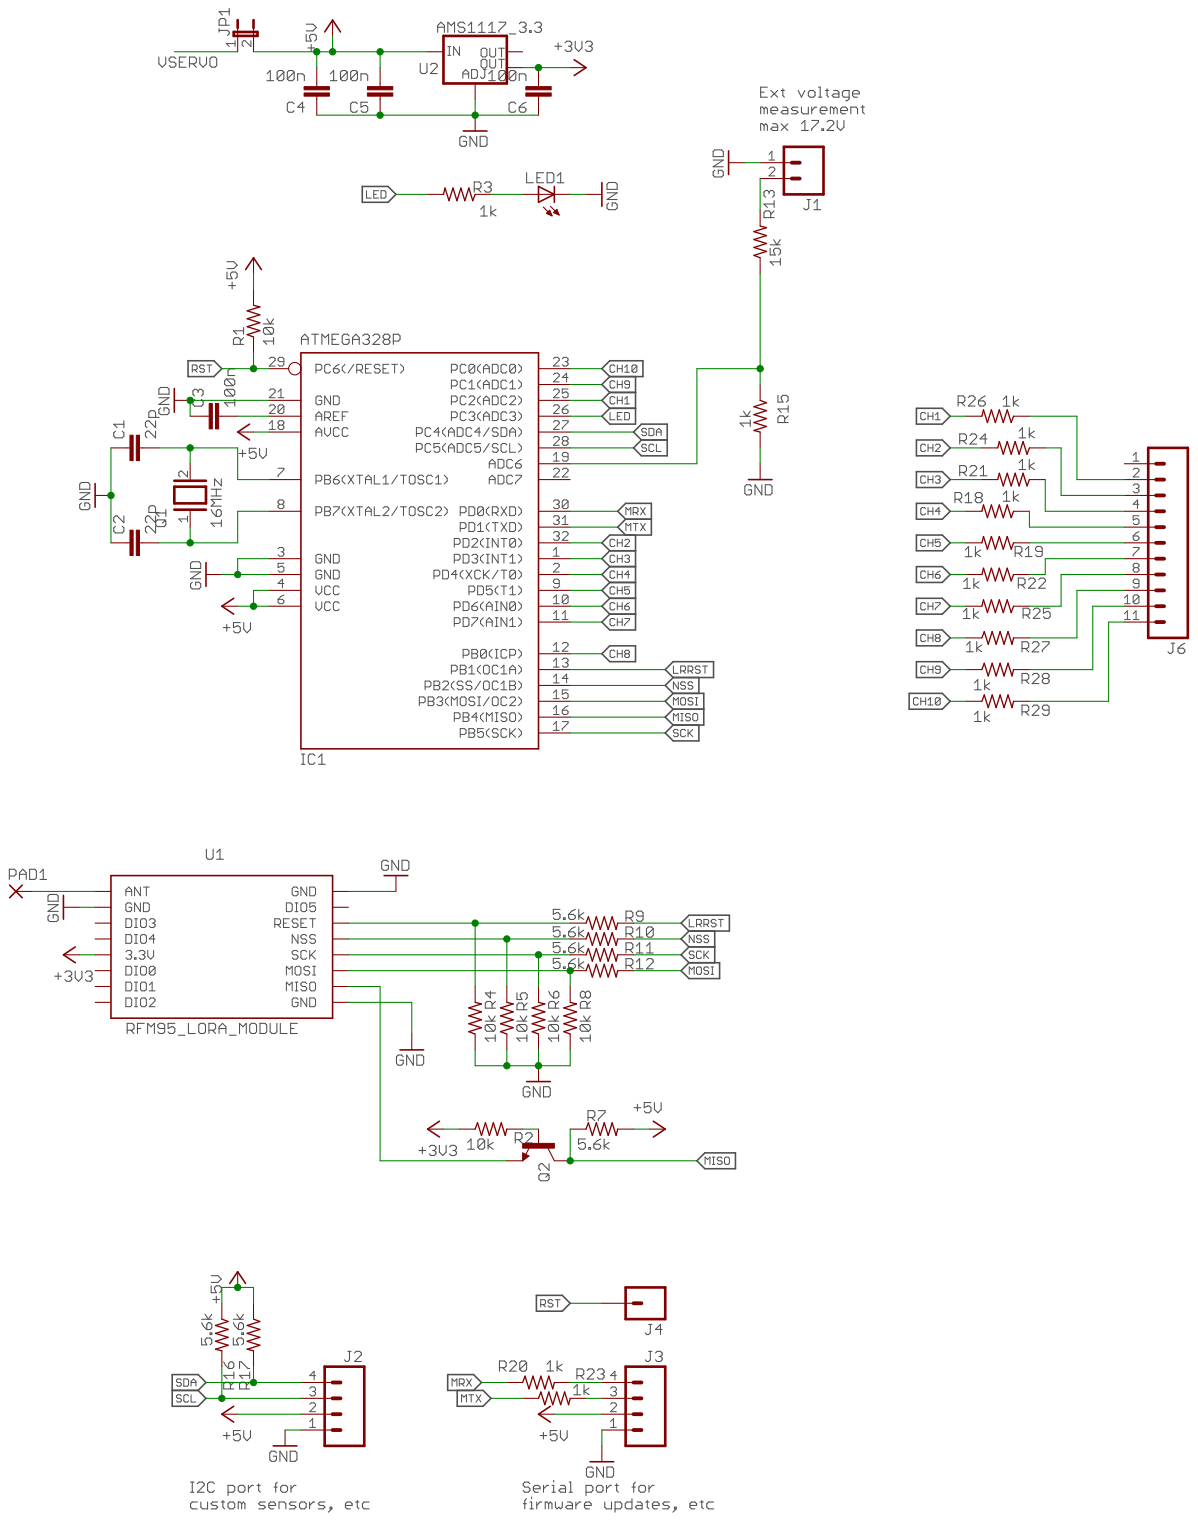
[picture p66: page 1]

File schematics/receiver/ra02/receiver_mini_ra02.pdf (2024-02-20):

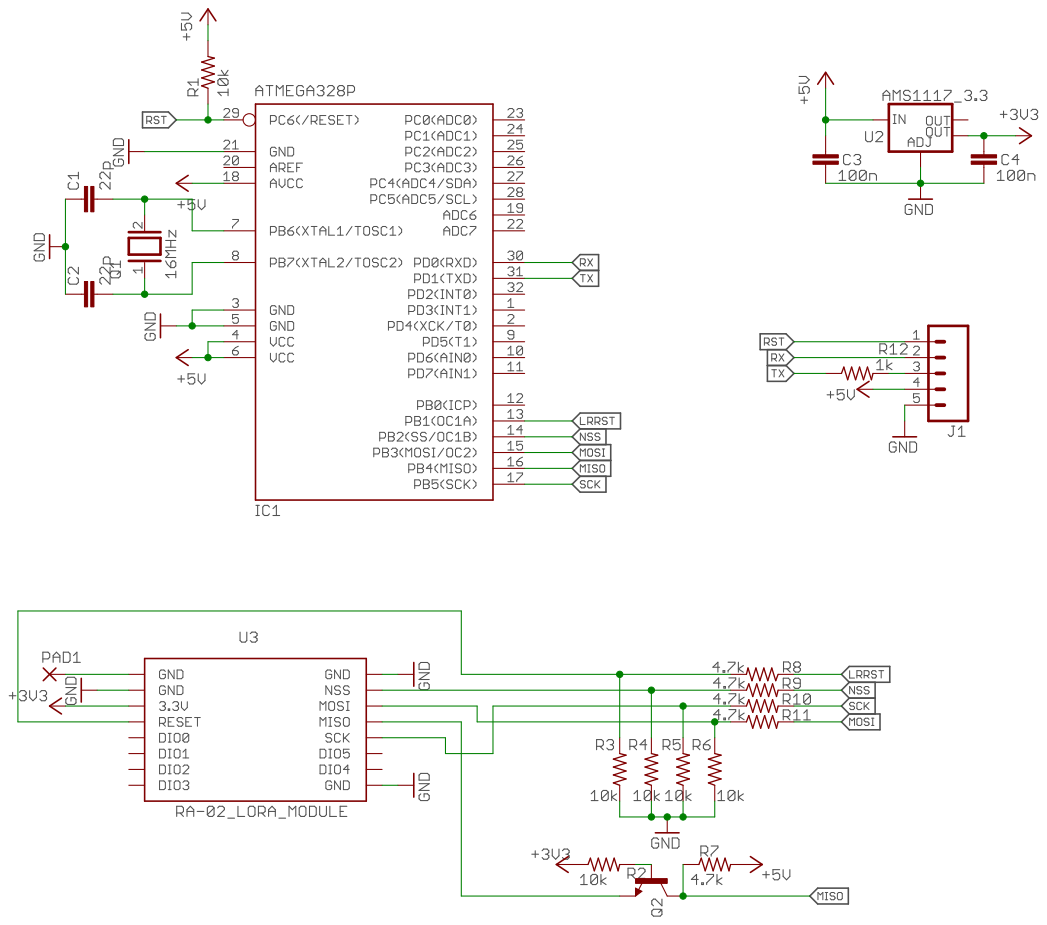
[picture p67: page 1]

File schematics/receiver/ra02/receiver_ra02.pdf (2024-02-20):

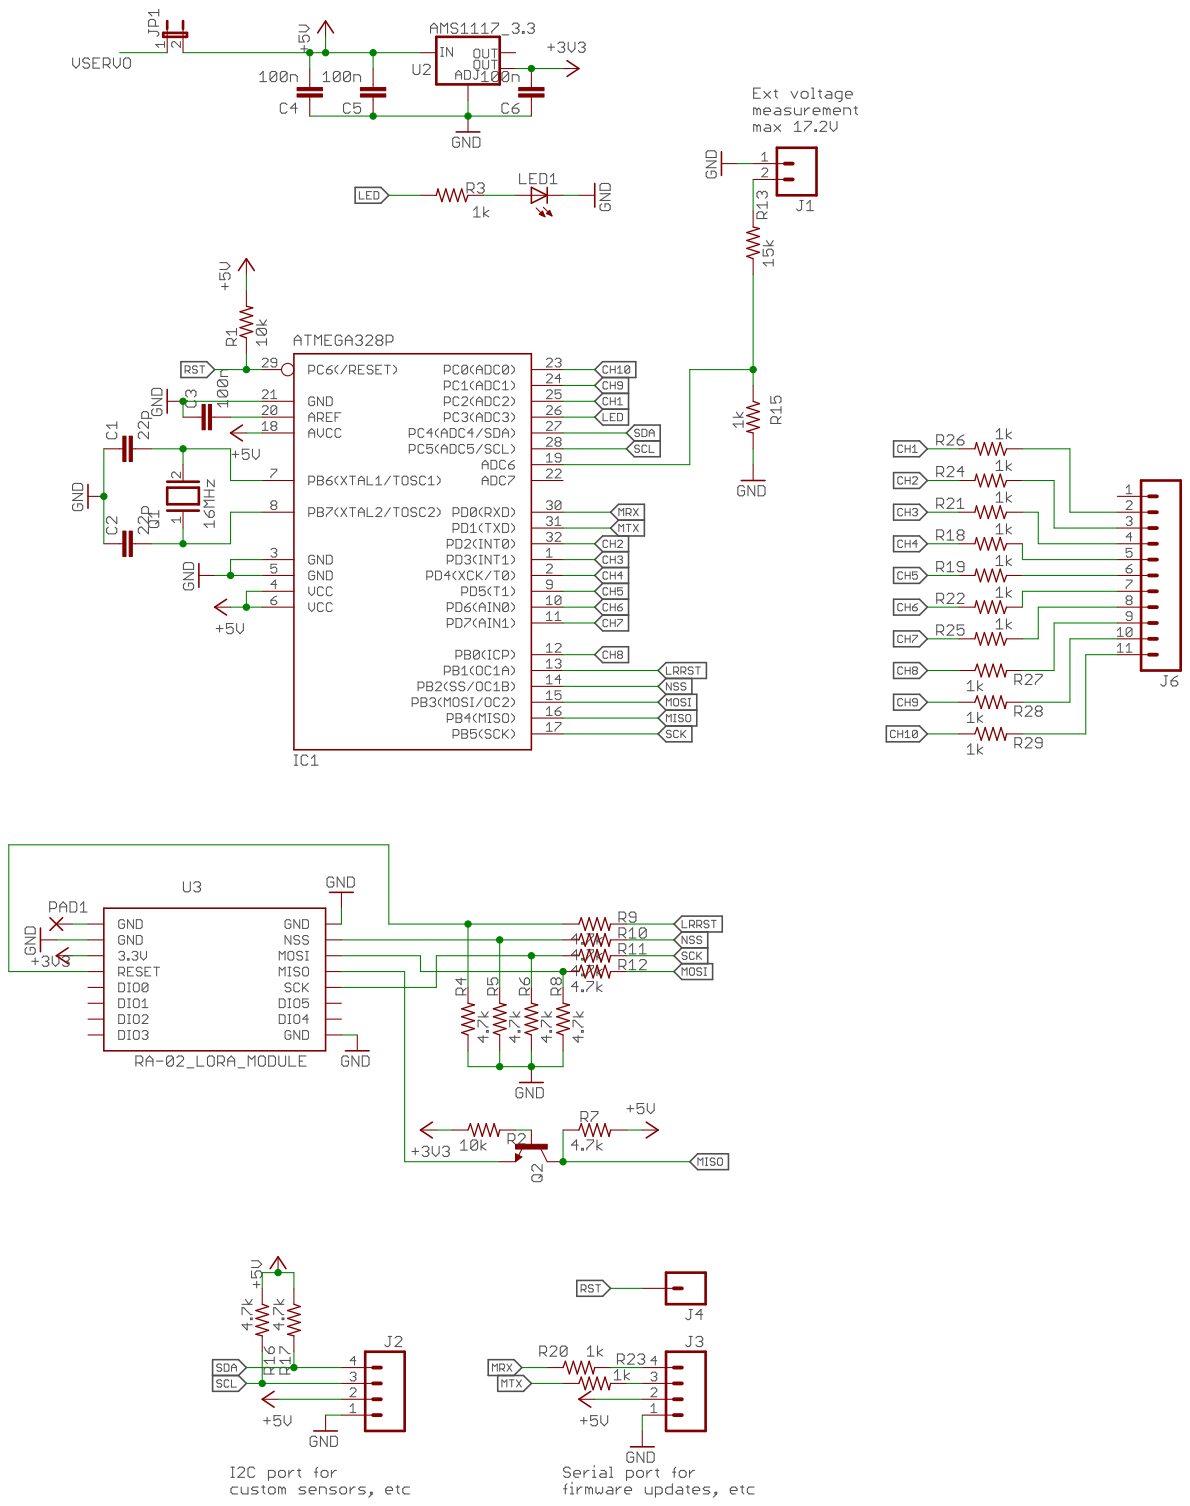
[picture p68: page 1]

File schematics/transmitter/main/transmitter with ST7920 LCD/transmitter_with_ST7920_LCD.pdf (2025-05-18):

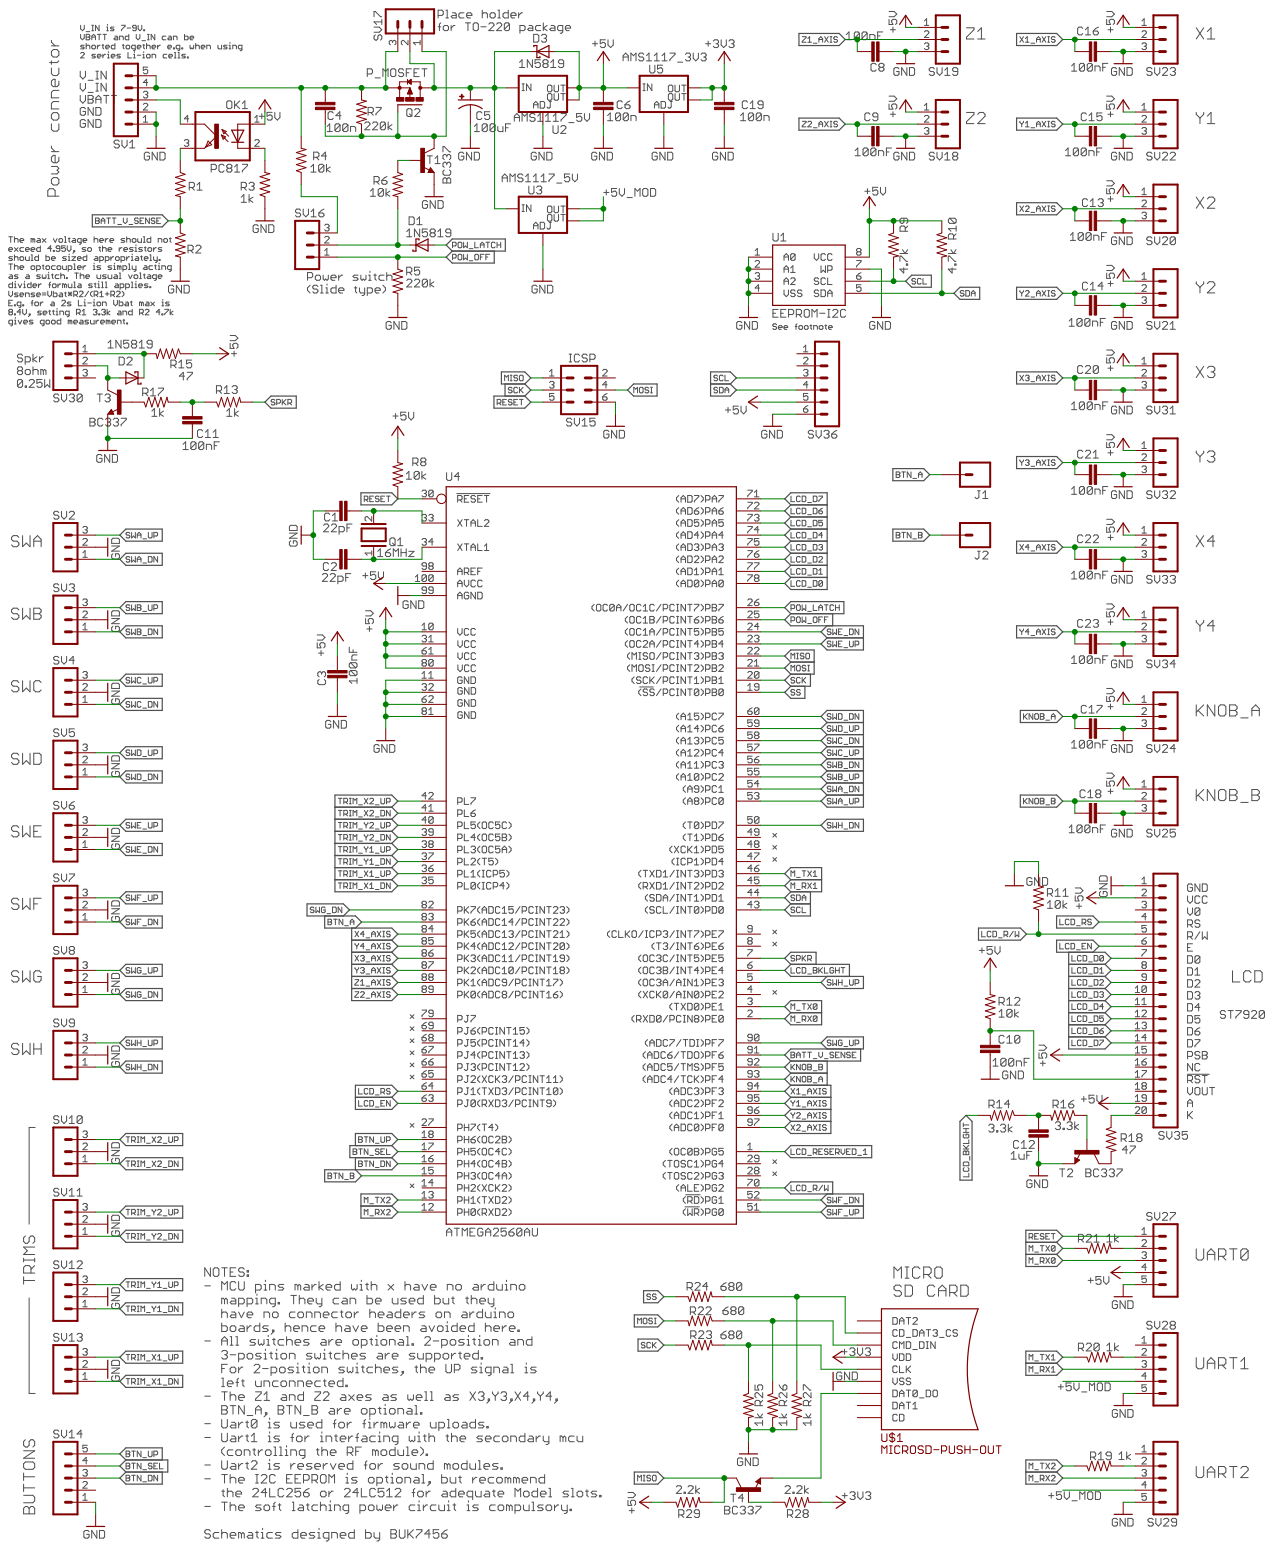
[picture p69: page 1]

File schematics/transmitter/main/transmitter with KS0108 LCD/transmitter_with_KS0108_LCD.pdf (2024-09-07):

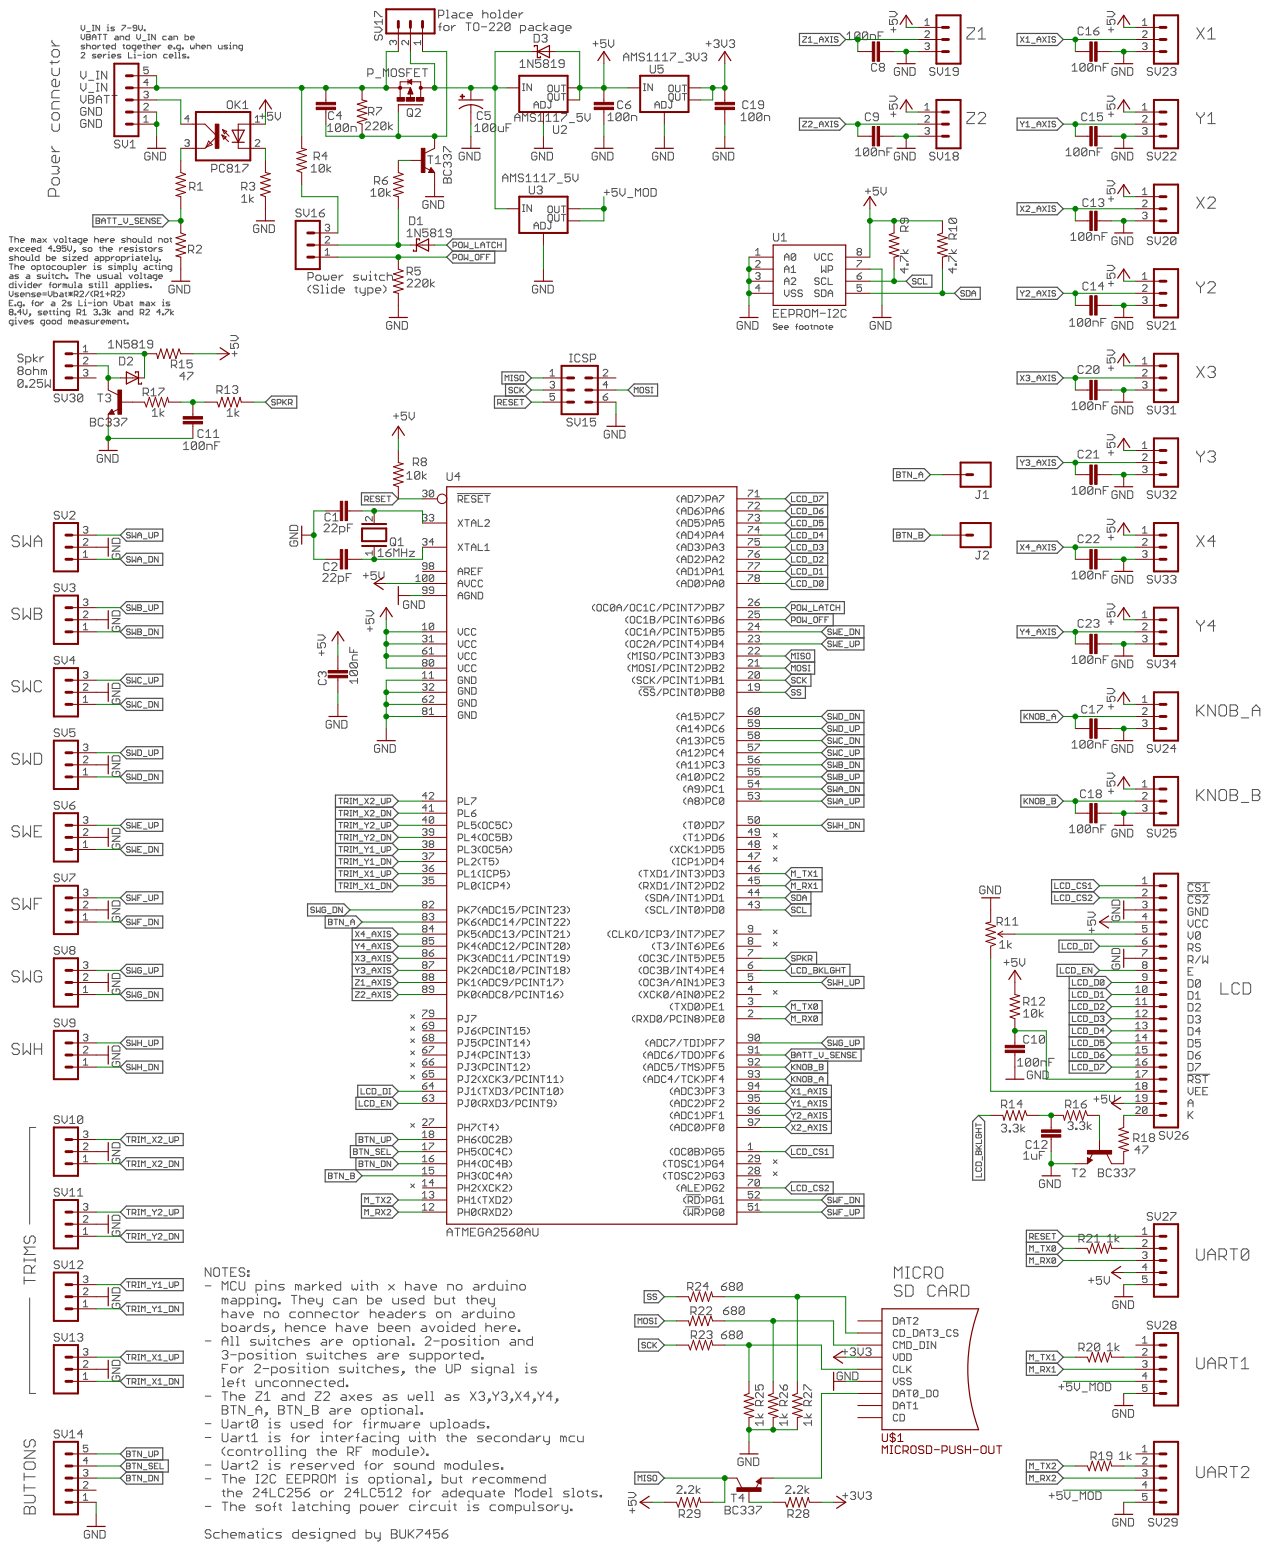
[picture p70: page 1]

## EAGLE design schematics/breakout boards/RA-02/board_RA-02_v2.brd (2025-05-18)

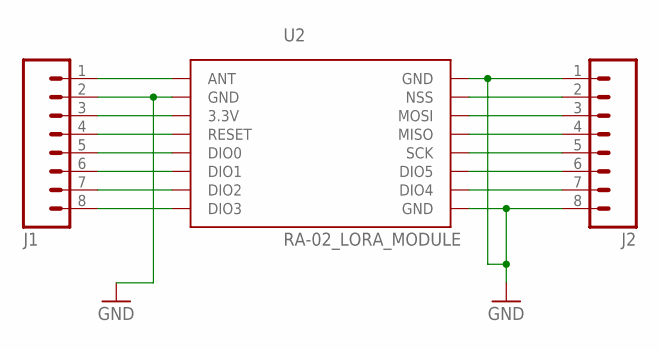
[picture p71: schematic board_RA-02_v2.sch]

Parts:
J1, J2: M08; 1X08_ROUND
U2: RA-02_LORA_MODULE; RA-02

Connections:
ANT: J1.1, U2.ANT
GND: J1.2, J2.1, J2.8, U2.GND@2 (GND), U2.GND@3 (GND), U2.GND@4 (GND)
unnamed: J1.3, U2.3.3V
unnamed: J1.4, U2.RESET
unnamed: J1.5, U2.DIO0
unnamed: J1.6, U2.DIO1
unnamed: J1.7, U2.DIO2
unnamed: J1.8, U2.DIO3
unnamed: J2.2, U2.NSS
unnamed: J2.3, U2.MOSI
unnamed: J2.4, U2.MISO
unnamed: J2.5, U2.SCK
unnamed: J2.6, U2.DIO5
unnamed: J2.7, U2.DIO4

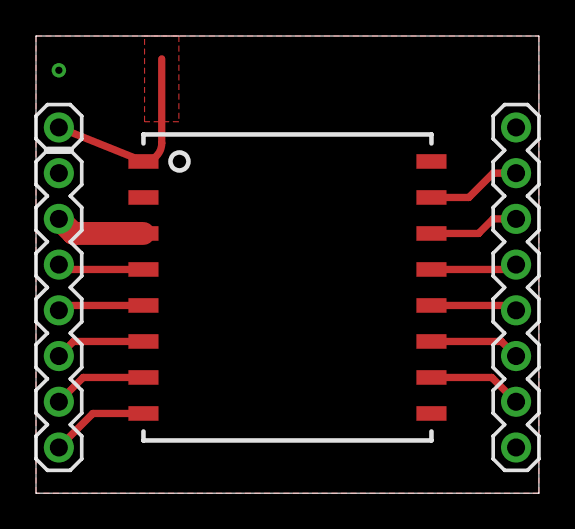
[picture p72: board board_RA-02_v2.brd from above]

Board: 2 copper layers, 27.9 x 25.4 mm, 3 parts (0 on the bottom side), 14 nets.

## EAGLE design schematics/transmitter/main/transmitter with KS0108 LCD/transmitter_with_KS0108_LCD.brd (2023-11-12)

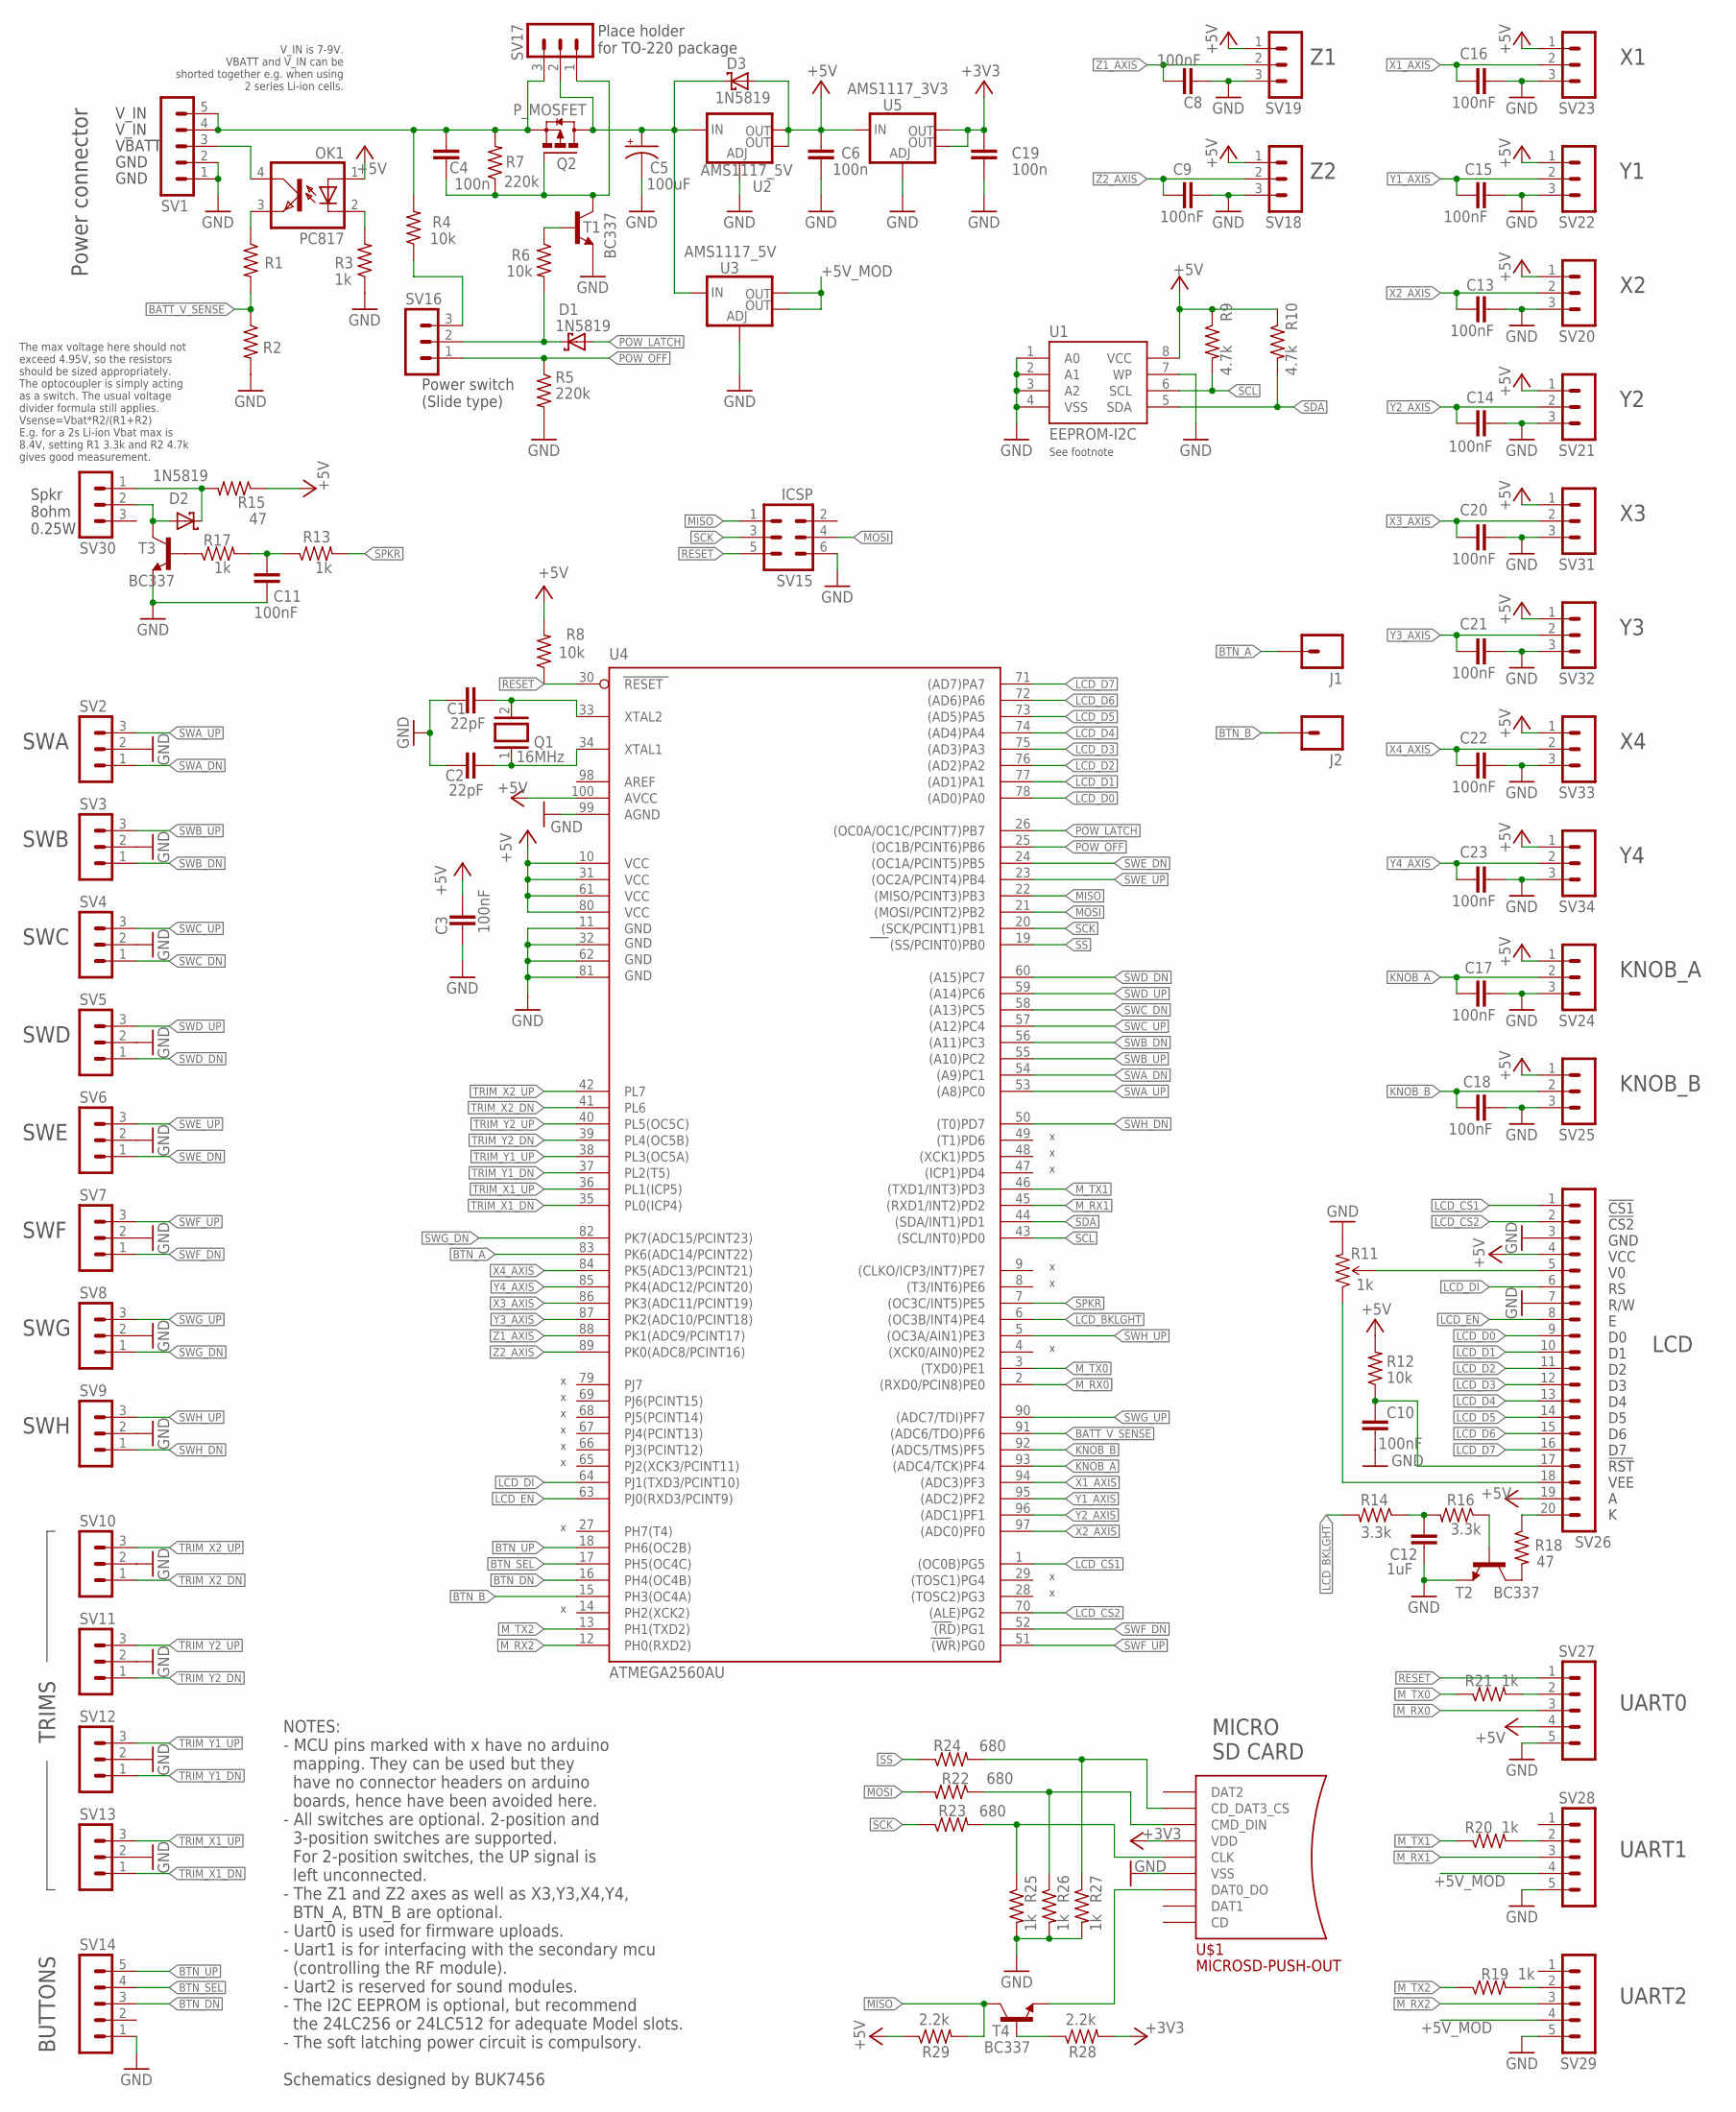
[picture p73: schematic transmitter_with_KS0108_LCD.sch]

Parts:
C1, C2: 22pF; C050-024X044
C3, C8, C9, C10, C11, C13, C14, C15, C16, C17, C18, C20, C21, C22, C23: 100nF; C050-024X044
C4, C6, C19: 100n; C050-024X044
C5: 100uF; E2,5-6E
C12: 1uF; C050-024X044
D1, D2, D3: 1N5819; DO41-7.6
J1, J2: M01PTH_LONGPAD; 1X01_LONGPAD
OK1: PC817; DIL04
Q1: 16MHz; QS
Q2: P_MOSFET; SUPER-SOT3
R1, R2, R3, R13, R17, R19, R20, R21, R25, R26, R27: 1k; 0204/5
R4, R6, R8, R12: 10k; 0204/5
R5, R7: 220k; 0204/5
R9, R10: 4.7k; 0204/5
R11: 1k; TRIM_POT_PTH
R14, R16: 3.3k; 0204/5
R15, R18: 47; 0204/5
R22, R23, R24: 680; 0204/5
R28, R29: 2.2k; 0204/5
SV1, SV14, SV27, SV28, SV29: MA05-1
SV2, SV3, SV4, SV5, SV6, SV7, SV8, SV9, SV10, SV11, SV12, SV13, SV16, SV17, SV18, SV19, SV20, SV21, SV22, SV23, SV24, SV25, SV30, SV31, SV32, SV33, SV34: MA03-1
SV15: ICSP; MA03-2
SV26: MA20-1
T1, T2, T3, T4: BC337; TO92
U1: EEPROM-I2C; SO08-EIAJ
U2, U3: AMS1117_5V; SOT223
U4: ATMEGA2560AU; TQFP100
U5: AMS1117_3V3; SOT223
U$1: MICROSD-PUSH-OUT

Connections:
+3V3: C19.2, R28.2, U5.2 (OUT), U5.4 (OUT), U$1.4 (VDD)
+5V: C3.1, C6.2, D3.A, OK1.1 (A), R8.2, R9.1, R10.1, R12.2, R15.1, R29.1, SV18.1, SV19.1, SV20.1, SV21.1, SV22.1, SV23.1, SV24.1, SV25.1, SV26.4, SV26.19, SV27.4, SV31.1, SV32.1, SV33.1, SV34.1, U1.8 (VCC), U2.2 (OUT), U2.4 (OUT), U4.10 (VCC), U4.31 (VCC1), U4.61 (VCC2), U4.80 (VCC3), U4.100 (AVCC), U5.3 (IN)
+5V_MOD: SV28.4, SV29.4, U3.2 (OUT), U3.4 (OUT)
BATT_V_SENSE: R1.2, R2.1, U4.91 ((ADC6/TDO)PF6)
BTN_A: J1.1, U4.83 (PK6(ADC14/PCINT22))
BTN_B: J2.1, U4.15 (PH3(OC4A))
BTN_DN: SV14.3, U4.16 (PH4(OC4B))
BTN_SEL: SV14.4, U4.17 (PH5(OC4C))
BTN_UP: SV14.5, U4.18 (PH6(OC2B))
GND: C1.1, C2.1, C3.2, C5.-, C6.1, C8.2, C9.1, C10.2, C11.2, C12.2, C13.1, C14.1, C15.1, C16.1, C17.1, C18.1, C19.1, C20.1, C21.1, C22.1, C23.1, R2.2, R3.1, R5.2, R11.3 (CW), R25.2, R26.2, R27.2, SV1.1, SV1.2, SV2.2, SV3.2, SV4.2, SV5.2, SV6.2, SV7.2, SV8.2, SV9.2, SV10.2, SV11.2, SV12.2, SV13.2, SV14.1, SV15.6, SV18.3, SV19.3, SV20.3, SV21.3, SV22.3, SV23.3, SV24.3, SV25.3, SV26.3, SV26.7, SV27.5, SV28.5, SV29.5, SV31.3, SV32.3, SV33.3, SV34.3, T1.1 (E), T2.1 (E), T3.1 (E), U1.1 (A0), U1.2 (A1), U1.3 (A2), U1.4 (VSS), U1.7 (WP), U2.1 (ADJ), U3.1 (ADJ), U4.11 (GND), U4.32 (GND1), U4.62 (GND2), U4.81 (GND3), U4.99 (AGND), U5.1 (ADJ), U$1.6 (VSS), U$1.G1 (VSS), U$1.G2 (VSS), U$1.G3 (VSS), U$1.G4 (VSS)
KNOB_A: C17.2, SV24.2, U4.93 ((ADC4/TCK)PF4)
KNOB_B: C18.2, SV25.2, U4.92 ((ADC5/TMS)PF5)
LCD_BKLGHT: R14.2, U4.6 ((OC3B/INT4)PE4)
LCD_CS1: SV26.1, U4.1 ((OC0B)PG5)
LCD_CS2: SV26.2, U4.70 ((ALE)PG2)
LCD_D0: SV26.9, U4.78 ((AD0)PA0)
LCD_D1: SV26.10, U4.77 ((AD1)PA1)
LCD_D2: SV26.11, U4.76 ((AD2)PA2)
LCD_D3: SV26.12, U4.75 ((AD3)PA3)
LCD_D4: SV26.13, U4.74 ((AD4)PA4)
LCD_D5: SV26.14, U4.73 ((AD5)PA5)
LCD_D6: SV26.15, U4.72 ((AD6)PA6)
LCD_D7: SV26.16, U4.71 ((AD7)PA7)
LCD_DI: SV26.6, U4.64 (PJ1(TXD3/PCINT10))
LCD_EN: SV26.8, U4.63 (PJ0(RXD3/PCINT9))
MISO: R29.2, SV15.1, T4.3 (C), U4.22 ((MISO/PCINT3)PB3)
MOSI: R22.2, SV15.4, U4.21 ((MOSI/PCINT2)PB2)
M_RX0: SV27.3, U4.2 ((RXD0/PCIN8)PE0)
M_RX1: SV28.3, U4.45 ((RXD1/INT2)PD2)
M_RX2: SV29.3, U4.12 (PH0(RXD2))
M_TX0: R21.1, U4.3 ((TXD0)PE1)
M_TX1: R20.1, U4.46 ((TXD1/INT3)PD3)
M_TX2: R19.1, U4.13 (PH1(TXD2))
unnamed: C12.1, R14.1, R16.2
unnamed: C10.1, R12.1, SV26.17
unnamed: R18.2, T2.3 (C)
unnamed: R16.1, T2.2 (B)
unnamed: C11.1, R13.1, R17.2
unnamed: R21.2, SV27.2
unnamed: R20.2, SV28.2
unnamed: R19.2, SV29.2
unnamed: C1.2, Q1.2, U4.33 (XTAL2)
unnamed: C2.2, Q1.1, U4.34 (XTAL1)
unnamed: T4.1 (E), U$1.7 (DAT0_DO)
unnamed: OK1.4 (COL), SV1.3
unnamed: R11.1 (CCW), SV26.18
unnamed: R11.2 (WIPER), SV26.5
unnamed: R18.1, SV26.20
unnamed: R24.2, R27.1, U$1.2 (CD_DAT3_CS)
unnamed: R22.1, R26.1, U$1.3 (CMD_DIN)
unnamed: R23.2, R25.1, U$1.5 (CLK)
unnamed: R28.1, T4.2 (B)
unnamed: R17.1, T3.2 (B)
unnamed: D2.A, SV30.2, T3.3 (C)
unnamed: D2.C, R15.2, SV30.1
unnamed: R6.1, T1.2 (B)
unnamed: D1.C, R6.2, SV16.2
unnamed: OK1.3 (EMIT), R1.1
unnamed: C4.2, Q2.2 (S), R4.2, R7.2, SV1.4, SV1.5, SV17.3
unnamed: C4.1, Q2.1 (G), R7.1, SV17.1, T1.3 (C)
unnamed: OK1.2 (C), R3.2
unnamed: R4.1, SV16.3
unnamed: C5.+, D3.C, Q2.3 (D), SV17.2, U2.3 (IN), U3.3 (IN)
POW_LATCH: D1.A, U4.26 ((OC0A/OC1C/PCINT7)PB7)
POW_OFF: R5.1, SV16.1, U4.25 ((OC1B/PCINT6)PB6)
RESET: R8.1, SV15.5, SV27.1, U4.30 (RESET)
SCK: R23.1, SV15.3, U4.20 ((SCK/PCINT1)PB1)
SCL: R9.2, U1.6 (SCL), U4.43 ((SCL/INT0)PD0)
SDA: R10.2, U1.5 (SDA), U4.44 ((SDA/INT1)PD1)
SPKR: R13.2, U4.7 ((OC3C/INT5)PE5)
SS: R24.1, U4.19 ((SS/PCINT0)PB0)
SWA_DN: SV2.1, U4.54 ((A9)PC1)
SWA_UP: SV2.3, U4.53 ((A8)PC0)
SWB_DN: SV3.1, U4.56 ((A11)PC3)
SWB_UP: SV3.3, U4.55 ((A10)PC2)
SWC_DN: SV4.1, U4.58 ((A13)PC5)
SWC_UP: SV4.3, U4.57 ((A12)PC4)
SWD_DN: SV5.1, U4.60 ((A15)PC7)
SWD_UP: SV5.3, U4.59 ((A14)PC6)
SWE_DN: SV6.1, U4.24 ((OC1A/PCINT5)PB5)
SWE_UP: SV6.3, U4.23 ((OC2A/PCINT4)PB4)
SWF_DN: SV7.1, U4.52 ((RD)PG1)
SWF_UP: SV7.3, U4.51 ((WR)PG0)
SWG_DN: SV8.1, U4.82 (PK7(ADC15/PCINT23))
SWG_UP: SV8.3, U4.90 ((ADC7/TDI)PF7)
SWH_DN: SV9.1, U4.50 ((T0)PD7)
SWH_UP: SV9.3, U4.5 ((OC3A/AIN1)PE3)
TRIM_X1_DN: SV13.1, U4.35 (PL0(ICP4))
TRIM_X1_UP: SV13.3, U4.36 (PL1(ICP5))
TRIM_X2_DN: SV10.1, U4.41 (PL6)
TRIM_X2_UP: SV10.3, U4.42 (PL7)
TRIM_Y1_DN: SV12.1, U4.37 (PL2(T5))
TRIM_Y1_UP: SV12.3, U4.38 (PL3(OC5A))
TRIM_Y2_DN: SV11.1, U4.39 (PL4(OC5B))
TRIM_Y2_UP: SV11.3, U4.40 (PL5(OC5C))
X1_AXIS: C16.2, SV23.2, U4.94 ((ADC3)PF3)
X2_AXIS: C13.2, SV20.2, U4.97 ((ADC0)PF0)
X3_AXIS: C20.2, SV31.2, U4.86 (PK3(ADC11/PCINT19))
X4_AXIS: C22.2, SV33.2, U4.84 (PK5(ADC13/PCINT21))
Y1_AXIS: C15.2, SV22.2, U4.95 ((ADC2)PF2)
Y2_AXIS: C14.2, SV21.2, U4.96 ((ADC1)PF1)
Y3_AXIS: C21.2, SV32.2, U4.87 (PK2(ADC10/PCINT18))
Y4_AXIS: C23.2, SV34.2, U4.85 (PK4(ADC12/PCINT20))
Z1_AXIS: C8.1, SV19.2, U4.88 (PK1(ADC9/PCINT17))
Z2_AXIS: C9.2, SV18.2, U4.89 (PK0(ADC8/PCINT16))

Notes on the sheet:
Spkr 8ohm 0.25W
!CS1 !CS2 GND VCC V0 RS R/W E D0 D1 D2 D3 D4 D5 D6 D7 !RST VEE A K
GND
VBATT
Power connector
The max voltage here should not exceed 4.95V, so the resistors should be sized appropriately. The optocoupler is simply acting as a switch. The usual voltage divider formula still applies. Vsense=Vbat*R2/(R1+R2) E.g. for a 2s Li-ion Vbat max is 8.4V, setting R1 3.3k and R2 4.7k gives good measureme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
Power switch (Slide type)
V_IN
V_IN is 7-9V. VBATT and V_IN can be shorted together e.g. when using 2 series Li-ion cells.
SWA
SWB
SWC
SWD
SWE
SWF
SWG
SWH
LCD
UART0
UART1
BUTTONS
TRIMS
KNOB_A
KNOB_B
NOTES: - MCU pins marked with x have no arduino mapping. They can be used but they have no connector headers on arduino boards, hence have been avoided here. - All switches are optional. 2-position and 3-position switches are supported. For 2-position switches, the UP signal is left unconnected. - 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
Place holder for TO-220 package
UART2
MICRO SD CARD
See footnote

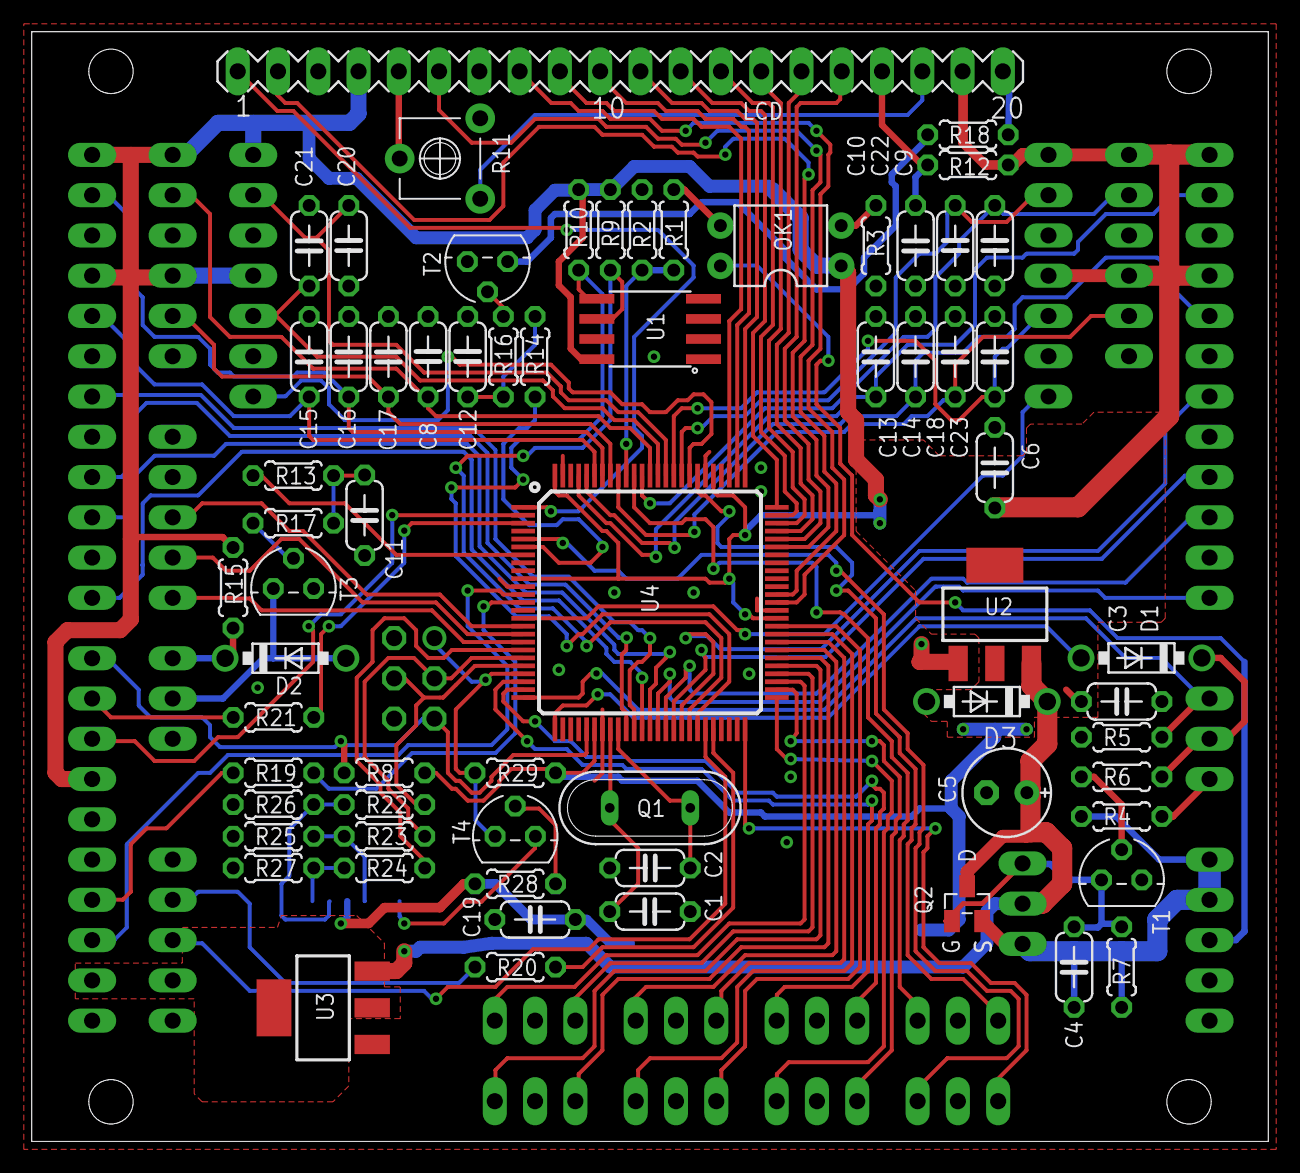
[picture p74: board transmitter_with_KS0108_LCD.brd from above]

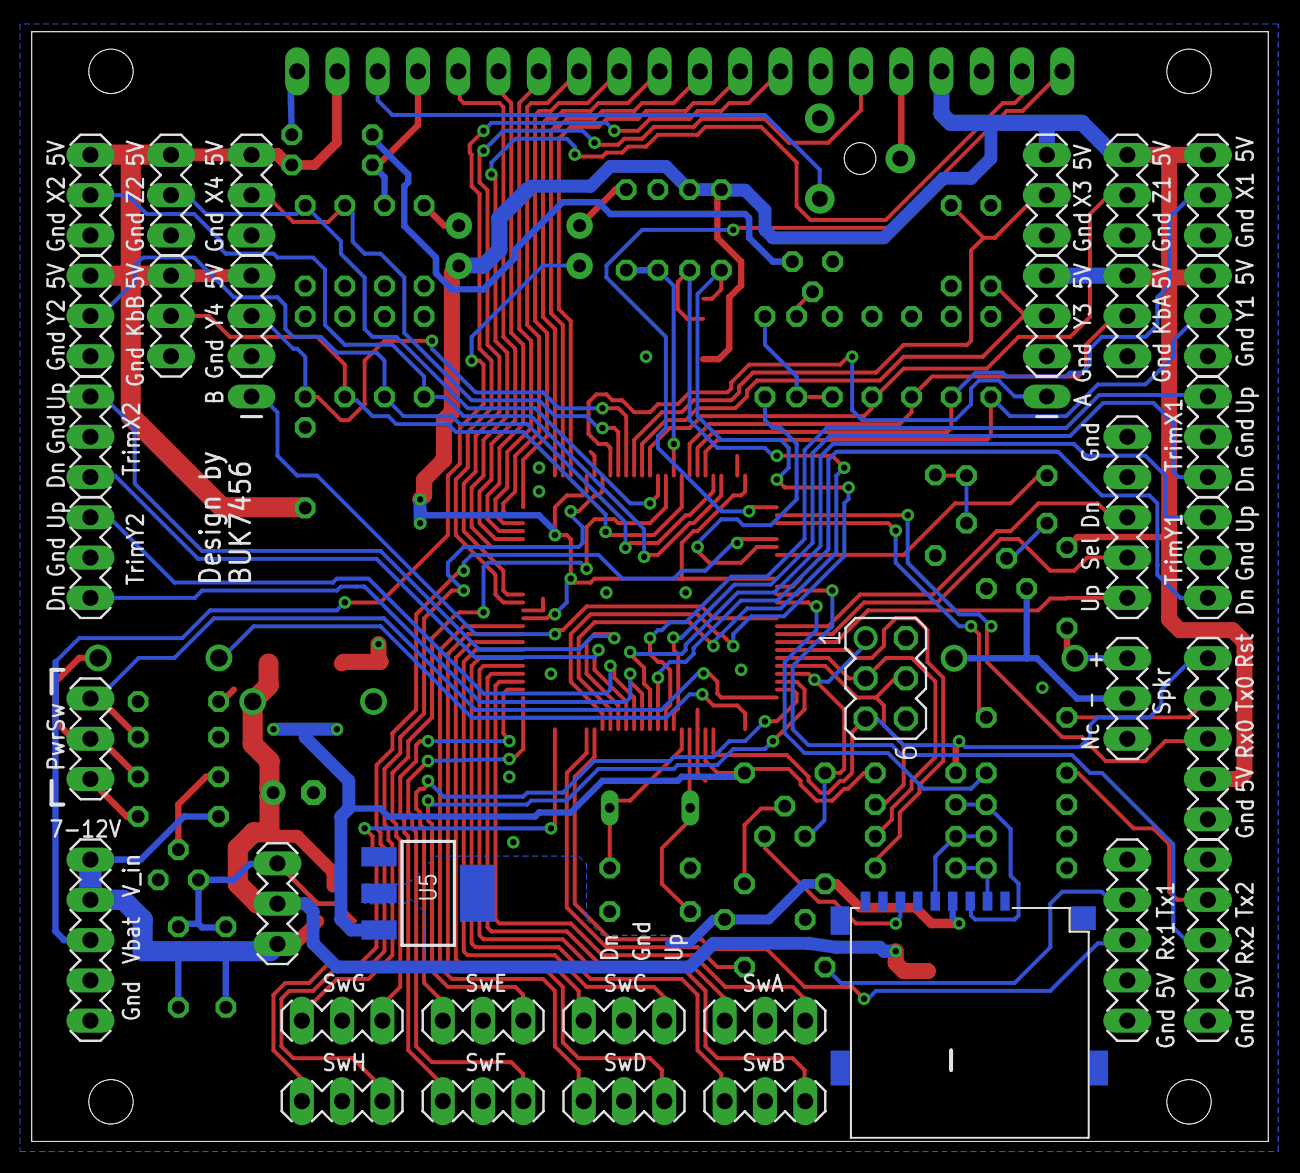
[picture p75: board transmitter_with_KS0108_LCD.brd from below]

Board: 2 copper layers, 78.0 x 70.0 mm, 103 parts (37 on the bottom side), 105 nets.

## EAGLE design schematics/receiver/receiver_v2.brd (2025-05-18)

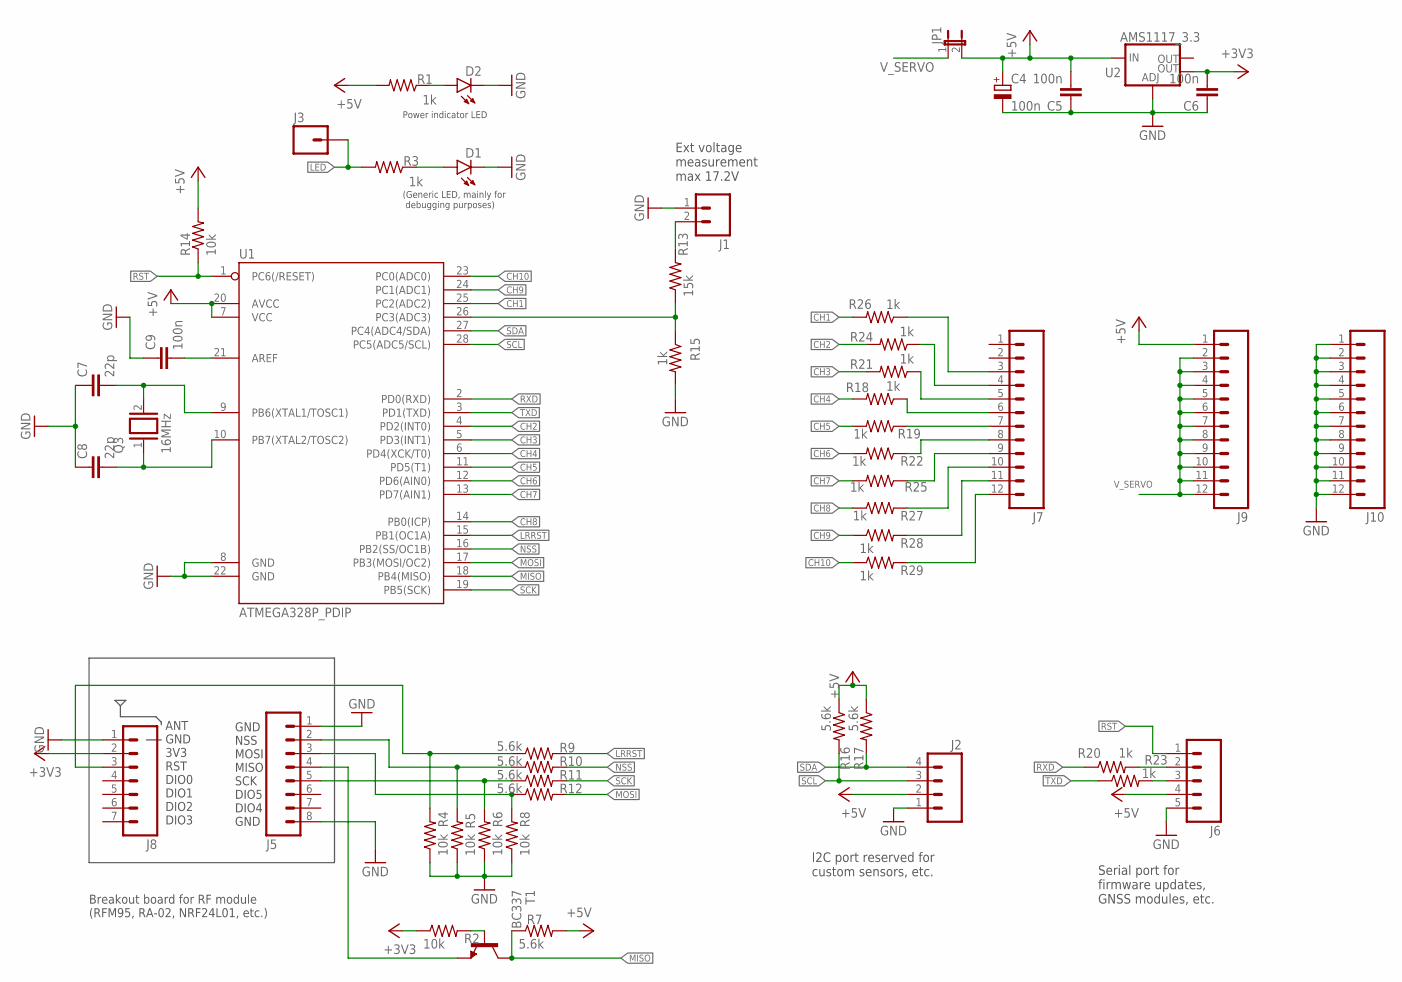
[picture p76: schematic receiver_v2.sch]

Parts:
C4: 100n; E2,5-6E
C5, C6, C9: 100n; C050-024X044
C7, C8: 22p; C050-024X044
D1, D2: LED3MM
J1: M02PTH; 1X02
J2: M04PTH; 1X04
J3: M01PTH; 1X01
J5: M08; 1X08_ROUND
J6: M05PTH; 1X05
J7, J9, J10: M12PTH; 1X12
J8: M07; 1X07
JP1: JP1E; JP1
Q3: 16MHz; QS
R1, R3, R15, R18, R19, R21, R22, R24, R25, R26, R27, R28, R29: 1k; 0204V
R2: 10k; 0207/15
R4, R5, R6, R8: 10k; 0204V
R7, R9, R10, R11, R12, R16, R17: 5.6k; 0204V
R13: 15k; 0204V
R14: 10k; 0204/7
R20, R23: 1k; 0204/7
T1: BC337; TO92
U1: ATMEGA328P_PDIP; DIL28-3
U2: AMS1117_3.3; SOT223

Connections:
+3V3: C6.2, J8.2, R2.1, U2.4 (OUT)
+5V: C4.+, C5.2, J2.2, J6.4, J9.1, JP1.2, R1.2, R7.2, R14.2, R16.1, R17.1, U1.7 (VCC), U1.20 (AVCC), U2.3 (IN)
CH1: R26.2, U1.25 (PC2(ADC2))
CH2: R24.2, U1.4 (PD2(INT0))
CH3: R21.2, U1.5 (PD3(INT1))
CH4: R18.2, U1.6 (PD4(XCK/T0))
CH5: R19.2, U1.11 (PD5(T1))
CH6: R22.2, U1.12 (PD6(AIN0))
CH7: R25.2, U1.13 (PD7(AIN1))
CH8: R27.1, U1.14 (PB0(ICP))
CH9: R28.1, U1.24 (PC1(ADC1))
CH10: R29.1, U1.23 (PC0(ADC0))
GND: C4.-, C5.1, C6.1, C7.1, C8.1, C9.1, D1.K (C), D2.K (C), J1.1, J2.1, J5.1, J5.8, J6.5, J8.1, J10.1, J10.2, J10.3, J10.4, J10.5, J10.6, J10.7, J10.8, J10.9, J10.10, J10.11, J10.12, R4.1, R5.1, R6.1, R8.1, R15.2, U1.8 (GND), U1.22 (GND), U2.1 (ADJ)
LED: J3.1, R3.2
LRRST: R9.2, U1.15 (PB1(OC1A))
MISO: R7.1, T1.3 (C), U1.18 (PB4(MISO))
MOSI: R12.2, U1.17 (PB3(MOSI/OC2))
unnamed: D2.A, R1.1
unnamed: J7.11, R28.2
unnamed: J5.4, T1.1 (E)
unnamed: J7.10, R27.2
unnamed: J8.3, R4.2, R9.1
unnamed: J5.2, R5.2, R10.1
unnamed: J5.5, R6.2, R11.1
unnamed: J5.3, R8.2, R12.1
unnamed: C9.2, U1.21 (AREF)
unnamed: R13.1, R15.1, U1.26 (PC3(ADC3))
unnamed: J6.3, R23.2
unnamed: D1.A, R3.1
unnamed: C7.2, Q3.2, U1.9 (PB6(XTAL1/TOSC1))
unnamed: J7.3, R26.1
unnamed: C8.2, Q3.1, U1.10 (PB7(XTAL2/TOSC2))
unnamed: J6.2, R20.2
unnamed: J7.4, R24.1
unnamed: J7.5, R21.1
unnamed: J7.6, R18.1
unnamed: J7.7, R19.1
unnamed: J7.8, R22.1
unnamed: J7.9, R25.1
unnamed: R2.2, T1.2 (B)
unnamed: J1.2, R13.2
unnamed: J7.12, R29.2
NSS: R10.2, U1.16 (PB2(SS/OC1B))
RST: J6.1, R14.1, U1.1 (PC6(/RESET))
RXD: R20.1, U1.2 (PD0(RXD))
SCK: R11.2, U1.19 (PB5(SCK))
SCL: J2.3, R16.2, U1.28 (PC5(ADC5/SCL))
SDA: J2.4, R17.2, U1.27 (PC4(ADC4/SDA))
TXD: R23.1, U1.3 (PD1(TXD))
V_SERVO: J9.2, J9.3, J9.4, J9.5, J9.6, J9.7, J9.8, J9.9, J9.10, J9.11, J9.12, JP1.1

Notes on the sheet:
I2C port reserved for custom sensors, etc.
Serial port for firmware updates, GNSS modules, etc.
Ext voltage measurement max 17.2V
GND NSS MOSI MISO SCK DIO5 DIO4 GND
ANT GND 3V3 RST DIO0 DIO1 DIO2 DIO3
Breakout board for RF module (RFM95, RA-02, NRF24L01, etc.)
(Generic LED, mainly for debugging purposes)
Power indicator LED

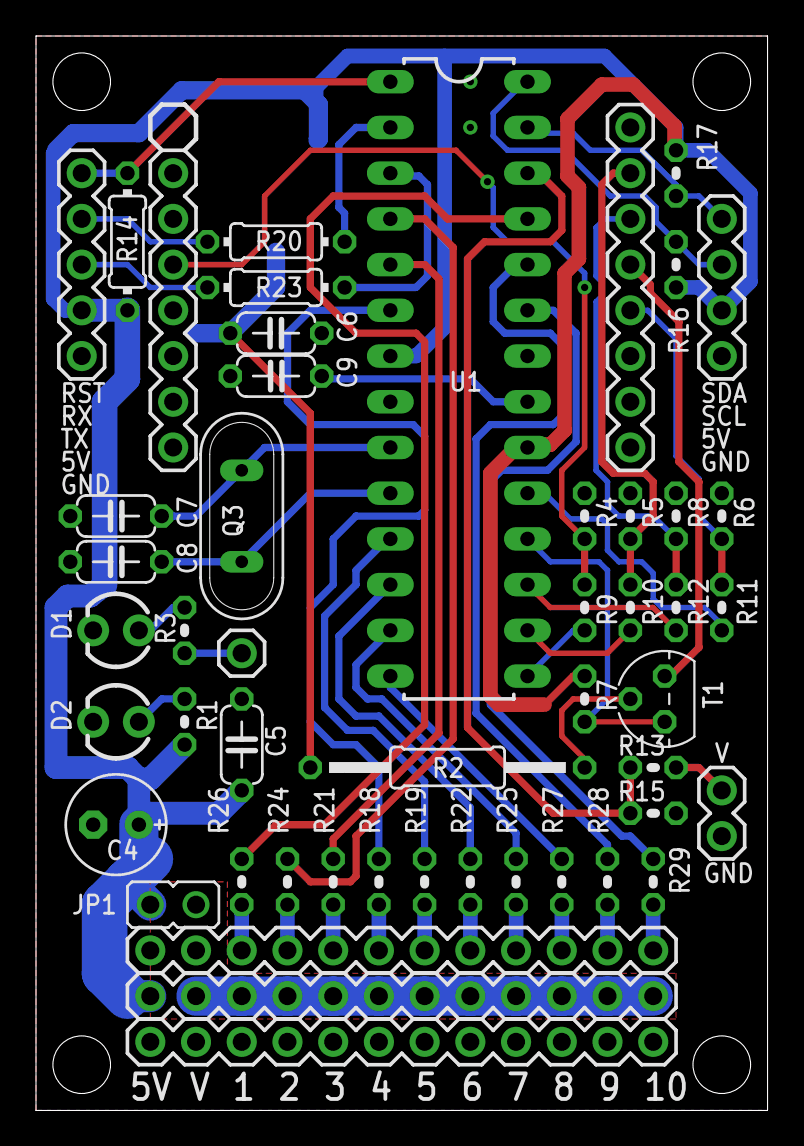
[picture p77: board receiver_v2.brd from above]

Board: 2 copper layers, 40.6 x 59.7 mm, 51 parts (1 on the bottom side), 50 nets.

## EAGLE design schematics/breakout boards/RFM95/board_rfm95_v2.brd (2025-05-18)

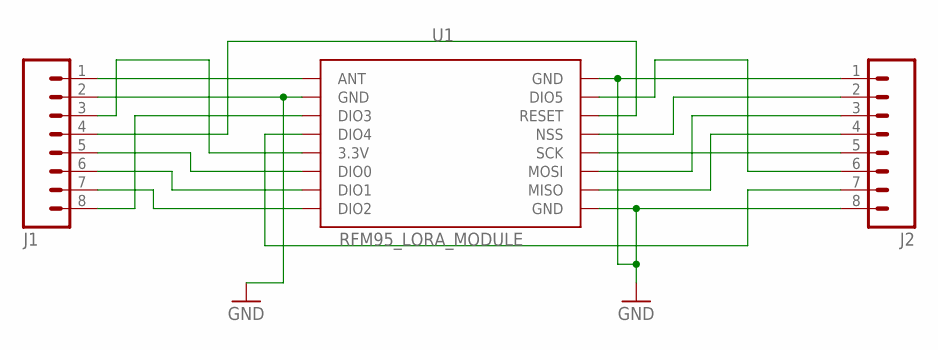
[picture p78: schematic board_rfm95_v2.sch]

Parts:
J1, J2: M08; 1X08_ROUND
U1: RFM95_LORA_MODULE; RFM95

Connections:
3.3V: J1.3, U1.3.3V
ANT: J1.1, U1.ANT
DIO0: J1.5, U1.DIO0
DIO1: J1.6, U1.DIO1
DIO2: J1.7, U1.DIO2
DIO4: J2.7, U1.DIO4
DIO5: J2.6, U1.DIO5
GND: J1.2, J2.1, J2.8, U1.GND, U1.GND@1 (GND), U1.GND@2 (GND)
MISO: J2.4, U1.MISO
MOSI: J2.3, U1.MOSI
unnamed: J1.8, U1.DIO3
NSS: J2.2, U1.NSS
RST: J1.4, U1.RESET
SCK: J2.5, U1.SCK

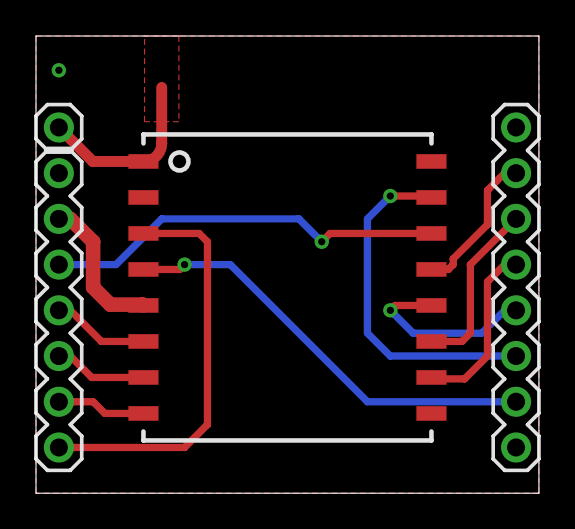
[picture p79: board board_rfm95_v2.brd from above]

Board: 2 copper layers, 27.9 x 25.4 mm, 3 parts (0 on the bottom side), 14 nets.

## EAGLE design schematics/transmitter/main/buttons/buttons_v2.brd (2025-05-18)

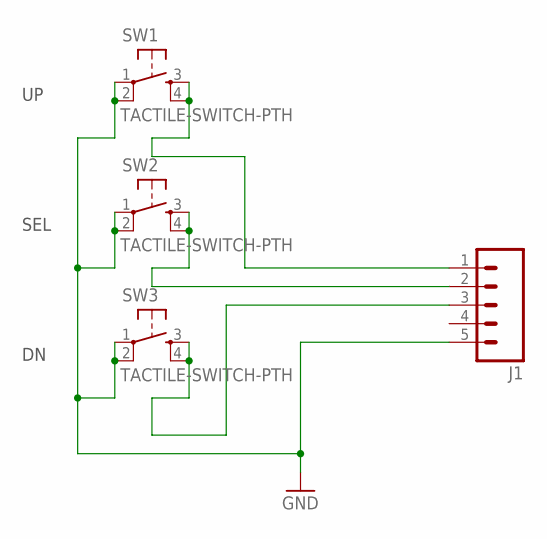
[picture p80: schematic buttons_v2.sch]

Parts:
J1: M05PTH; 1X05
SW1, SW2, SW3: TACTILE-SWITCH-PTH; TAC-SWITCH-PTH

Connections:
GND: J1.5, SW1.1, SW1.2, SW2.1, SW2.2, SW3.1, SW3.2
unnamed: J1.1, SW1.3, SW1.4
unnamed: J1.3, SW3.3, SW3.4
unnamed: J1.2, SW2.3, SW2.4

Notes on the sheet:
SEL

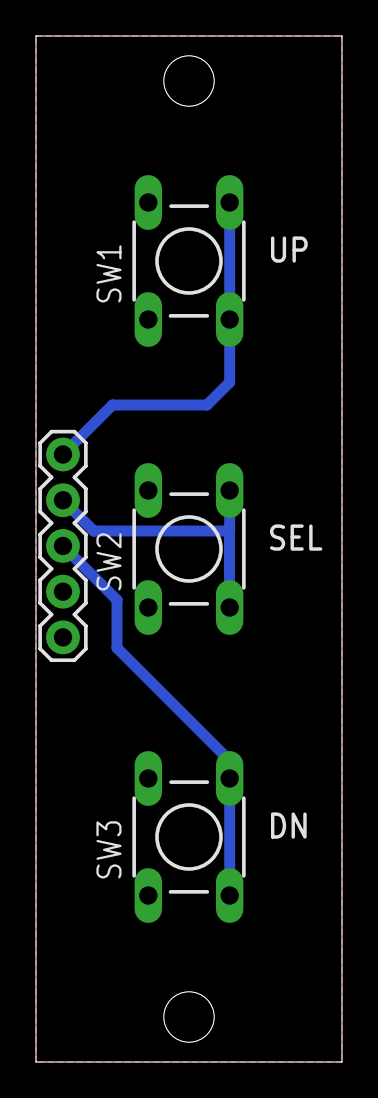
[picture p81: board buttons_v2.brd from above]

Board: 2 copper layers, 17.0 x 57.0 mm, 4 parts (0 on the bottom side), 4 nets.

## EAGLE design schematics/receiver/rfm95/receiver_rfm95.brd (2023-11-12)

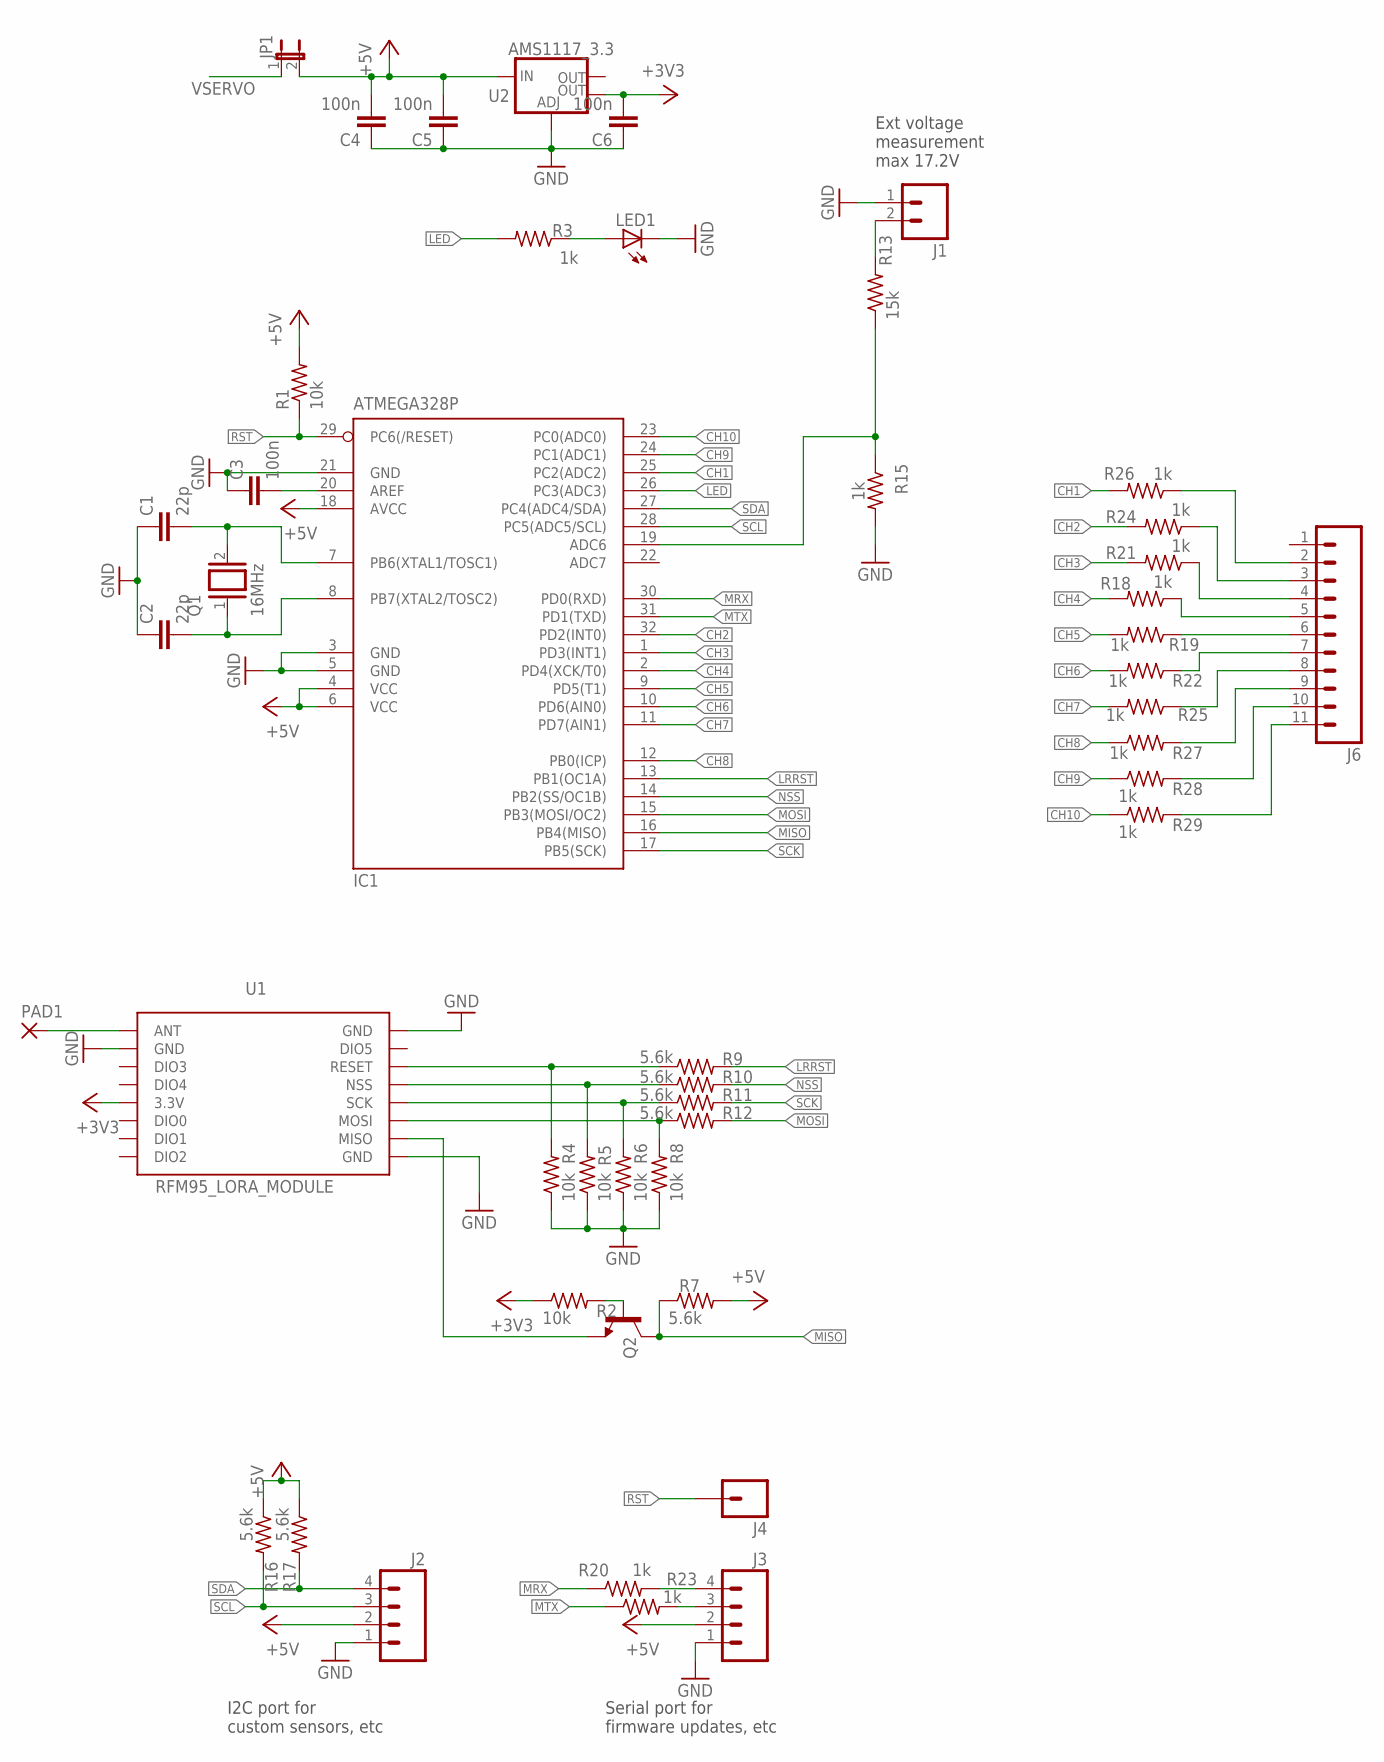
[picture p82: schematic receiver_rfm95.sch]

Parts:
C1, C2: 22p; C0805K
C3, C4, C5, C6: 100n; C0805K
IC1: ATMEGA328P; TQFP32-08
J1: M02PTH; 1X02
J2, J3: M04PTH; 1X04
J4: M01PTH; 1X01
J6: M11PTH; 1X11
JP1: JP1E; JP1
LED1: LEDCHIPLED_1206; CHIPLED_1206
PAD1: 2,15/1,0
Q1: 16MHz; QS
Q2: BC817-16SMD; SOT23-BEC
R1, R2, R4, R5, R6, R8: 10k; R0805
R3, R15, R18, R19, R20, R21, R22, R23, R24, R25, R26, R27, R28, R29: 1k; R0805
R7, R9, R10, R11, R12, R16, R17: 5.6k; R0805
R13: 15k; R0805
U1: RFM95_LORA_MODULE; RFM95
U2: AMS1117_3.3; SOT223

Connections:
+3V3: C6.2, R2.1, U1.3.3V, U2.4 (OUT)
+5V: C4.2, C5.2, IC1.4 (VCC), IC1.6 (VCC), IC1.18 (AVCC), J2.2, J3.2, JP1.2, R1.2, R7.2, R16.1, R17.1, U2.3 (IN)
CH1: IC1.25 (PC2(ADC2)), R26.2
CH2: IC1.32 (PD2(INT0)), R24.2
CH3: IC1.1 (PD3(INT1)), R21.2
CH4: IC1.2 (PD4(XCK/T0)), R18.2
CH5: IC1.9 (PD5(T1)), R19.2
CH6: IC1.10 (PD6(AIN0)), R22.2
CH7: IC1.11 (PD7(AIN1)), R25.2
CH8: IC1.12 (PB0(ICP)), R27.1
CH9: IC1.24 (PC1(ADC1)), R28.1
CH10: IC1.23 (PC0(ADC0)), R29.1
DIO3: U1.DIO3
GND: C1.1, C2.1, C3.1, C4.1, C5.1, C6.1, IC1.3 (GND), IC1.5 (GND), IC1.21 (GND), J1.1, J2.1, J3.1, LED1.C, R4.1, R5.1, R6.1, R8.1, R15.2, U1.GND, U1.GND@1 (GND), U1.GND@2 (GND), U2.1 (ADJ)
LED: IC1.26 (PC3(ADC3)), R3.2
LRRST: IC1.13 (PB1(OC1A)), R9.2
MISO: IC1.16 (PB4(MISO)), Q2.C, R7.1
MOSI: IC1.15 (PB3(MOSI/OC2)), R12.2
MRX: IC1.30 (PD0(RXD)), R20.1
MTX: IC1.31 (PD1(TXD)), R23.1
unnamed: C1.2, IC1.7 (PB6(XTAL1/TOSC1)), Q1.2
unnamed: J6.10, R28.2
unnamed: C2.2, IC1.8 (PB7(XTAL2/TOSC2)), Q1.1
unnamed: J6.9, R27.2
unnamed: R4.2, R9.1, U1.RESET
unnamed: R5.2, R10.1, U1.NSS
unnamed: R6.2, R11.1, U1.SCK
unnamed: R8.2, R12.1, U1.MOSI
unnamed: Q2.E, U1.MISO
unnamed: C3.2, IC1.20 (AREF)
unnamed: IC1.19 (ADC6), R13.1, R15.1
unnamed: J3.3, R23.2
unnamed: LED1.A, R3.1
unnamed: PAD1.1, U1.ANT
unnamed: J6.2, R26.1
unnamed: J3.4, R20.2
unnamed: J6.3, R24.1
unnamed: J6.4, R21.1
unnamed: J6.5, R18.1
unnamed: J6.6, R19.1
unnamed: J6.7, R22.1
unnamed: J6.8, R25.1
unnamed: Q2.B, R2.2
unnamed: J1.2, R13.2
unnamed: J6.11, R29.2
NSS: IC1.14 (PB2(SS/OC1B)), R10.2
RST: IC1.29 (PC6(/RESET)), J4.1, R1.1
SCK: IC1.17 (PB5(SCK)), R11.2
SCL: IC1.28 (PC5(ADC5/SCL)), J2.3, R16.2
SDA: IC1.27 (PC4(ADC4/SDA)), J2.4, R17.2
VSERVO: JP1.1

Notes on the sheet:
I2C port for custom sensors, etc
Serial port for firmware updates, etc
Ext voltage measurement max 17.2V



Board: 2 copper layers, 29.8 x 34.9 mm, 47 parts (25 on the bottom side), 49 nets.

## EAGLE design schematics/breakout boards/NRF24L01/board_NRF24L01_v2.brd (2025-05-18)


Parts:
J1, J2: M08; 1X08_ROUND
J3: M04X2; 2X4

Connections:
GND: J1.2, J2.1, J2.8, J3.1
unnamed: J1.3, J3.2
unnamed: J2.5, J3.5
unnamed: J2.4, J3.7
unnamed: J2.3, J3.6
unnamed: J1.4, J3.3
unnamed: J2.2, J3.4

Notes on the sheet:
VCC CSN MOSI IRQ
GND CE SCK MISO
GND CSN MOSI MISO SCK NC NC GND
NC GND 3V3 CE NC NC NC NC


Board: 2 copper layers, 27.9 x 25.4 mm, 3 parts (0 on the bottom side), 7 nets.

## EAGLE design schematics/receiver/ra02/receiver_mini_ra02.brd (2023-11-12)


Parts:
C1, C2: 22p; C0805K
C3, C4: 100n; C0805K
IC1: ATMEGA328P; TQFP32-08
J1: M05PTH; 1X05
PAD1: 2,15/1,0
Q1: 16MHz; QS
Q2: BC817-16SMD; SOT23-BEC
R1, R2, R3, R4, R5, R6: 10k; R0805
R7, R8, R9, R10, R11: 4.7k; R0805
R12: 1k; R0805
U2: AMS1117_3.3; SOT223
U3: RA-02_LORA_MODULE; RA-02

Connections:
+3V3: C4.2, R2.1, U2.4 (OUT), U3.3.3V
+5V: C3.2, IC1.4 (VCC), IC1.6 (VCC), IC1.18 (AVCC), J1.4, R1.2, R7.2, U2.3 (IN)
GND: C1.1, C2.1, C3.1, C4.1, IC1.3 (GND), IC1.5 (GND), IC1.21 (GND), J1.5, R3.1, R4.1, R5.1, R6.1, U2.1 (ADJ), U3.GND@2 (GND), U3.GND@3 (GND), U3.GND@4 (GND)
LRRST: IC1.13 (PB1(OC1A)), R8.1
MISO: IC1.16 (PB4(MISO)), Q2.C, R7.1
MOSI: IC1.15 (PB3(MOSI/OC2)), R11.2
unnamed: C1.2, IC1.7 (PB6(XTAL1/TOSC1)), Q1.2
unnamed: J1.3, R12.2
unnamed: C2.2, IC1.8 (PB7(XTAL2/TOSC2)), Q1.1
unnamed: R3.2, R8.2, U3.RESET
unnamed: PAD1.1, U3.GND
unnamed: Q2.E, U3.MISO
unnamed: R4.2, R9.1, U3.NSS
unnamed: R5.2, R10.1, U3.SCK
unnamed: R6.2, R11.1, U3.MOSI
unnamed: Q2.B, R2.2
NSS: IC1.14 (PB2(SS/OC1B)), R9.2
RST: IC1.29 (PC6(/RESET)), J1.1, R1.1
RX: IC1.30 (PD0(RXD)), J1.2
SCK: IC1.17 (PB5(SCK)), R10.2
TX: IC1.31 (PD1(TXD)), R12.1



Board: 2 copper layers, 20.0 x 26.0 mm, 23 parts (3 on the bottom side), 21 nets.

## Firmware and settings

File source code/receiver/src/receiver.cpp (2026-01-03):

#include "Arduino.h"
// #include <Servo.h> //replaced with modified library tailored to our application
#include "Servo.h"

#include "../config.h"
#include "crc.h"
#include "common.h"
#include "eestore.h"
#include "rfComm.h"
#include "GNSS.h"

//array of servo objects
Servo myServo[MAX_CHANNELS_PER_RECEIVER];

//output pins array
int16_t outputPin[MAX_CHANNELS_PER_RECEIVER] = {
  PIN_CH1,
  PIN_CH2,
  PIN_CH3, 
  PIN_CH4, 
  PIN_CH5, 
  PIN_CH6, 
  PIN_CH7, 
  PIN_CH8,
  PIN_CH9,
  PIN_CH10
};

//--------------- Function Declarations ----------

void writeOutputs();
void getExternalVoltage();
uint8_t getMaxSignalType(int16_t pin);
void getGNSSTelemetry();

//==================================================================================================

void setup()
{ 
  //--- setup pins
#ifdef PIN_LED
  pinMode(PIN_LED, OUTPUT);
  digitalWrite(PIN_LED, LOW);
#endif

#ifdef LEGACY_HARDWARE
  pinMode(PIN_PWR_LED, OUTPUT);
  digitalWrite(PIN_PWR_LED, HIGH);
#endif
  
  //--- use analog reference internal 1.1 V
  analogReference(INTERNAL);

  //--- Serial
  pinMode(0, INPUT_PULLUP); //prevent rx pin from floating and picking up random noise
  Serial.begin(9600);
  
  //--- initialise values
  for(uint8_t i = 0; i < MAX_CHANNELS_PER_RECEIVER; ++i)
  {
    channelOut[i] = 0;
    channelFailsafe[i] = 0;
    
    Sys.outputChConfig[i] = 0xA0;
    uint8_t maxSignalType = getMaxSignalType(outputPin[i]);
    Sys.outputChConfig[i] |= (maxSignalType << 2) & 0x0C;
    if(maxSignalType >= SIGNAL_TYPE_SERVOPWM) 
      Sys.outputChConfig[i] |= SIGNAL_TYPE_SERVOPWM & 0x03;
  }
  
  //--- delay
  delay(100);

  //--- EEPROM 
  eeStoreInit();
  eeReadSysConfig();
 
  //--- initialise radio module
  initialiseRfModule();
  
  //--- enter bind mode
  isRequestingBind = true;
}

//==================================================================================================

void loop()
{
  //--- COMMUNICATION
  doRfCommunication();

  //--- RC OUTPUTS
  writeOutputs();

  //--- EXTERNAL VOLTAGE
  getExternalVoltage();

  //--- GNSS TELEMETRY
  getGNSSTelemetry();
}

//==================================================================================================

void writeOutputs()
{
  static uint8_t prevSignalType[MAX_CHANNELS_PER_RECEIVER];
  static uint8_t prevServoPWMRangeIdx[MAX_CHANNELS_PER_RECEIVER];
  static bool    initialised[MAX_CHANNELS_PER_RECEIVER];
  static bool    failsafeActivated[MAX_CHANNELS_PER_RECEIVER];
  static bool    outputReinitialised[MAX_CHANNELS_PER_RECEIVER];
  
  bool activateFailsafe = ((millis() - lastRCPacketMillis) > 1000);

  if(!hasNewRCData && !activateFailsafe) //prevent unnecessary computation
    return;
  
  hasNewRCData = false;
  
  for(uint8_t i = 0; i < MAX_CHANNELS_PER_RECEIVER; i++)
  {
    if(!failsafeEverBeenReceived[i])
      continue;
 
    //--- SETUP OUTPUTS
    
    if(!initialised[i])
    {
      initialised[i] = true;
      prevSignalType[i] = 0xFF;
      prevServoPWMRangeIdx[i] = 0xFF;
      failsafeActivated[i] = false;
      outputReinitialised[i] = true;
    }
    
    uint8_t signalType = Sys.outputChConfig[i] & 0x03;
    
    uint8_t servoPWMRangeIdx = (Sys.outputChConfig[i] >> 4) & 0x0F;
    int16_t minMicroseconds = 500 + (servoPWMRangeIdx * 50);
    int16_t maxMicroseconds = 2500 - (servoPWMRangeIdx * 50);
    
    if(signalType != prevSignalType[i])
    {
      if(prevSignalType[i] == SIGNAL_TYPE_SERVOPWM)
        myServo[i].detach();
      else if(prevSignalType[i] == SIGNAL_TYPE_PWM)
        digitalWrite(outputPin[i], LOW);
        
      if(signalType == SIGNAL_TYPE_DIGITAL)
        pinMode(outputPin[i], OUTPUT);
      else if(signalType == SIGNAL_TYPE_SERVOPWM)
        myServo[i].attach(outputPin[i], minMicroseconds, maxMicroseconds);

      prevSignalType[i] = signalType;
    }
    
    if(signalType == SIGNAL_TYPE_SERVOPWM && servoPWMRangeIdx != prevServoPWMRangeIdx[i])
    {
      myServo[i].detach();
      myServo[i].attach(outputPin[i], minMicroseconds, maxMicroseconds);
      prevServoPWMRangeIdx[i] = servoPWMRangeIdx;
    }
    
    //--- HANDLE FAILSAFE
    
    if(activateFailsafe)
    {
      if(!failsafeActivated[i])
      {
        failsafeActivated[i] = true;
        outputReinitialised[i] = false;
        
        if(channelFailsafe[i] == 523) //Hold
        {
          //Nothing here. 
          //Receiver will continue outputting the last received value before signal was lost.
        }
        else if(channelFailsafe[i] == 522) //No Pulses
        {
          if(signalType == SIGNAL_TYPE_SERVOPWM)
          {
            myServo[i].detach();
            pinMode(outputPin[i], OUTPUT);
            digitalWrite(outputPin[i], LOW);
          }
          else if(signalType == SIGNAL_TYPE_PWM || signalType == SIGNAL_TYPE_DIGITAL)
            digitalWrite(outputPin[i], LOW);
        }
        else //Custom value
          channelOut[i] = channelFailsafe[i];
      }
    }
    else
    {
      failsafeActivated[i] = false;
      if(!outputReinitialised[i])
      {
        outputReinitialised[i] = true;
        if(signalType == SIGNAL_TYPE_SERVOPWM)
        {
          if(channelFailsafe[i] == 522) //only attach again for those with 'no pulses' specified
            myServo[i].attach(outputPin[i], minMicroseconds, maxMicroseconds);
        }
        else if(signalType == SIGNAL_TYPE_PWM || signalType == SIGNAL_TYPE_DIGITAL)
        {
          //Nothing here, No need.
        } 
      }
    }

    //--- WRITE OUTPUTS
    
    if(failsafeActivated[i] && channelFailsafe[i] == 522) //No pulse. Already handled
      continue;

    if(signalType == SIGNAL_TYPE_DIGITAL)
    {
      //range -500 to -250 is LOW, -250 to 250 is ignored, 250 to 500 is HIGH
      if(channelOut[i] <= -250)
        digitalWrite(outputPin[i], LOW);
      else if(channelOut[i] >= 250)
        digitalWrite(outputPin[i], HIGH);
    }
    else if(signalType == SIGNAL_TYPE_SERVOPWM)
    {
      int16_t val = map(channelOut[i], -500, 500, minMicroseconds, maxMicroseconds);
      // val = constrain(val, minMicroseconds, maxMicroseconds); //commented out for performance
      myServo[i].writeMicroseconds(val);
    }
    else if(signalType == SIGNAL_TYPE_PWM)
    {
      int16_t val = map(channelOut[i], -500, 500, 0, 255);
      // val = constrain(val, 0, 255); //commented out for performance
      analogWrite(outputPin[i], val);
    }
  }
}

//==================================================================================================

uint8_t getMaxSignalType(int16_t pin)
{
  uint8_t rslt = SIGNAL_TYPE_SERVOPWM; //assumed //TODO: Check within servo objects
  
  int16_t pwmPins[] = {5, 6, 3, 11}; //on arduino uno. Pins 9 and 10 omitted due to servo lib
  //search through array
  for(uint8_t i = 0; i < (sizeof(pwmPins)/sizeof(pwmPins[0])); i++)
  {
    if(pwmPins[i] == pin)
    {
      rslt = SIGNAL_TYPE_PWM;
      break;
    }
  }
  return rslt;
}

//==================================================================================================

void getExternalVoltage()
{
  /* 
  Apply smoothing to measurement using exponential recursive smoothing.
  It works by subtracting out the mean each time, and adding in a new point. 
  _NUM_SAMPLES parameter defines number of samples to average over. Higher value results in slower
  response.
  Formula x = x - x/n + a/n  
  */
  static uint32_t lastMillis = 0;
  if(millis() - lastMillis < 17)
    return;

  lastMillis = millis();
  
  const int16_t _NUM_SAMPLES = 32;
  int32_t millivolts = ((int32_t)analogRead(PIN_EXT_V_SENSE) * externalVfactor) / 64;
  millivolts = ((int32_t)externalVolts * (_NUM_SAMPLES - 1) + millivolts) / _NUM_SAMPLES; 
  externalVolts = int16_t(millivolts); 
}

//==================================================================================================

void getGNSSTelemetry()
{
  //The assumption is that the incoming serial data is being dealt with in a timely fashion. This requires
  //this function to be called frequently enough so that incoming data does not overflow the serial receive buffer.
  //For example at 9600 baud, a new byte comes in every 1.04 ms. Assuming this function is called every 20 ms,
  //then the maximum unread bytes we can accumulate is about 20. Thus the default 64 byte serial rx buffer is 
  //large enough.

  static char sentence[120];
  static uint8_t idxSentence = 0;

  static uint32_t lastMillis = 0;

  while(Serial.available())
  {
    char c = Serial.read();
    if(idxSentence < (sizeof(sentence) - 1))
    {
      sentence[idxSentence++] = c;
      if(c == '\n') //got a complete sentence, parse it
      {
        sentence[idxSentence] = '\0'; //add a null terminator
        parseNMEA(sentence);
        hasGNSSModule = true;
        lastMillis = millis();
        idxSentence = 0;
        break;
      }
    }
    else
      idxSentence = 0;
  }

  //detect disconnection of module
  if(hasGNSSModule)
  {
    if(millis() - lastMillis > 3000)
      hasGNSSModule = false;
  }
}

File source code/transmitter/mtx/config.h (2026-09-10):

/*
 * config.h
 *
 * Basic settings such as:
 * - LCD controller
 * - UI to use
 * - Pin mapping
 * - External EEPROM 
 *
 */

#ifndef _CONFIG_H_
#define _CONFIG_H_

#define _FIRMWARE_VERSION "1.4.5"

//===========================================================================
//============================= LCD and UI ==================================
//===========================================================================

#define UI_128X64
// #define UI_84X48  //not implemented

#define DISPLAY_KS0108
// #define DISPLAY_ST7920
// #define DISPLAY_PCD8544 //not implemented

//===========================================================================
//============================= Pins and ports ==============================
//===========================================================================

//Name                 Arduino Pin

#define PIN_X1_AXIS      A3
#define PIN_Y1_AXIS      A2
#define PIN_X2_AXIS      A0
#define PIN_Y2_AXIS      A1
#define PIN_X3_AXIS      A11
#define PIN_Y3_AXIS      A10
#define PIN_X4_AXIS      A13
#define PIN_Y4_AXIS      A12

#define PIN_Z1_AXIS      A9
#define PIN_Z2_AXIS      A8

#define PIN_KNOB_A       A4
#define PIN_KNOB_B       A5

#define PIN_BATTERY_VOLTS    A6

#define PIN_LCD_BACKLIGHT   2
#define PIN_SPEAKER         3

#define PIN_POWER_OFF_SENSE 12
#define PIN_POWER_LATCH     13

#define PIN_KEY_SELECT   8
#define PIN_KEY_UP       9
#define PIN_KEY_DOWN     7

#define PIN_KS_EN        15
#define PIN_KS_RS        14
#define PIN_KS_CS1       4
#define PIN_KS_CS2       39

#define PIN_ST_EN        15
#define PIN_ST_RS        14

//--- Direct port manipulation

#define DDRx_LCD_DATA    DDRA
#define PORTx_LCD_DATA   PORTA

#define DDRx_TRIMS   DDRL
#define PORTx_TRIMS  PORTL
#define PINx_TRIMS   PINL

//--- Physical switches

//Name             Arduino Pin
#define PIN_SWA_UP   37
#define PIN_SWA_DN   36

#define PIN_SWB_UP   35
#define PIN_SWB_DN   34

#define PIN_SWC_UP   33
#define PIN_SWC_DN   32

#define PIN_SWD_UP   31
#define PIN_SWD_DN   30

#define PIN_SWE_UP   10
#define PIN_SWE_DN   11

#define PIN_SWF_UP   41
#define PIN_SWF_DN   40

#define PIN_SWG_UP   61
#define PIN_SWG_DN   69

#define PIN_SWH_UP   5
#define PIN_SWH_DN   38

//--- SD card

#define PIN_SD_CS    53

//===========================================================================
//============================= External EEPROM =============================
//===========================================================================
//Maximum supported is a 512 kbit EEPROM

/* 
//--- 24LC512
//Total bytes (512*1024)/8 => 65536
#define EXTERNAL_EEPROM_TOTAL_BYTES     65536
#define EXTERNAL_EEPROM_PAGE_BYTES      32
#define EXTERNAL_EEPROM_DEVICE_ADDRESS  0x0
 */

//--- 24LC256
//Total bytes (256*1024)/8 => 32768
#define EXTERNAL_EEPROM_TOTAL_BYTES     32768
#define EXTERNAL_EEPROM_PAGE_BYTES      32
#define EXTERNAL_EEPROM_DEVICE_ADDRESS  0x0

#endif

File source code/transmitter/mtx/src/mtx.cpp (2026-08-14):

#include "Arduino.h"

#include "../config.h"
#include "common.h"
#include "crc.h"
#include "inputs.h"
#include "mathHelpers.h"
#include "mixer.h"
#include "ee/eestore.h"
#include "sd/sdStore.h"
#include "ui/ui.h"
#include "mtx.h"

uint32_t loopStartTime; //in microseconds

#define UART_FIXED_PACKET_SIZE 48

enum {
  MESSAGE_TYPE_NONE = 0x00,
  
  //mtx to stx
  MESSAGE_TYPE_RC_DATA = 0x01, 
  MESSAGE_TYPE_ENTER_BIND = 0X02,
  MESSAGE_TYPE_GET_RECEIVER_CONFIG = 0x03,
  MESSAGE_TYPE_WRITE_RECEIVER_CONFIG = 0x04,
  
  //stx to mtx
  MESSAGE_TYPE_BIND_STATUS_CODE = 0x10,
  MESSAGE_TYPE_RECEIVER_CONFIG = 0x11,
  MESSAGE_TYPE_RECEIVER_CONFIG_STATUS_CODE = 0x12,
  MESSAGE_TYPE_TELEMETRY_RF_LINK_PACKET_RATE = 0x13,
  MESSAGE_TYPE_TELEMETRY_GENERAL = 0x14,
  MESSAGE_TYPE_TELEMETRY_GNSS = 0x15,
};

//---------- Function declarations ---------------

void controlBacklight();
void doSerialCommunication();
void handleTelemetry();

//==================================================================================================

void setup()
{
  //set up ports and pins
  DDRx_TRIMS  = 0x00; //set port as input
  PORTx_TRIMS = 0xFF; //activate internal pullup resistors
  
  pinMode(PIN_KEY_SELECT, INPUT_PULLUP);
  pinMode(PIN_KEY_UP, INPUT_PULLUP);
  pinMode(PIN_KEY_DOWN, INPUT_PULLUP);
  
  pinMode(PIN_SPEAKER, OUTPUT);
  
  pinMode(PIN_POWER_OFF_SENSE, INPUT);
  pinMode(PIN_POWER_LATCH, OUTPUT);
  digitalWrite(PIN_POWER_LATCH, HIGH); //latch power
  
  initialiseSwitches();

  //initialise serial ports 
  Serial1.begin(115200); 
  
  //delay a bit to allow time for other devices to be ready
  delay(100);

  //initialise display
  initialiseDisplay();
  
  //set defaults
  resetSystemParams();
  resetModelName();
  resetModelParams();
  
  //start in silent mode if the Down key is held on boot
  bool isSilentMode = false;
  readSwitchesAndButtons();
  while(buttonCode == KEY_DOWN)
  {
    isSilentMode = true;
    turnOnBacklight();
    showMuteMessage();
    readSwitchesAndButtons();
    delay(30);
  }
  
  //Initialise EEPROM storage
  eeStoreInit();  //blocking
  
  //Load data from EEPROM
  eeReadSysConfig();
  eeReadModelData(Sys.activeModelIdx);
  
  if(isSilentMode)
    Sys.soundEnabled = false;
  
  //backlight
  if(Sys.backlightEnabled)
    analogWrite(PIN_LCD_BACKLIGHT, ((uint16_t) 255 * Sys.backlightBrightness) / 100);
  
  //Initialise battery reading
  batteryVoltsNow = Sys.batteryVoltsMax; 
  for(uint8_t i = 0; i < 100; i++)
  {
    checkBattery();
    delay(1);
  }

  //Welcome message
  if(Sys.showWelcomeMessage)
    showMessage(PSTR("Welcome"));
  
  uint32_t tt = millis();
  
  //Initialise SD card storage
  //moved here as it implicitly blocks for about 2 seconds when there is no SD card
  sdStoreInit();
  
  if(Sys.showWelcomeMessage)
  {
    tt = millis() - tt;
    if(tt < 1000)
      delay(1000 - tt);
  }
  
  //splash screen
  if(Sys.showSplashScreen)
    sdShowSplashScreen();
    
  //Warnings
  handleSafetyWarningUI(); //blocking
  
  //Initialise timers
  resetTimerRegisters();
  restoreTimerRegisters();
  
  //Initialise counters
  resetCounterRegisters();
  restoreCounterRegisters();
  
  //Other initialisations
  randomSeed(batteryVoltsNow);
  reinitialiseMixerCalculations();
  loopStartTime = micros();

}

//==================================================================================================

void loop()
{
  thisLoopNum++;

  ///--- SWITCHES, BUTTONS
  readSwitchesAndButtons();
  determineButtonEvent();
  
  ///--- STICKS 
  readSticks();
  
  ///--- COMPUTE OUTPUTS
  computeChannelOutputs();
  
  ///--- HANDLE MAIN INTERFACE
  handleMainUI();
  
  ///--- LAZY SAVE MODEL DATA TO EEPROM
  //Limit calling to about 10 times per second to prolong the EEPROM life.
  //Saving say 2400 bytes takes approximately 240 seconds (4 minutes) before starting over.
  //Without the limit, the same would take approximately 48 seconds, so if we let the system run
  //for 6 hours, we would be making 450 writes to a certain EEPROM cell, compared to 90 when limited.
  if(thisLoopNum % (100 / fixedLoopTime) == 0)
    eeLazyWriteModelData(Sys.activeModelIdx);

  ///--- LAZY SAVE SYSTEM DATA TO EEPROM
  //The cycle time set to about 5 minutes
  const uint32_t intervalMillis = 300000UL / sizeof(Sys); 
  if(thisLoopNum % (intervalMillis / fixedLoopTime) == 0)
    eeLazyWriteSysConfig();
  
  ///--- LIMIT MAX RATE OF LOOP
  //This is done here for a more consistent timing of communications.
  //Code section changed to use micros() instead of millis().
  //Rollover isn't a problem here. 
  uint32_t loopTime = micros() - loopStartTime;
  if(Sys.showLoopTime) //debug
    DBG_loopTime = loopTime;
  if(loopTime < (fixedLoopTime * 1000)) 
    delayMicroseconds((fixedLoopTime * 1000) - loopTime);
  loopStartTime = micros(); 

  ///--- COMMUNICATIONS
  doSerialCommunication();

  ///--- TELEMETRY
  handleTelemetry();
  
  ///--- CHECK BATTERY
  checkBattery();
  
  ///--- BACKLIGHT
  controlBacklight();
  
  ///--- HANDLE POWER OFF 
  handlePowerOff();
}

//==================================================================================================

void checkBattery()
{
  //Low pass filtered using exponential smoothing
  //As the implementation here uses integer math and the technique is recursive, 
  //there is loss of precision but this doesn't matter much here.
  const int16_t smoothFactor = 5; //>0,<100
  int32_t sample = ((int32_t)analogRead(PIN_BATTERY_VOLTS) * Sys.batteryCalibrationFactor) / 100;
  batteryVoltsNow = ((sample * smoothFactor) + ((100 - smoothFactor) * (int32_t)batteryVoltsNow)) / 100;
  if(batteryVoltsNow <= Sys.batteryVoltsMin)
    batteryState = BATTERY_LOW;
  else if(batteryVoltsNow > (Sys.batteryVoltsMin + 100)) //100 mV hysteresis
    batteryState = BATTERY_HEALTHY; 
}

//==================================================================================================

void turnOnBacklight()
{
  //Force the backlight to be on, irrespective of system settings
  analogWrite(PIN_LCD_BACKLIGHT, 76); //30% level
  backlightIsOn = true;
}

//==================================================================================================
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

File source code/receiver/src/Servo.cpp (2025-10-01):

/*
  Adapted by Buk, from the Arduino servo library.
  
  This library has been tailored to this project. 
  Changes made:
    - Stripped code to retain only AVR specific code that applies to the Atmega328.
    - Changed MIN_PULSE_WIDTH to 500, MAX_PULSE_WIDTH to 2500.
    - Using int16_t instead of int8_t for the private class members min and max.
    - Removed methods that we do not need for this application.
    - Replaced generic int types with fixed width types (int16_t, etc).
    - The writeMicroseconds() function will only disable interrupts and change the ticks value 
      if the value has actually changed. 
    
  Original copyright notice is below.
*/
  
/*
 Servo.cpp - Interrupt driven Servo library for Arduino using 16 bit timers- Version 2
 Copyright (c) 2009 Michael Margolis.  All right reserved.

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
 You should have received a copy of the GNU Lesser General Public
 License along with this library; if not, write to the Free Software
 Foundation, Inc., 51 Franklin St, Fifth Floor, Boston, MA  02110-1301  USA
 */


#include <avr/interrupt.h>
#include <Arduino.h>

#include "Servo.h"

#define usToTicks(_us)  ((clockCyclesPerMicrosecond()* _us) / 8) // converts microseconds to tick (assumes prescale of 8)
#define TRIM_DURATION   2  // compensation ticks to trim adjust for digitalWrite delays

static servo_t servos[MAX_SERVOS];  // static array of servo structures
static volatile int8_t Channel[_Nbr_16timers ];  // counter for the servo being pulsed for each timer (or -1 if refresh interval)

uint8_t ServoCount = 0; // the total number of attached servos


// convenience macros
#define SERVO_INDEX_TO_TIMER(_servo_nbr) ((timer16_Sequence_t)(_servo_nbr / SERVOS_PER_TIMER)) // returns the timer controlling this servo
#define SERVO_INDEX(_timer,_channel)  ((_timer*SERVOS_PER_TIMER) + _channel)  // macro to access servo index by timer and channel
#define SERVO(_timer,_channel)  (servos[SERVO_INDEX(_timer,_channel)])   // macro to access servo class by timer and channel

#define SERVO_MIN() (MIN_PULSE_WIDTH - this->min * 4)  // minimum value in us for this servo
#define SERVO_MAX() (MAX_PULSE_WIDTH - this->max * 4)  // maximum value in us for this servo

/************ static functions common to all instances ***********************/

static inline void handle_interrupts(timer16_Sequence_t timer, volatile uint16_t *TCNTn, volatile uint16_t* OCRnA)
{
  if(Channel[timer] < 0)
    *TCNTn = 0; // channel set to -1 indicated that refresh interval completed so reset the timer
  else
  {
    if(SERVO_INDEX(timer,Channel[timer]) < ServoCount && SERVO(timer,Channel[timer]).Pin.isActive)
      digitalWrite(SERVO(timer,Channel[timer]).Pin.nbr, LOW); // pulse this channel low if activated
  }

  Channel[timer]++;    // increment to the next channel
  if(SERVO_INDEX(timer,Channel[timer]) < ServoCount && Channel[timer] < SERVOS_PER_TIMER) 
  {
    *OCRnA = *TCNTn + SERVO(timer,Channel[timer]).ticks;
    if(SERVO(timer,Channel[timer]).Pin.isActive)     // check if activated
      digitalWrite(SERVO(timer,Channel[timer]).Pin.nbr, HIGH); // its an active channel so pulse it high
  }
  else 
  {
    // finished all channels so wait for the refresh period to expire before starting over
    if(((unsigned)*TCNTn) + 4 < usToTicks(REFRESH_INTERVAL))  // allow a few ticks to ensure the next OCR1A not missed
      *OCRnA = (uint16_t) usToTicks(REFRESH_INTERVAL);
    else
      *OCRnA = *TCNTn + 4;  // at least REFRESH_INTERVAL has elapsed
    Channel[timer] = -1; // this will get incremented at the end of the refresh period to start again at the first channel
  }
}

ISR(TIMER1_COMPA_vect)
{
  handle_interrupts(_timer1, &TCNT1, &OCR1A);
}

static void initISR(timer16_Sequence_t timer)
{
  if(timer == _timer1) 
  {
    TCCR1A = 0;              // normal counting mode
    TCCR1B = _BV(CS11);      // set prescaler of 8
    TCNT1 = 0;               // clear the timer count
    TIFR1 |= _BV(OCF1A);     // clear any pending interrupts
    TIMSK1 |=  _BV(OCIE1A); // enable the output compare interrupt
  }
}

static boolean isTimerActive(timer16_Sequence_t timer)
{
  // returns true if any servo is active on this timer
  for(uint8_t channel = 0; channel < SERVOS_PER_TIMER; channel++) 
  {
    if(SERVO(timer,channel).Pin.isActive)
      return true;
  }
  return false;
}

/****************** end of static functions ******************************/

Servo::Servo()
{
  if(ServoCount < MAX_SERVOS) 
  {
    this->servoIndex = ServoCount++;  // assign a servo index to this instance
    servos[this->servoIndex].ticks = usToTicks(DEFAULT_PULSE_WIDTH); // store default values
  }
  else
    this->servoIndex = INVALID_SERVO;  // too many servos
}

uint8_t Servo::attach(int16_t pin)
{
  return this->attach(pin, MIN_PULSE_WIDTH, MAX_PULSE_WIDTH);
}

uint8_t Servo::attach(int16_t pin, int16_t min, int16_t max)
{
  if(this->servoIndex < MAX_SERVOS) 
  {
    pinMode(pin, OUTPUT);
    servos[this->servoIndex].Pin.nbr = pin;
   
    this->min  = (MIN_PULSE_WIDTH - min)/4; //resolution of min/max is 4 us
    this->max  = (MAX_PULSE_WIDTH - max)/4;
    // initialize the timer if it has not already been initialized
    timer16_Sequence_t timer = SERVO_INDEX_TO_TIMER(servoIndex);
    if(!isTimerActive(timer))
      initISR(timer);
    servos[this->servoIndex].Pin.isActive = true;
  }
  return this->servoIndex;
}

void Servo::detach()
{
  servos[this->servoIndex].Pin.isActive = false;
}

void Servo::writeMicroseconds(int16_t value)
{
  // calculate and store the values for the given channel
  uint8_t channel = this->servoIndex;
  if(channel < MAX_SERVOS)
  {
    if(value < SERVO_MIN())
      value = SERVO_MIN();
    else if(value > SERVO_MAX())
      value = SERVO_MAX();

    value = value - TRIM_DURATION;
    value = usToTicks(value);  // convert to ticks after compensating for interrupt overhead
    
    if(servos[channel].ticks != (uint16_t) value)
    {
      uint8_t oldSREG = SREG;
      cli();
      servos[channel].ticks = value;
      SREG = oldSREG;
    }
  }
}

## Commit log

2023-11-14 Minor enhancement in telemetry sensor stats screen. (#1)
    * Update common.h
    * Update common.cpp
    * Update mtx.cpp
    * Update mixer.cpp
    * Update ui_128x64.cpp
2023-11-14 Make use of the LED in the receiver
2023-12-16 Update LCDKS0108.cpp
    Slight speed gains in LCD driver
2023-12-18 Update ui_128x64.cpp
    Add scroll bar in throttle curve screen
2023-12-20 Update LCDKS0108.cpp
    Fixed minor glitch in drawHLine and drawVLine
    [LCDKS0108.cpp]
2023-12-26 Minor improvements
    Using multipliers that are powers of 2 to take advantage of compiler optimizations
2024-01-13 Update ui_128x64.cpp
    Refined battery gauge
2024-01-14 Update ui_128x64.cpp
    - Added option to display transmitter battery voltage as numerical or gauge on home screen.
2024-02-22 Update mtx.cpp
    - Fixed minor issue in telemetry stats
    [mtx.cpp]
2024-02-22 Update mixer.cpp
    - Fixed issue in the logical switches when the operand is a countdown timer.
2024-02-22 Update ui_128x64.cpp
    - Other minor improvements.
    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
2024-03-10 Minor improvements (#14)
    - Redesigned home screen
    * Update bitmaps.h
    * Add files via upload
    * Add files via upload
    * Add files via upload
    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
    [common.h]
2024-03-16 Update uiCommon.cpp
    - Prevent nuisance screenshots when setting up a switch to use
2024-04-21 Minor improvements (#18)
    * Update config.h
    * Update eestore.h
    * Update eestore.cpp
    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
    [transmitter.sch]
2024-07-08 Update inputs.cpp
    Fixed nuisance beeps when calibrating knobs.
    [inputs.cpp]
2024-07-17 Various improvements and fixes (#23)
    * Update mtx.ino
    * Update stringDefs.h
    * Update stringDefs.cpp
    * Update mixer.h
    * Update ui.h
    * Update LCDKS0108.h
    * Update uiCommon.h
    * Update tonePlayer.cpp
    * Update modelImport.cpp
    * Update modelExport.cpp
    * Update uiCommon.cpp
    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
    [slow_func.xlsx]
2024-08-05 Minor improvements and fixes (#29)
    * Update rfComm.cpp
    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
    [timing_failsafe_telemetry.xlsx]
2024-08-07 Minor improvements (#30)
    - Moved evaluations of logical switches and counter to before the mixer loop.
    - Added ability to move/reorder logical switches.
    - Added ability to move/reorder logical switches.
    - Added ability to move/reorder logical switches. References get updated on moving.
    - Added ability to move/reorder logical switches. References get updated on moving.
    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
2024-09-04 Update inputs.cpp
    - Fix minor issue with knob center tone.
    [inputs.cpp]
2024-09-04 Update ui_128x64.cpp
    - Fix issue where model type could not be changed if there was only one model slot (no external eeprom)
2024-09-05 Update ui_128x64.cpp (#33)
    - Delay writing to EEPROM for model actions, when there is only a single model slot to work with (i.e. no external eeprom).
2024-09-06 - Minor improvements (#34)
    - Minor improvements in stick and knob calibration screens.
    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
2024-09-06 Revert "- Minor improvements (#34)" (#35)
    This reverts commit 966b330f4170debff45a9f668b74e7b5412d65ef.
    [eestore.cpp]
2024-09-06 Minor improvements and fixes (#36)
    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
    [eestore.cpp]
2024-09-07 Add files via upload
    - Update annotations in schematics.
    [transmitter.sch]
2024-09-09 Update ui_128x64.cpp
    - Fixed issue where the controls calibration flag was sometimes not being reset when the calibration was complete, causing the mixer to pause indefinitely.
2024-09-16 Minor improvements and fixes (#38)
    * Update templates.cpp
    * Update font.cpp
    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
    [stringDefs.cpp]
2024-09-29 Minor improvements (#39)
    * Update stx.cpp
    * Update receiver.cpp
    * Update receiver_config.md
    * Update protocol_over_rf.txt
    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
    [servo_PWM_range_LUT.xlsx]
2024-09-29 Update Servo.h
    Just some cosmetics
2024-09-29 Update Servo.cpp
    Just some little cosmetics
2024-09-30 Minor improvements (#40)
    Added trims as control switches
    Added trims as control switches
    Added trims as control switches
    Added trims as control switches
    Improved trim center tone
    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
2024-10-12 Update Servo.cpp
    In writeMicroseconds() function, only disable interrupts and change the ticks value if the value has actually changed.
2024-10-24 Minor improvements and fixes. (#42)
    More checks for corrupt system data and model data
    * Update GFX.cpp
    * Update LCDKS0108.cpp
    Removed stale comments
    * Update about.h
    Added support for page break (form feed)
    Added support for page break in the generic text viewer.
    Other minor clean-up.
    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
    [LCDKS0108.cpp, common.h, eestore.cpp]
2024-11-30 Various improvements and fixes. (#43)
    * Update templates.h
    * Update mathHelpers.h
    * Update mathHelpers.cpp
    * Update inputs.cpp
    * Update sdStore.cpp
    * Update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
    [common.h, config.h, eestore.cpp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]
2024-12-05 Various improvements and fixes (#44)
    Moved persistent GNSS telemetry data to Model memory, and not System.
    * Update receiver.ino
    * Update mixer.md
    * Update protocol_over_uart.txt
    * Update telemetry.md
    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
    [timing_failsafe_telemetry.xlsx]
2024-12-06 Minor improvements (#45)
    Fixed bug where garbage serial data could prevent further parsing of GNSS NMEA sentences.
    * Delete source code/receiver/GPS.cpp
    * Delete source code/receiver/GPS.h
    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
    [receiver.cpp, rfComm.cpp]
2024-12-08 Update receiver.cpp
    Function getExternalVoltage() optimized with dividers that are powers of 2, saved some 68 microseconds.
2024-12-20 Update rfComm.cpp
    - Fixed minor issue in bind mode, where the system would prematurely revert to the previous RF power level
    setting before fully exiting bind mode.
    [rfComm.cpp]
2024-12-21 Update ui_128x64.cpp
    - Minor improvements in the GNSS telemetry sensor context menus.
2025-01-25 Various improvements. (#46)
    - Improved support for momentary switches
    Improved support for momentary switches.
    - Added proper support for momentary switches.
    - Added option to lock menu after inactivity.
    - Turn off inactivity sound without affecting inactivity duration.
    - Show notification settings even when the notification is disabled.
    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
2025-01-30 Improved documentation (#48)
    * Delete assets/screens/combined.png
    * Delete doc directory
    * Update README.md
    * Update custom_curves.md
    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
    [slow_func.xlsx]
2025-01-30 Minor improvements (#49)
    - When playing audio from trim keys, treat them as generic switches if they are disabled for trim adjustments.
    - Removed restriction on using trims and flight modes as control switches. They can now be used anywhere.
    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
2025-02-04 Update ui_128x64.cpp
    - Improve key filtering for backlight on the home screen.
2025-02-06 Update mtx.cpp
    - Prevent trim keys from triggering on the backlight when backlight wakeup condition is set to "Keys".
    [mtx.cpp]
2025-05-18 Enhancements: ST7920 LCD Support, Documentation and schematics updates, minor fixes and improvements. (#51)
    * Update readme.md
    * Delete assets/Bm437_Portfolio_6x8_modBUK.FON
    * Update readme.txt
    * Update readme.txt
    * Delete schematics directory
    Added support for ST7920 based LCD.
    Added support for ST7920 based LCD.
    - Added support for ST7920 based LCD.
    - Fixed minor bug in when showing tool-tip in mixer monitor screen, when the output is none.
    - Added support for ST7920 LCD.
    - Other minor improvements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
    [LCD_performance_KS0108_vs_ST7920.xlsx, board_NRF24L01_v2.brd, board_NRF24L01_v2.sch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]
2025-07-18 Fix typos (#52)
    Fix typos
    Fix typos
    Fix typos
    Fix typos
    Fix typos
    Fix typos
    Fix typos
    Fix typos
    Fix typos
    Fix typos
    Fix typos
    Fix typos
    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
    [common.h, config.h, inputs.cpp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]
2025-08-07 Fix typos in comments (#54)
    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
    [LCDKS0108.cpp, common.h, inputs.cpp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]
2025-08-09 Update receiver.cpp
    Fix typos.
    [receiver.cpp]
2025-08-09 Update rfComm.cpp
    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
    [rfComm.cpp]
2025-08-09 Update config.h
    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
    [config.h]
2025-09-13 Update mixer.cpp
    - Improved the resolution (samples per cycle and depth) of the generated sine waveform in the function generator.
2025-12-25 Minor improvements (#60)
    - Some memory savings in the UI code.
    - Increased default telemetry sensor slots from 6 to 8.
    - Added User guide in PDF and ODT formats.
2025-12-28 Minor improvements (#61)
    - Fixed minor issue where resetting the GNSS Altitude AGL or Starting point did not automatically reset
    the corresponding telemetry sensor statistics (maximum and minimum).
    [config.h]
2026-03-25 Minor improvements (#64)
    - Added backup and restore of system settings to/from the SD card.
    - Enabled restoring system settings during initial setup.
    - Disabled key-press sounds by default.
    - Other minor improvements and fixes.
    [common.h, mtx.cpp]
2026-05-18 Update ui_128x64.cpp
    Improved the stick and knob calibration screens.
2026-07-15 Various improvements and fixes. (#68)
    - Added support for various units of measurement in the GNSS telemetry data screen.
    - Improved conformance to the 8.3 filename convention when backing up models to the SD card.
    - Fixed an issue where GNSS telemetry data was not being reset on model change.
    - Fixed an issue in the Gauge widget type, where it could not graph telemetry sensors having large values.
    - Reduced the likelyhood of being stuck in infinite do while loops in the UI when we have corrupt model data
    and are trying to edit values. The corrupt data could have somehow slipped through the sanity checker.
    - Updated and improved the documentation.
    [common.h, config.h, mtx.cpp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]
2026-07-19 Update LCDKS0108.cpp
    - Fix typos.
    [LCDKS0108.cpp]
2026-07-19 Update mtx.cpp
    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
    [mtx.cpp]
2026-08-08 Update uiCommon.cpp
    - Fixed minor issue in automatic selection of the moved source. Only assign trims if the trim button is actually being pushed, to prevent false detection when the value changes due to changing the flight mode.
2026-08-14 Various improvements and fixes (#70)
    - Added option to adjust the long press delay. Removed the hard-coded value.
    - Added option to adjust the key repeat interval. Removed the hard-coded value.
    - Changed the default key repeat interval to 160 milliseconds. The earlier 120 milliseconds is a bit too fast, often resulting in overshooting the target.
    - Fixed minor issues in the horizontal scrolling feature for long text. Changed the scroll speed from 5 characters to about 4 characters per second, due to ghosting on the LCD.
    - Undo previous setting where we turned off key-press sounds by default.
    - Improved the incDec() function.
    - Major menus now also support horizontal scrolling for long text.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
    [common.h, inputs.cpp, mtx.cpp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]
2026-09-25 Minor improvements (#73)
    -Improved the warning message shown when importing unrecognised data. The displayed message is now less alarmist.
    -Removed the unnecessary warning in the switches screen under system settings.
    -Removed some more redundant variables in the source code.
2026-10-24 Fixed incorrect resistor values.
    - Fixed incorrect resistor values in the level shifters.
    - Fixed a mistake in the silk screen where the R4 and R9 label positions where swapped.
2026-10-24 Fixed incorrect resistor values.
    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
2026-10-24 Fixed incorrect resistor values
    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
2026-10-24 Various improvements and fixes (#74)
    - Added option to adjust the fixed loop time. Removed the hard-coded value.
    - Redesigned the system menu. Disbanded the Advanced sub-menu, moved the About sub-menu to the main menu.
    - Improved the timings for failsafe, telemetry, and when binding. Significantly reduced the delay between switching on the receiver and getting the very first signal on the output pin. This fixes an issue where certain ESCs sometimes fail to respond to the throttle signal.
    - The SPI clock frequency can now be specified in the config.h files. This fixes an issue with some level shifters not supporting very high speeds.
    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
2026-11-14 Minor improvements (#76)
    - Replaced the Arduino's random() with own random generator implementation.
    - Show the transmitter ID and receiver ID in the debug statistics.

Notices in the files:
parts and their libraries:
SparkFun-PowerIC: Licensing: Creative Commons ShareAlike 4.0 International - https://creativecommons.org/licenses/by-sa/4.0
